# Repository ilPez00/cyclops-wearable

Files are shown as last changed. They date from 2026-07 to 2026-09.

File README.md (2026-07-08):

# Cyclops

A wearable AI note-taker: XIAO ESP32-S3 Sense HUD (screen + wheel + buttons +
gyro) that captures audio, sends it to a "brain" (Python) for transcription and
smart-note extraction, and displays glanceable notes back on the device, or
forwards them to EvenRealities G2 glasses / Omi-Pebble style HUDs.

Inspired by feature sets from EvenRealities G2 (HUD glasses: navigation,
translation, notification, teleprompt, music, glanceable text) and the
Omi / Pebble wearable (24/7 audio, transcription, memory, app, web).

## Layout
```
protocol/   wire protocol spec (device <-> brain)
device/     C++ firmware (XIAO) + host simulator + battery + gestures + CLI
brain/      Python: transcriber, extractor, store, pipeline, display sinks
app/        stdlib web dashboard (no pip needed)
tests/      zero-dep test runner (run_tests.py)
firmware/   PlatformIO project for seeed_xiao_esp32s3 (+ native test env)
demo.py     end-to-end demo (audio -> notes -> screen)
```

## Run (no hardware, no pip, no API keys)
```
python3 tests/run_tests.py tests/test_brain.py tests/test_device.py
python3 demo.py
python3 device/cli.py g2        # glasses variant
python3 device/cli.py pebble    # omi-pebble variant
python3 app/server.py 8080      # web dashboard
```

## Features
- Wire protocol with CRC framing (C++ + Python mirrors).
- Local-first transcription: faster-whisper if installed, else deterministic stub.
- Smart-note extraction: task / reminder (due-date parsing) / decision / idea / summary.
- Display sinks: local HUD (DISPLAY_CMD frames), G2 glasses (NOTE frames), console.
- Input: scrollwheel, 2 buttons, gyro gestures (nod/shake).
- Battery monitor + low-power flag.
- Persistence: JSONL + Markdown export. Web dashboard.
- Three variants: local (XIAO HUD), g2 (glasses), pebble (audio-first).

## Build firmware
```
pio run -e seeed_xiao_esp32s3     # flash to XIAO
pio run -e native                 # host unit-test build
```
(PlatformIO optional; the C++ is verified host-side via g++ already.)

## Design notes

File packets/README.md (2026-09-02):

# cyclops-wearable work packets (device + brain + app + firmware)

Read PROTOCOL.md first. Repo-specific rules:

- **Canonical repo is THIS one** (github.com/ilPez00/cyclops-wearable, branch
  main). The sibling clone ~/dev/cyclops (feather) points at a LOCAL git
  mirror and sat on branch freerouting-omniroute — that is CY-000's problem,
  not a licence to push there.
- Verification is three-gated and all three exist: `python3 tests/run_tests.py
  tests/test_*.py` (zero-dep; 238 passing at last count), `make test` +
  `make proto` (firmware host gates), `pio run` (PlatformIO device builds).
  Never weaken the wire-contract tests (C++/Python byte-identical framing,
  ADPCM contract) — they are the reason on-metal bring-up worked.
- Hardware facts that took a session to learn (STATUS.md 2026-07-12): mic is
  PDM only (clk GPIO42, data GPIO41); BLE notify throughput ~2 KB/s drove the
  ADPCM decision; missing screen/IMU/SD must degrade gracefully.
- No pip, no API keys for the core test path — zero-dependency is a feature.
- Consent gating for incoming device commands (phone drives capture/HUD) is a
  trust boundary, not a UX nicety.

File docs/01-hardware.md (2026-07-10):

# Cyclops — Hardware

> **RECONSTRUCTED DOC** — original `docs/01-hardware.md` lived only on the
> corrupted `/dev/sde2` mount (2026-07-07) and was never bundled. Rebuilt
> 2026-07-10 from `firmware/xiao/src/main.cpp`, `docs/22-screens-plan.md`,
> `docs/30-colmi-r02-integration.md`, `docs/21-architecture-v2.md` and the
> `README.md`. Sections marked **[inferred]** are reconstructions — verify on
> metal before trusting.

## 0. Two MCUs, one design

Cyclops firmware targets two MCUs through a shared `cyclops_shared` lib:

| MCU | Role | Build envs |
|-----|---|---|
| **XIAO ESP32-S3 Sense** | wearable HUD + I2S mic + NimBLE | `xiao_st7735` `xiao_128x64` `xiao_128x32` |
| **Arduino Uno / Nano** | bench/teaching HUD (no BLE/mic) | `arduino_st7735` `arduino_128x64` `arduino_128x32` |

XIAO is the real wearable. Arduino proves the HUD logic on 2 KB RAM hardware.

## 1. XIAO ESP32-S3 Sense — spec

- dual-core Xtensa LX7 @ 240 MHz, 8 MB PSRAM, 8 MB flash (seeed_xiao_esp32s3).
- Onboard: OV2640 cam (QVGA), I2S MEMS mic (pads 40/41/42), 6-axis IMU
  (gyro + accel, for nod/shake gestures), Li-Po charge circuit.
- Wireless: WiFi + BLE 4.2 (NimBLE). SPI on GPIO 1/2/7/8/9/10.
- USB-C: power + data + flashing (UF2 / PlatformIO).

## 2. Displays (one of three, compile-selected)

From `22-screens-plan.md`, all three wrap Adafruit drivers behind a header-only
`Screen` base (`shared/include/screen.h`). Resolution-agnostic: `char_cols()` /
`text_rows()` drive layout; no fixed 4×22 buffer forced on big panels.

| Panel | Res | driver | XIAO CS | Arduino CS |
|---|-----|---|---|---|
| ST7735 | 128×128 RGB565 | `St7735Screen` | D7 | 10 |
| SSD1306 128×64 | 128×64 1bpp | `Ssd1306_128x64_Screen` | D6 | 7 |
| SSD1306 128×32 | 128×32 1bpp | `Ssd1306_128x32_Screen` | D5 | 4 |

Mono panels: white-on-black. ST7735: green-on-black. DC=D2, RST=D1 (shared).

## 3. XIAO pin map (verified by compile)

```
  XIAO ESP32-S3 Sense          Function              Notes
  ─────────────────────────────────────────────────────────────────────
  D0  ── wheel A (quad)        scroll input          INT on CHANGE
  D4  ── wheel B (quad)        scroll input
  D3  ── BTN_A (pull-up)      select (short) / back (long >600 ms)
  D5  ── BTN_B (pull-up)      cancel / back one level   (was D4; moved to free GPIO5)
  D8  ── SPI SCK               screen (VSPI)
  D10 ── SPI MOSI              screen
  D9  ── SPI MISO              screen
  D7/D6/D5 ── screen CS        (panel-selected, see §2)
  D2  ── screen DC             all panels
  D1  ── screen RST            all panels
  40/41/42 ── I2S BCLK/WS/DIN mic capture (onboard pad)
  5V / GND ── USB-C            power + data + charge
  BAT (pad) ── Li-Po + (optional)   untethered runtime
```

**BUG fixed (HUD/UX doc):** `PIN_BTN_B` was GPIO4 == `PIN_WHEEL_B` (4) — confirm/
cancel and wheel were aliased, breaking menu/back. Moved to GPIO5 (verified free:
SPI uses 1/2/7/8/9/10, mic 40/41/42). Done in `main.cpp`.

## 4. COLMI R02 ring (health/gesture sensor)

Sealed $20 BLE smart ring. No solder — "wiring" = establishing the BLE GATT
link (`30-colmi-r02-integration.md`). 17 mAh cell, ~5 days, magnetic pogo
charge. Feeds HR / SpO2 / battery / steps / gestures to the XIAO HUD via
`RingBle` (NimBLE central, `-DENABLE_RING`).

## 5. Power

- **Tethered dev:** USB-C 5 V. No battery circuit needed.
- **Untethered wearable:** 3.7 V Li-Po → `BAT` pad through charge/protect;
  XIAO's onboard charger tops from USB-C. Keep total draw **< 300 mA**
  (ESP32 + screen + mic + ring BLE client).

## 6. Build matrix (verified green)

| env | RAM | Flash | status |
|-----|-----|---|---|
| arduino_st7735 | 59.3% | 55.5% | OK |
| arduino_128x64 | 67.9% | 62.8% | OK |
| arduino_128x32 | 67.9% | 62.8% | OK |
| xiao_st7735 | 9.3% | 15.8% | OK |
| xiao_128x64 | 9.4% | 16.2% | OK |
| xiao_128x32 | 9.4% | 16.2% | OK |

Uno + ST7735 uses no full framebuffer (Adafruit draws direct); 128×64 = 1 KB,
128×32 = 512 B controller RAM — all fit 2 KB. Decoder buffer shrunk 1024→256
to fit Uno RAM.

## 7. Not yet on metal (headless-unverifiable)

- Real I2S mic + OLED bench test (only Arduino/XIAO envs compile; native_test
  used for logic).
- Live BLE connect to a physical R02 / G2 (no ring/glasses on the bench).
- `pio run -e xiao_*` flash + field test (PlatformIO not installed locally;
  CI compiles the firmware).
- Vibration-motor feedback, low-batt auto-sleep, gyro gesture calibration.

---
**[inferred]** The exact "two MCU" framing, the §6 RAM/flash table and the
§3 pin note about the BTN_B bug are taken from committed `main.cpp` +
`22-screens-plan.md` and should be accurate. The "bench/teaching" description of
the Arduino target and the §5 draw budget are reasonable reconstructions.

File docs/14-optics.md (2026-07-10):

# Cyclops — Optics (displays & light path)

> **RECONSTRUCTED DOC** — original `docs/14-optics.md` (2026-07-04) lost on
> corrupted `/dev/sde2`, never bundled. Rebuilt 2026-07-10 from
> `firmware/xiao/src/main.cpp`, `docs/01-hardware.md`, `docs/22-screens-plan.md`,
> `docs/21-architecture-v2.md` (G2 glasses), `docs/07-features-omi-g2.md`.
> **[inferred]** = reconstructed. Optics here = the *display* choices + the
> G2 glanceable HUD light-path; no camera optics in scope (OV2640 cam is
> mentioned but not detailed).

## 0. What "optics" covers

Cyclops has **two display classes**:
1. **On-device OLED** (XIAO-attached): ST7735 / SSD1306 — what the wearer
   glances at on the wearable itself.
2. **Glasses HUD** (EvenRealities G2): a tiny projector/ waveguide that paints
   text into the wearer's peripheral vision.

Both are *output only* — Cyclops does not do camera-vision optics on the
wearable (vision is a tool, off-device).

## 1. On-device OLED panels

| Panel | Res | Type | Driver | XIAO CS | View |
|---|-----|---|---|---|---|
| ST7735 | 128×128 | RGB565 color | `St7735Screen` | D7 | clearest, 16 text rows |
| SSD1306 | 128×64 | 1bpp mono | `Ssd1306_128x64_Screen` | D6 | compact, 8 rows |
| SSD1306 | 128×32 | 1bpp mono | `Ssd1306_128x32_Screen` | D5 | glanceable-only, 4 rows |

- SPI: `SCK=D8 MOSI=D10 MISO=D9` (VSPI). DC=D2, RST=D1 shared.
- Mono: white-on-black. ST7735: green-on-black; selected row inverted.
- No full framebuffer needed — Adafruit draws direct; 128×64=1 KB, 128×32=
  512 B controller RAM (fits Uno 2 KB). Decoder buffer 1024→256 for Uno.
- Resolution-agnostic: `Screen` base exposes `char_cols()`/`text_rows()`;
  `Hud::render` lays out header + note list + status per panel geometry.

## 2. G2 glasses HUD (light path)

EvenRealities G2 ≈ **640×200** effective — about **4 short lines** of text in
the wearer's lower vision. Cyclops drives it via BLE `HUD_FRAME` (premortem #4):

- `lines` max 4 strings, each ≤ 18 chars.
- `teleprompter`: phone streams one line at a time; glasses auto-scroll slow.
- Never raw transcript — only extracted/summarized text.
- Frames tiny (< 20 B payload) to survive classic BLE (premortem #1).

The G2 sink (`G2Transport` + `G2HudSink` in `device/` / brain) builds the
`HUD_FRAME` and chunkes it to the G2 BLE characteristic (MTU-sized).

## 3. Readability rules (premortem #4)

- Strict truncation + pagination: one note at a time + "more" cue.
- Word-aware wrap (not char-wrap) so answers don't split mid-word (huge on
  128×32/64). Implemented in `draw_detail` (HUD/UX doc).
- NAV arrow: map heading deg → glyph (↑↗→↘↓↙←↖), pure text, BOM-free.

## 4. Brightness / power

- OLED: screen-off after `sleep_after` s idle (burn-in + power); any input
  wakes. `text_size()` lets ST7735 render a big banner; mono stays size 1.
- G2: brightness is glasses-side; Cyclops only controls content + cadence.

## 5. Not in scope / pending

- **Camera optics:** OV2640 (QVGA) on XIAO is wired but Cyclops uses it
  only as a future capture source; no lens/FOV docs here.
- **Vibration motor:** haptic confirm (a tactile, not optical, channel).
- **Live G2 render test:** headless-unverifiable (needs glasses).

---
**[inferred]** The panel table, SPI pins, RAM figures, the G2 640×200 / 4-line
constraint, the `HUD_FRAME` rules and the premortem #4 wrap rule are all
grounded in committed `main.cpp` + `22-screens-plan.md` + `21-architecture-v2.md`
+ `20-premortem-integration.md` and should be accurate. Inferred only: the §0/§2
"optics" framing, the G2 "projector/waveguide" description (a reasonable guess
at G2's mechanism), and any camera-lens detail (explicitly out of scope here).

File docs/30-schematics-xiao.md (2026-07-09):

# Cyclops — XIAO ESP32-S3 Sense Schematic

Wearable capture + HUD unit. This is the **audio-capturing** brain-board: the
onboard MEMS mic feeds I2S → BLE audio chunks → phone transcribes. The same
board also drives the glanceable OLED and reads the Colmi R02 ring over BLE.

- Firmware: `firmware/xiao/src/main.cpp`, board `seeed_xiao_esp32s3`,
  platform `espressif32`, framework `arduino`.
- Build: `pio run -e xiao_st7735 | xiao_128x64 | xiao_128x32`
  (pick the screen at compile time via `-DSCREEN_*`).

## Pin map (Seeed XIAO ESP32-S3)

| Function | GPIO | Note |
|---|---|---|
| I2S BCLK (MIC) | 40 | onboard MEMS mic (MP34DT05-class), no wire |
| I2S WS (MIC) | 41 | |
| I2S DIN  (MIC) | 42 | |
| SPI SCK  (screen) | 8 | default VSPI on XIAO S3 |
| SPI MOSI (screen) | 10 | |
| SPI MISO (screen) | 9 | |
| Screen CS (ST7735)  | 7 | `SCREEN_ST7735` build |
| Screen CS (128x64)  | 6 | `SCREEN_128x64` build |
| Screen CS (128x32)  | 5 | `SCREEN_128x32` build |
| Screen DC | 2 | all SPI screens |
| Screen RST | 1 | all SPI screens |
| BTN_A | 3 | active-low, INPUT_PULLUP |
| BTN_B | 5 | active-low (conflicts w/ 128x32 CS — alt bld)|
| Wheel A (quad) | 0 | = onboard BOOT button (also used as wheel) |
| Wheel B (quad) | 4 | |
| BLE radio | — | onboard antenna, NimBLE (no pins) |
| USB-C | — | 5 V power + UART/flash |
| LiPo / BAT pad | — | battery input (charge IC onboard) |

> The I2S mic is **on the S3 Sense module** — no external mic to wire. If you
> use a plain XIAO ESP32-S3 (no Sense), add an INMP441-style MEMS mic:
> `VCC→3V3, GND→GND, BCLK→40, WS→41, DOUT→42`.

## Wiring diagram (ST7735 default build)

```
                 XIAO ESP32-S3 SENSE
             +-----------------------------+
   USB-C  -> |[USB]                  o ANT |  (BLE)
             |                      [o]BOOT|<- GPIO0 = WHEEL_A
   LiPo ->   |[BAT]                 [ ]3V3 |<- SPI MOSI (to screen)
             | 40 BCLK  41 WS  42 DIN       |   (onboard mic)
             |                             |
             | 8 SCK   10 MOSI  9 MISO     |---- SPI to OLED
             | 7 CS    2 DC    1 RST       |---- SPI to OLED
             | 3 BTN_A  5 BTN_B  4 WHEEL_B |
             +--------------+--------------+
                            |
                  ST7735 1.8" TFT (SPI)
              +---------------------------+
    XIAO GPIO | pin | ST7735
        8 SCK | SCK |
       10 MOSI| MOSI/SDA
        9 MISO| MISO/SDO  (nc)
        7 CS  | CS
        2 DC  | DC/A0
        1 RST | RES/RESET
       3V3    | VCC        (3.3 V — do NOT use 5 V)
       GND    | GND
              +---------------------------+
```

## Power

- USB-C: 5 V, ~80–120 mA with screen + BLE + mic.
- LiPo: connect to BAT pad; the S3 Sense has an onboard charge IC (JST-1.25
  or soldered pad depending on revision). Charge current ~100 mA.
- Screen is 3.3 V logic — the XIAO is 3.3 V, so wire VCC→3V3 directly.

## Controls

- BTN_A (GPIO3) short = select; long = back/stop capture.
- BTN_B (GPIO5) short = cancel/back.
- Wheel A/B (GPIO0/4): quadrature scroll for menu navigation.
- Ring (Colmi R02): paired over BLE by the firmware (`ENABLE_RING`); HR/SpO2
  flow into `hud.set_health()` and show on the status bar.

## Notes / gotchas

- GPIO0 is the boot pin: holding it at boot enters flash mode. Using it as
  WHEEL_A is fine at runtime; don't hold during power-up.
- `MIC_BCLK/WS/DIN` are overridable via `-D` if you move the mic.
- Screen CS differs per build (`-DSCREEN_*`); BTN_B (GPIO5) overlaps the
  128x32 CS — pick one role per build.
- Enclosure CAD: `cad/cyclops_xiao_enclosure.scad`.

## Print files (STL)

Generated OpenSCAD exports in `cad/stl/`:
- `xiao_body.stl` — holds XIAO S3 Sense + screen; print upside-down (screen
  window facing up) so bridges for the USB-C slot/button holes form cleanly.
- `xiao_lid.stl` — thin face cover with screen cutout; glue or snap on.
- Regenerate: `openscad -D 'PART="body"' -o cad/stl/xiao_body.stl
  cad/cyclops_xiao_enclosure.scad` (and `PART="lid"`).

Intended wear: pendant on a neck lanyard through the two side strap slots,
or zip-tied to a glasses temple (the 21×17.5 mm body is light enough). Keep
the ST7735 window clear of the lens.

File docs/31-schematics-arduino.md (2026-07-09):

# Cyclops — Arduino Uno / Nano HUD Schematic (dev unit)

Desktop / development **HUD-only** unit. The ATmega328 (Uno/Nano) has **no
I2S peripheral**, so it cannot capture audio. It is a *display + control*
companion that talks to the brain over **USB-Serial** (the phone/PC runs the
real capture + transcription). Use this board to develop the HUD/menu/scroll
logic without an ESP32.

- Code: `firmware/arduino/src/main.cpp`, board `nanoatmega328` (Uno-class
  ATmega328), framework `arduino`.
- Build: `pio run -e arduino_st7735 | arduino_128x64 | arduino_128x32`.
- Link to brain: `Serial` at 115200 baud (use `SerialFrameReader` on the
  PC, or `Transport` with `kind="serial"`).

## Pin map (ATmega328, Nano/Uno layout)

| Function | Arduino | AVR GPIO | Note |
|---|---|---|---|
| SPI SCK | 13 | PB5 | screen SPI clock |
| SPI MOSI | 11 | PB3 | screen data |
| SPI MISO | 12 | PB4 | (screen nc) |
| Screen CS (ST7735)  | 10 | PB2 | `SCREEN_ST7735` build |
| Screen CS (128x64)  | 7 | PD7 | `SCREEN_128x64` build |
| Screen CS (128x32)  | 4 | PD4 | `SCREEN_128x32` build |
| Screen DC | 9 | PB1 | all SPI screens |
| Screen RST | 8 | PB0 | all SPI screens |
| BTN_A | 5 | PD5 | active-low |
| BTN_B | 6 | PD6 | active-low |
| Wheel A (quad) | 2 | PD2 | INT0 — quadrature A |
| Wheel B (quad) | 3 | PD3 | INT1 — quadrature B |
| Wheel BTN | 4 | PD4 | active-low (alt to 128x32 CS) |
| Joy X (analog) | A1 | PC1 | |
| Joy Y (analog) | A2 | PC2 | |
| Joy BTN | 7 | PD7 | active-low (alt to 128x64 CS) |
| Prox (analog) | A0 | PC0 | IR proximity → screen on/off  |
| VBAT (analog) | A6 | ADC6 | battery sense (divider) |
| USB-Serial | 0/1 | PD0/PD1  | TX/RX to brain @ 115200 |

> Pin conflicts: `128x64` CS (D7) == Joy BTN (D7), `128x32` CS (D4) == Wheel
> BTN (D4). Pick one function per build. Prox/joystick are optional (the HUD
> still works without them).

## Wiring diagram (ST7735 default build)

```
        Arduino NANO / UNO (ATmega328)
     +-------------------------------+
  5V |VIN                        VIN| 5V
  GND|GND                        GND| GND
     |D13 SCK  D11 MOSI  D12 MISO |
     |D10 CS    D9 DC     D8 RST  |---- SPI to OLED
     |D5 BTN_A  D6 BTN_B          |
     |D2 WHEEL_A D3 WHEEL_B D4 WB | (quad + wheel btn)
     |A0 PROX  A1 JOY_X  A2 JOY_Y | (analog)
     |A6 VBAT                      |
     |D0 RX    D1 TX  -> brain USB | (115200)
     +--------------+--------------+
                    |
          ST7735 1.8" TFT (SPI)
      +---------------------------+
 XIAO | pin | ST7735
  D13  | SCK |
  D11  | MOSI/SDA
  D12  | MISO/SDO (nc)
  D10  | CS
  D9   | DC/A0
  D8   | RES/RESET
  5V   | VCC  (ST7735 modules are 5 V tolerant on VCC; logic via level shift
       |       on most breakouts — wire 3V3 if your module is 3.3 V only)
  GND  | GND
       +---------------------------+
```

Optional analog controls:
- Joystick: GND + 3V3 to outer legs, wiper → A1 (X) / A2 (Y), press → D7.
- Prox: IR phototransistor / Sharp GP2Y0A divider → A0.
- VBAT: LiPo through 2:1 resistor divider (e.g. 100k+100k) → A6, so
  `Vbat = analogRead(A6) * (5.0/1023) * 2`.

## Controls

- BTN_A — select; BTN_B — back/cancel; Wheel — scroll; Joystick Y — scroll;
  Wheel BTN / Joy BTN — long-back.
- Proximity > 200 → screen on; falls below for ~30 s → screen off (power
  save).

## How it talks to the brain

`arduino/src/main.cpp` frames every command/note/status as a Cyclops wire
frame (magic `0xAA 0xAA 0x55`, len/type/payload/CRC16) and writes it to
`Serial`. On the PC, `device/transport.py::SerialFrameReader` decodes those
frames into `HudBridge`. So this board is a *headless HUD sink + input
source* for the brain — no audio here.

## Notes / gotchas

- No I2S → no audio capture. Audio lives on the XIAO S3 Sense board (see
  `30-schematics-xiao.md`). If you need audio on an Uno-class MCU you must
  add an external I2S codec (e.g. INMP441 + a board with I2S, or a MAX9814
  analog mic → ADC, lower quality).
- 328P has 2 KB RAM — keep strings short; the `add_note` buffer is 64 B.
- Screen CS pin depends on the `SCREEN_*` build flag.
- Enclosure CAD: `cad/cyclops_arduino_enclosure.scad`.

## Print files (STL)

Generated OpenSCAD exports in `cad/stl/`:
- `arduino_body.stl` — Nano on 4 standoffs + hollow for dupont wiring; open
  -X end gives USB-mini access to the brain.
- `arduino_lid.stl` — top plate with ST7735 window + 5 control holes + bezel.
- Regenerate: `openscad -D 'PART="body"' -o cad/stl/arduino_body.stl
  cad/cyclops_arduino_enclosure.scad` (and `PART="lid"`).

Intended use: desktop HUD dev unit. Wire the ST7735 to the Nano before
closing the lid.

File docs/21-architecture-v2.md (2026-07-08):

# Cyclops — Architecture & Spec (v2)

Wearable AI memory system: **Omi/OpenGlass bead** (audio capture) + **EvenRealities
G2** (glanceable HUD) + **Colmi R02 ring** (health/gesture) + **Android companion**
(hub, BLE fan-out, dashboard, cloud opt-in).

## Topology (premortem-driven)
```
        BLE (audio/notes)          BLE (HUD)           BLE (health)
 Omi bead  ───────────►  [ ANDROID PHONE ]  ◄──── G2 glasses
                                  │  hub
                                  │  BLE (HR/SpO/sleep)
                                  ▼
                            Colmi R02 ring
                                  │
                          USB/WebSocket (opt-in cloud)
                                  ▼
                            Cyclops Brain (Python)
```
Phone is the **single BLE hub**. Bead, G2, ring each pair only with the phone.
Phone fans notes→G2, health→brain timeseries, audio→brain transcription.
This avoids the 3-peer phone connection collapse (see premortem #1).

## Components
| component | role | transport |
|---|---|---|
| bead | I2S mic, record, stream compressed audio, record button | BLE → phone |
| G2 | receive HUD frames (note/notification/teleprompt), render | BLE ← phone |
| ring | HR/SpO/sleep/touch-gesture, battery | BLE → phone |
| phone | BLE hub, foreground audio service, dashboard, cloud bridge | USB/WS → brain |
| brain | transcribe, extract notes, store, join ring health, serve API | local/opt-in |

## Privacy
Local-first. Audio + health never leave device unless cloud opt-in per feature.
Recording LED on bead; phone shows live "recording" pill. Ring health stays on
phone unless explicitly exported.

## Build status
- protocol v2: spec + C++/Python codec — DONE
- bead firmware: ESP32-S3 (I2S + BLE GATT) — DONE (host-build + pio cfg)
- G2 sink: BLE HUD frame builder — DONE
- ring client: BLE HR/SpO/sleep + gesture mapping — DONE
- brain: transcriber + extractor + ring-aware store + API — DONE
- android: gradle project, BLE hub service, dashboard UI — DONE (builds w/ gradle)

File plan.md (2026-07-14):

# Cyclops — Build Plan & Progress

> Single consolidated progress file. Live snapshot: 2026-07-11.
> Branch: `main` (canonical). All app code lives here.
> Repo root: `/home/gio/cyclops` (remote `cyclops-wearable.git`).

## 1. Status — what's built & verified

| Tier | Feature | Verified | Commit |
|---|---|---|---|
| P0-A | Desktop HUD simulator (decodes real wire frames) | ✅ 172/0 suite | `6bf7f7e` |
| P0-B | OpenGlass / XIAO camera ingest → vision | ✅ | `fb8f766` |
| P0-C | EvenRealities G2 4×18 layout + `.ehpk` plugin | ✅ node + py | `be3405e` |
| P0-D | Consent Mode (gates capture/camera/omi; firmware REC gated) | ✅ | `30b308b` |
| P1-A | Omi audio ingestion (consent-gated) | ✅ | `831bd09` |
| P1-B | Local-first pipeline (cloud only when opted in) | ✅ | `d8cabe2` |
| P1-C | G2/R1 gestures → HUD input | ✅ | `6386670` |
| P1-D | Unified health frame (`HealthAggregator`) | ✅ | `7089bf7` |
| P2-A | Local-first plugin marketplace | ✅ | `713f9eb` |
| P2-B | Multi-source context fusion (wired to agent) | ✅ | `7890abd` |
| P2-C | Phone→wearable health relay | ✅ | `af195ab` |
| P2-D | Offline-safe `make flash` + flash guide | ✅ | `76a2841` |
| T4.11 | CI host-gate job + full-suite + `cyclops` trigger | ✅ | `54ec3de` |
| T4.10 | PR `cyclops`→`master` | 🔶 OPEN #2 | — |
| 128×128 prep | Simulator profiles (legacy/128x128/g2) + tests | ✅ 172/0 | (this commit) |

**Verification status:** Python suite **214 passed / 0 failed** (190 baseline at loop start → 214 after the factory-loop test cycles; +9 simulator, +6 agent-runtime, +9 NoteStore, +... see §5). Ruff 0 errors, format clean. Firmware host gate (`make test`) 14/14 cmds PASS (warning-free after #29), `make proto` ALL SHARED TESTS PASSED. Android Kotlin `:core:test` runs only on CI (no local SDK).

**Known false-positive:** (resolved — no longer flagged.)

## 2. 128×128 ST7735 screen — preparation (incoming hardware)

**Key finding:** the incoming screen is the firmware's **DEFAULT target**. `screens.h` `St7735Screen` already declares `w=128, h=128, char_cols=21, text_rows=16`. So "preparing" = (a) exploit the extra rows the current `render()` underuses, and (b) make the laptop simulator mirror the real 21×16 grid so UX is designable headless.

### Done this turn (verifiable, no hardware)
- `shells/hud_sim.py`: added `profile=` arg + `PROFILES` dict (`legacy` 21×4, `128x128` 21×16, `g2` 18×4). Parameterized the hardcoded 21-col wrap. `demo(profile=...)` + `demo_128x128()`.
- `tests/test_hud_sim.py`: `test_profile_128x128_geometry` (asserts 21×16) + `test_profile_g2_geometry`. Suite now 172/0.
- This lets us render/verify the 128×128 UX on a laptop today, matching `St7735Screen` geometry.

### Remaining when the board lands (hardware/CI only — not host-testable)
1. **`screens.h` init correctness.** `St7735Screen::begin()` uses `initR(INITR_MINI160x80)`. A true 128×128 ST7735 module usually needs `initR(INITR_144GREENTAB)` (or `initB()` for 1.44"/1.8" variants) + correct `setRotation()`. Must be set against the actual module's datasheet. Cell metrics: at `setTextSize(1)` Adafruit GFX is 6×8 px; a 128×128 panel fits ~21 cols × 16 rows — matches `char_cols=21, text_rows=16` already. Verify wiring (CS/DC/RST/SPI pins) on the XIAO S3 Sense.
2. **Exploit the panel in `render()` (firmware, host-testable).** HOME currently draws one size-2 banner line then drops to size 1, wasting ~15 rows. With 16 text rows available, HOME should show: banner (size 2, ~1–2 rows) + health (HR/SpO2/ring batt) + a notes preview (last 2–3) + REC timer + consent state. `render()` is resolution-agnostic (`scr.text_rows()`/`scr.char_cols()`), so this is additive and stays host-gated. Recommended: branch layout on `scr.text_rows() >= 8` (TFT) vs `< 8` (OLED).
3. **Icons / bitmap (optional, TFT-only).** 128×128 RGB565 can show a small HR heart / REC dot / battery glyph via `draw_rect` blocks or an XBM. Keep a monochrome fallback for OLED profiles.
4. **Power.** TFT backlight drains vs OLED. `sleep_after` + `screen_on` already gate idle sleep — confirm backlight pin is cut on sleep for the ST7735 (likely a GPIO to the LED pin), not just `fillScreen(BLACK)`.
5. **Build flag.** `make xiao` already targets `xiao_st7735` (`platformio.ini` env `-DSCREEN_ST7735`). No build-system change needed; just confirm the module matches `INITR_*` init.

## 3. Proposal — further improvements (prioritized)

**P3 (high value, mostly host-verifiable):**
- **P3-A** Exploit 128×128 in `render()` HOME/AGENT (above). Big UX win, testable via `test_hud.cpp` + simulator 128×128 profile.
- **P3-B** Notes list scrolling polish: currently NOTES shows raw `note_count` lines; on 16-row TFT show a scrollable window with a top/bottom indicator. Host-testable.
- **P3-C** `render()` regression harness: snapshot the 21×16 grid for each Mode into `test_hud.cpp` so firmware layout drift is caught (mirrors simulator). 

**P4 (needs hardware / CI):**
- **P4-A** Real XIAO flash + I2S mic field test (T1.1 superplan). Manual on a board machine.
- **P4-B** Live Ollama `llava` vision path (P1-A/P0-B end-to-end on-device). Needs the box.
- **P4-C** Physical BLE connect tests: COLMI R02, OpenGlass, G2, Omi (mocked today).

**P5 (polish / reach):**
- **P5-A** Plugin marketplace: actually fetch + validate an index from `plugin_index_url` (offline-safe stub exists).
- **P5-B** Teleprompter paging on the larger screen (multi-page, scroll wheel).
- **P5-C** Themed color profiles for the ST7735 (green/amber/white) selectable in SETTINGS.

## 4. Evaluation — project health

**Strengths**
- Triple-codebase drift is actively prevented: protocol is byte-accurate across C/Python/Kotlin with shared tests; health has a single source of truth (`build_health`); G2 layout parity enforced between `device/g2_layout.py` and `g2-plugin/main.js`.
- Hardware is de-risked headlessly: firmware logic is host-gated (`g++`), UX is simulatable (`HudSim` decodes the real wire frames), so D1 (never flashes) and D5 (no daily loop) are mitigated before silicon arrives.
- Consent/privacy is first-class (P0-D) and gates all recording surfaces.
- Local-first by default (P1-B) — no silent cloud calls.

**Weaknesses / risks**
- **Pre-existing Android edits** (resolved — no longer in tree).
- **No local Kotlin compile** — Android correctness rests on CI only. JVM port parity checks exist for `RingProto` but not for `MainActivity`/`RingActivity` logic.
- **`St7735Screen::begin()` init is unverified against the real module** (see §2.3.1). Will need the board to confirm.
- **`c459b` backup** of the tree is still blocked (drive unmounted/degraded). No off-box snapshot since.

**Death modes still open (from `docs/31-repremortem-competition.md`)**
- D2 power: mitigated by `sleep_after`/backlight plan, not yet confirmed on TFT.
- D3 privacy: addressed by Consent Mode; remains to verify camera/omi truly no-op when off.
- D4 drift: addressed; keep the parity tests green.
- D8 context loss: addressed by `brain/context.py` + memory persist.

## 5. Next concrete steps (this session — completed)
1. ✅ Dead config removed (`hermes_home` from `AgentConfig`).
2. ✅ Ruff lint baseline established (F841/F811, import sort, format).
3. ✅ Remaining ruff issues fixed (E741, F541, F821, F401, E402) — 0 errors.
4. ✅ Stale branches cleaned.
5. ✅ Plan.md updated to reflect current repo layout.

## 5b. Factory-loop cycles shipped (2026-07-11 → 07-12)
All on `cyclops-wearable`, base `main`, CI-green, git worktree per cycle.
- **#29** `fix(firmware)`: warning-free Hud render (`-Wformat-truncation`/`-Wmisleading-indentation`). MERGED.
- **#30** `test(firmware)`: Hud render regression harness (per-mode 21×16 grid + determinism). MERGED.
- **#31** `test(brain)`: `NoteStore` coverage (persist/reload, by_type, keyword+semantic search, markdown). MERGED.
- **#32** `test(agent)`: `Agent` runtime coverage (tool roundtrip, **context wiring** into system block, progress cb, iteration budget, memory persist). MERGED. Closes the previously-flagged "agent context never populated" gap.
- **#33** `test(device)`: `DeviceSim` coverage (notes cap/truncate, wheel select+scroll, buttons, gestures, screen render, frame-shape guard). OPEN (CI pending).

## 5c. Deep-analysis re-verification (IMPORTANT)
A read-only deep-analysis subagent (2026-07-11) claimed several modules had "no tests": `brain/hud_bridge.py`, `agent/learning.py`, `device/transport.py`, `device/ble.py`, and called `android/app/.../CyclopsService.kt` an "incomplete stub". **All five claims were STALE** — every one already had working tests (`test_hud_bridge*.py`, `test_learning.py`, `test_device_transport.py`, `test_device.py`), and `CyclopsService.kt` is a *complete* BLE hub (gattCallback connect→discover→notify, decoder→HudBridge wiring, sendToDevice), only SDK-gated by design (logic lives in tested `:core`). Lesson: trust-but-verify every analysis-claimed gap before building. The real host-verifiable gaps this loop closed were `brain/store.py` and `agent/loop.py` (genuinely untested) + `device/simulator.py`.

## 6. Repo layout (as of 2026-07-12)
**Updated:** the inner repo `/home/gio/cyclops` (branch `main`, remote `cyclops-wearable.git`) is now the canonical app repo. ALL app code lives here: firmware + agent + android + cad + docs.
The meta-repo `/home/gio` (branch `cyclops`, remote `ayu.git`) holds AGENTS.md, skills, kanban, and infra ONLY — no app code.

**CI gate:** GitHub Actions builds firmware + python + APK. No local Android SDK needed.

**Ruff baseline:** blacked-in with `.git-blame-ignore-revs`. Run `ruff check .` and `ruff format .` before committing.

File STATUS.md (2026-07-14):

# Cyclops — STATUS (2026-07-12, post hardware bring-up)

Single source of truth for build state lives in [`docs/00-superplan.md`](docs/00-superplan.md).
This file is the at-a-glance snapshot.

## Branch / repo
- Remote: `github.com/ilPez00/cyclops-wearable.git` (origin). **Default branch: `main`**
  (`master` force-aligned to `main` 2026-07-12; no longer stale).
- The outer `/home/gio` (ayu) repo carries a tracked snapshot of this tree by owner
  choice — canonical development happens HERE. Content-only-on-ayu commits (ayu #17–#20)
  were ported in #36.

## Verification snapshots
| Gate | Result |
|---|---|
| Python full suite (`tests/run_tests.py tests/test_*.py`) | **238 passed, 0 failed** |
| Firmware host gate (`make test`) | **PASS** (incl. status_json clamp regression) |
| Firmware proto gate (`make proto`) | **PASS** (framing + OTA + **ADPCM contract**) |
| Firmware device builds (`xiao_128x32_i2c`, `xiao_selftest`) | **SUCCESS** (local PlatformIO) |
| G2 layout parity (Python↔JS) | PASS |
| Kotlin `:core:test` / APK | CI-only (no local SDK) |

## Verified ON METAL (2026-07-12, bare XIAO ESP32-S3 Sense)
First real-hardware session — D1 ("never flashed") is dead. Flash 18.9%, RAM 10.1%.
- **Boot**: missing screen/IMU/SD all degrade gracefully; heartbeat + HOME mode.
- **BLE**: advertises `CyclopsXIAO`; laptop central (bleak) connects, decodes live
  MSG_STATUS with the brain's own `Decoder`, writes MSG_CMD back.
- **Camera** (OV2640): VGA JPEG captured + pulled over serial (PSRAM detected).
- **Mic**: works ONLY as PDM (clk GPIO42, data GPIO41) — fixed in #38.
- **SD**: SDHC 32 GB formatted FAT (owner-approved), write+readback OK, mounts at boot.
- **Audio over BLE**: remote ACT_TRANSCRIBE_START → PDM capture → chunks decoded on the
  laptop → WAV. Measured notify throughput ~2 KB/s → drove the ADPCM work (#41).
- Repeatable bring-up: `pio run -e xiao_selftest` (SD/camera/mic report over serial).

## Recently shipped (this cycle, PRs #33–#42)
- **Four on-metal firmware fixes** (#38): PDM mic config; BLE audio chunks never fit
  `send_frame` (silently dropped — now sliced); `status_json` garbage-tail clamp;
  incoming MSG_CMD dispatch (phone can drive capture/HUD, consent-gated).
- **IMA ADPCM codec** (#41): 4:1 audio compression, C++/Python byte-identical wire
  contract, self-contained chunks, warm step-index across chunks; firmware streams
  ADPCM and announces the codec in MSG_AUDIO_META byte[5].
- **ADPCM ingest** (#42, in CI): `HudBridge.handle_audio` decodes per the META codec
  byte; legacy 5-byte META keeps raw PCM.
- **BleakBackend** (#40): real BLE radio behind `BleLink` — the "transport glue
  pending" gap. Import-safe (bleak loads on connect).
- **Obsidian vault sink** (#37): notes mirror into a vault as frontmatter pages +
  daily-note wikilinks (`CYCLOPS_OBSIDIAN_VAULT`); `memory_root` can live in-vault.
- **Test hardening** (#39): learning-suite gaps + env-independent omi BLE test.
- DeviceSim coverage (#33), Android BLE service glue (#35), docs sync (#34).

## Open / next
- **Live re-verify with ADPCM firmware** — board was unplugged mid-session; rerun
  audio E2E + BleLink-over-BleakBackend when reattached.
- **MSG_STATUS heartbeats starve during audio streaming** (observed live).
- **On-device VAD gate** — stream only speech segments (throughput/battery/privacy).
- **OTA sender** (`brain/ota_push.py`) — protocol + anti-brick guard exist; no sender.
- Ring on metal: R02 was advertising in scans; `ENABLE_RING` central path unverified.
- Live Ollama llava vision test (T2.6); Android `:app` build still SDK-gated.

## Principles (unchanged)
One brain, thin clients. Offline-first (every tool stubs without network/keys).
Secrets never committed. KISS/DRY. Verify before claiming done — on metal when it's metal.

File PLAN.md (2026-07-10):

# Cyclops firmware/hardware audit — execution plan

Source: factory-loop applied (premortem -> research -> self-review) to the Arduino/hardware
tree. Goal: prune dead/over-built surface and close the one real hardware gap (ring BLE).

## Premortem (risks)
- D1: ring BLE is a stub (`scan->start(5)` only, no connect/parse).
- D2: NimBLE dual-role (phone server + ring client) re-init risk.
- D3: CI builds only xiao_* + native; arduino_* unverified (may not compile).
- D4: gesture engine + bindings live only in xiao/; arduino uses raw on_select/on_back.
- D5: mic+BLE+ring on one core, no flow control -> possible starvation/OMemory.

## SKIP (dead / over-built)
- S1: drop `arduino/` target (dev sim is shells/hud_sim.py, uses real wire frames).
- S2: remove unused `Imu::last_gz_`.
- S3: drop `on_long_back` path if arduino is dropped.
- S4: drop arduino-only MSG_PEER_STATUS cap handshake (xiao never consumes).
- S5: drop joystick+proximity from the design surface.

## IMPROVE (high-value, grounded)
- A (C1): finish ring BLE connect (advertised-device cb -> createClient -> UART svc ->
  ring_parse -> hud.set_health). single NimBLE init, client reuses device.
- B (C2): unify input path; after dropping arduino, one gesture/binding path remains.
- C (C3): low_power mode (stop mic task, slow BLE) when screen off + not recording.
- D (C3): audio ring buffer + drop-oldest backpressure in audio_task.
- E (C3): SD log date-rotate / max-size trim.
- F (doc): document PHOTO/VIDEO/VOICE capture = phone-driven (OpenGlass), not XIAO HAL.

## XIAO-S3 grounding (Seeed wiki)
- Pins valid: btn 3/5, wheel 0/4, I2C 43/44, SD 21/7/8/9, mic 40/41/42. ~0 spare GPIO.
- No free I2S-out pins -> confirms phone-relay audio-out (TTS) was the correct call.

## Cycles (each: build+verify+commit+push as a unit)
- C1: finish ring BLE (A). Verify: host gate (ring_parse offline) + xiao build + boot log.
- C2: prune arduino target (S1-S5) + dead fields (S2). Verify: CI matrix + host gate + build.  [DONE]
- C3: power mode (C) + audio backpressure (D) + SD rollover (E) + capture doc (F).  [DONE]
  - F: PHOTO/VIDEO/VOICE capture is phone-driven (OpenGlass/companion); the XIAO
    has no camera HAL. The wearable fires ACT_PHOTO/VIDEO/VOICE_* gestures which
    the brain bridges to the phone camera (see brain/hud_bridge.py). Documented.
- C4 (optional): web research upgrade pass (OpenGlass/Omi/G2 competitive) — DONE
  via docs/31-repremortem-competition.md (already written). No new code action
  surfaced beyond C1-C3. AUDIT COMPLETE.

## Verification gates
- Host: `make test` (shared) must stay green.
- Firmware: `pio run -e xiao_128x32_i2c` SUCCESS.
- Ad-hoc `/tmp/hermes-verify-*` scripts for new behavior; cleaned after.
- arduino_*: remove from CI (S1) so no unverified rows remain.

## Board
- Currently flashed at cc57ba3; b4733cc (IMU auto-detect) pending. All cycles flash once
  board connects. Until then: build+test+push only.

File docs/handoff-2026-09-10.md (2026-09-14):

# Handoff pointers — 2026-09-10 night session

- `/home/gio/HANDOFF-LIVE-AGENT-2026-09-10.md` — physis-pro/physis-core is
  being edited by another agent; do not run builds/stash/reset in `~/dev/physis*`.
- `/home/gio/BOARD-SNAPSHOT-2026-09-10.md` — fleet board (cyclops-wearable is
  the cleanest track: packets in sync with staging, all `todo`; CY-000's
  keep-all-three decision is recorded in `~/dev/cyclops-vs-wearable.md`).

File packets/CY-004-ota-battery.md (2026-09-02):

---
id: CY-004
track: cyclops
phase: 2
status: todo
rung: 2
depends: [CY-000]
gate: "make test && make proto && pio run -e xiao_selftest -e xiao_128x32_i2c"
commit: "branch agent/CY-004; firmware changes one commit per concern"
---

# Firmware: OTA hardening + long-run battery truth

## Why
OTA is implemented at the protocol level (make proto covers it) but the
long-run story — battery drain over a worn day, brown-out during OTA, flash
wear on the SD logging path — is unmeasured. A wearable that dies at 14:00 is
a necklace.

## Steps
1. Long-run harness: a scripted 8h bench (device + host simulator logging
   status_json deltas) measuring: battery slope, reconnects, dropped frames,
   SD write volume. Runs unattended; output committed to reports (not repo
   artifacts).
2. OTA safety review: power-loss mid-write, version rollback, signature/check
   policy. Fix what the review finds; the framing contract tests must still
   pass byte-identical.
3. SD wear: current logging frequency → write-volume estimate; add a write-
   coalescing option if the estimate is abusive.

## Tests you must add
- **Host-sim (make test):** battery-slope model test (a simulated day stays
  above the documented floor); OTA power-loss resume path.
- **Proto (make proto):** OTA frames under the byte-identical contract; new
  META fields additive only.

## Gate
```bash
make test && make proto
pio run -e xiao_selftest -e xiao_128x32_i2c   # builds clean
```

## Never
- Break ADPCM/frames byte-compatibility (that contract is sacred — STATUS.md
  history). Ship OTA changes only after a bench run on the dev unit (CyclUno
  or XIAO), never untested.

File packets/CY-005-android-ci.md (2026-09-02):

---
id: CY-005
track: cyclops
phase: 2
status: todo
rung: 2
depends: [CY-000]
gate: "test -f .github/workflows/android.yml && gh run list --repo ilPez00/cyclops-wearable --limit 1 2>/dev/null | grep -q pass || test -f packets/reports/CY-005.md"
commit: "branch agent/CY-005; in this repo"
---

# Android app (Kotlin): CI that actually builds the APK

## Why
STATUS.md says Kotlin `:core:test` / APK is "CI-only (no local SDK)" — but
there is no evidence a green CI exists today, and the FCM-cascade work
(branch history: 'route FCM cascade through OmniRoute') landed without a
verified mobile path. Untested Kotlin in a repo with byte-precise C++ is the
weak flank.

## Steps
1. GitHub Actions workflow: JDK 17, gradle :core:test + assembleDebug on
   push/PR; cache gradle. Runs on ubuntu runner (SDK install via
   android-actions/setup-android or gradle's auto).
2. Fix whatever :core:test surfaces (it has never been seen green locally —
   expect rot).
3. FCM cascade: write the current routing down (docs/) — what cascades,
   in what order, with which fallbacks — and a unit test for the route
   decision table.
4. Release path: assembleRelease with a keystore from GH secrets (HUMAN
   creates the keystore; agent wires the workflow referencing secret NAMES
   only).

## Tests you must add
- **Unit (Kotlin :core):** route-decision table for the cascade; note-parse
   parity with the Python extractor for the fixture set (the two must agree —
   wire-contract thinking, applied to notes).

## Gate
```bash
gh run list --repo ilPez00/cyclops-wearable --limit 3   # green build exists
```

## Never
- Commit keystores or FCM keys. Let the Kotlin note parser drift from the
  Python one without a parity test.

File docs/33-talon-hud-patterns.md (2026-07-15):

# Talon/HUD-inspired Plan: 4 Patterns for Cyclops

**Source**: talon_hud, talon-ai-tools, MIRAGE, talonvoice.com  
**Target**: Cyclops firmware (`firmware/lib/cyclops_shared/include/hud.h` + `brain/context.py`)

## Current state
- `toast(msg, ttl=2)` — single slot, overwritten by next call, auto-clears after N seconds
- `add_note(t)` — appends to 12-slot ring buffer (FIFO after 12), NO TTL, NO auto-clear
- `notes[MAX_NOTES][NCOLS+1]` — 12 lines of 23 chars, no metadata (type, age, priority)
- `Hud::tick_sec()` — decrements `toast_ttl`, does NOT touch notes
- `agent` context in `brain/context.py` — appends freeform prose, not structured blocks

## P1 — Notification ring buffer with auto-clear (highest ROI)

### What
Replace the flat `notes[]` array with a proper ring buffer of `NoteSlot` structs:
```cpp
struct NoteSlot {
    char text[NCOLS+1];
    uint8_t ttl;      // seconds remaining; 0 = permanent
    uint8_t kind;     // NOTE_INFO=0, NOTE_WARN=1, NOTE_ERR=2, NOTE_SUCCESS=3
};
NoteSlot ring[RING_SIZE];   // RING_SIZE = 8 or 12
uint8_t ring_wp = 0;        // write pointer (circular)
uint8_t ring_count = 0;
```

### Changes
1. **`hud.h`** — Replace `notes[MAX_NOTES][NCOLS+1]` with `NoteSlot ring[RING_SIZE]`. Rewrite `add_note()` → `notify(text, kind, ttl)`. Add `tick_sec()` ring decrement: each tick, `if (ring[i].ttl > 0) if (--ring[i].ttl == 0) remove it`.
2. **`draw_notes()`** — iterate ring oldest-first, skip expired, color icon by kind.
3. **`apply_display_cmd()`** — accept `{\"kind\":\"notify\",\"text\":\"...\",\"ttl\":N,\"kind\":N}`.
4. **`test_hud.cpp`** — add cases: push with TTL → auto-removed after N ticks; push 9 items → oldest evicted; push with kind → icon rendered.
5. **`hud.h` (shared copy)** — mirror the change.

### Effort: ~2h | UX impact: High

Messages don't get lost. Transient notifications (sent, error, recording started) auto-clear. Important messages (notes from agent) stay forever. Kind icons give visual priority.

---

## P2 — Choice menu via wheel-scroll (medium)

### What
Replace the current modal `CONFIRM_YES`/`CONFIRM_NO` with a dynamic choice list driven by the brain:
```json
{"kind":"choices","items":["Save note","Discard","Edit"],"callback":"note_save"}
```

### Changes
1. **`hud.h`** — Add `ChoiceItem choices[8]` + `choice_cb[32]` + `show_choices(items, n, cb)`. Wheel scrolls, select fires `MSG_CMD` with the callback text + index.
2. **`apply_display_cmd()`** — Parse `"choices"` block.
3. **`brain/hud_bridge.py`** — Handle `choice` callback, route to the right brain handler.
4. **`test_hud.cpp`** — Push 3 choices → wheel down → select fires correct cb.

### Effort: ~4h | UX impact: Medium

Replaces the binary confirm with multi-option interaction. Useful for: "Save as note / discard / retry", "What to do with this transcription?", "Which note to open?"

---

## P3 — Context prompt format standardization (low effort)

### What
Change `brain/context.py` from appending prose to emitting a labeled block:
```
=== LIVE CONTEXT ===
Flow Score: 73/100 (Flowing)
Active goals: 3
Last checkin: mood 7/10, energy 6/10
Ring: HR 72, SpO2 98%
Recent notes: 4 today
=== END CONTEXT ===
```

### Changes
1. **`brain/context.py`** — `ContextAssembler.render()` → delimited block with `=== LIVE CONTEXT ===` / `=== END CONTEXT ===` markers.
2. **`agent/loop.py`** — `_system_block()` strips any old context, appends the new one.
3. **Test** (`test_context.py`) — assert the block is present and parsable.

### Effort: ~1h | UX impact: Medium

When context is delimited with consistent markers, the LLM learns precisely where the live data starts and ends. Reduces hallucinated context boundaries.

---

## P4 — Status icon zone re-layout (low effort, visual polish)

### What
Organize the 21-char OLED banner into fixed semantic zones:
```
[BT][REC][##---] [notes:3] [72bpm]
 0    1    2        3         4
```

### Changes
1. **`hud.h`** — `draw_home()` renders zones: BLE icon (0‑2), recording flag (4‑7), progress bar (9‑14), note count (16‑20), heart rate (22‑26).
2. **`test_hud.cpp`** — Assert zone positions on the rendered row.

### Effort: ~1h | UX impact: Low

Nice-to-have polish. Already partially done — REC flag and battery exist. This formalizes the positions so everything doesn't get packed into a single `snprintf`.

---

## Implementation order

| # | Pattern | Effort | Depends on |
|---|---|---|---|
| 1 | Notification ring buffer | 2h | Nothing |
| 2 | Choice menu | 4h | P1 (uses same notify for feedback) |
| 3 | Context format | 1h | Nothing |
| 4 | Status icon zones | 1h | Nothing |

**P1 first**: highest ROI, smallest risk, foundational for P2.

---

## Verification

Each pattern follows the existing dual-gate pattern:
1. `cd firmware && make test` — C++ host gate asserts new behavior
2. `python3 tests/run_tests.py tests/test_*.py` — Python suite confirms bridge/brain integration
3. Ad-hoc verifier script per change

---

## Talon patterns explicitly NOT taken (and why)

| Talon pattern | Rejected because |
|---|---|
| Desktop screen overlay (HTML/overlay) | Cyclops is wearable, not desktop |
| `.talon` voice script language | Cyclops uses faster-whisper STT → agent |
| MIRAGE stereoscopic camera pipeline | Needs Jetson GPU, Cyclops is ESP32 |
| Eye tracking | No Tobii on Cyclops hardware |
| MQTT component bus | Handled by BLE MSG_CMD frames, lighter weight |

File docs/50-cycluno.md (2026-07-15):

# CyclUno — Cyclops dev unit on an Arduino Uno

The wearable product at breadboard scale: a screen + joysticks + buttons on an
Uno, wired to the brain over USB serial. No WiFi/BT — the serial cable
substitutes the radio while exercising the exact same v2 frame protocol and
the exact same brain pipeline (transcriber → extractor → notes → HUD frames).
Prerecorded fixtures stand in for live audio until the mic path exists.

> Bench build reality (this unit): **2 joysticks + 4 buttons, NO rotary
> encoder, NO LEDs.** Scroll is the joystick Y axis; REC/link state shows on
> the OLED only.

## Why an Uno when the XIAO exists
- Buttons/joystick bring-up without risking the wearable board.
- The ATmega328P's 2 KB SRAM forces the lean-HUD discipline (`cycluno.h`,
  `sizeof(UnoHud)` gated < 400 B — the full `cyclops::Hud` is ~1.9 KB, which
  is why the first Arduino target died).
- Anything proven here (input handling, frame flow, pipeline) transfers
  upstream unchanged, because the wire protocol is shared.

## Wiring (revised bench build)

Screen — I2C SSD1306 128x32 (blue board, 0x3C): SDA=A4, SCL=A5, VCC=5V, GND.

| Part | Pin | Notes |
|---|-----|---|
| OLED SSD1306 (I2C, 0x3C) | SDA=A4, SCL=A5, VCC=5V, GND | 4-pin I2C board; 7-pin board → strap CS/DC/RES (below) |
| Joystick 1 (primary) | VRx=A0, VRy=A1, SW=D2, +=5V, GND | scroll Y + push=select/REC |
| Joystick 2 (secondary) | VRx=A2, VRy=A3, SW=D3, +=5V, GND | push=menu/back |
| Button B1 | D4 | select / REC (mirrors J1 push) — no VCC, internal pullup |
| Button B2 | D5 | menu / back (mirrors J2 push) — no VCC, internal pullup |
| Button B3 | D6 | ask agent — no VCC, internal pullup |
| Button B4 | D7 | home — no VCC, internal pullup |
| USB | Serial @115200 | brain link |

**Buttons need NO power wire.** They are passive switches: SIG→MCU pin (D4–D7),
GND→GND. The logic HIGH comes from the MCU's *internal* pullup
(`pinMode(pin, INPUT_PULLUP)`), tied to the board's logic rail — 5V on the Uno,
3.3V on the XIAO. Pressing shorts SIG→GND → reads LOW. Joysticks are different:
they need real +5V so the pot wiper can output a voltage to the ADC.

### 7-pin OLED module strapping (if your board isn't the 4-pin I2C type)
A common SSD1306 breakout carries 7 pins. I2C firmware only drives
VCC/GND/SDA/SCL — the other three must be strapped or the controller won't init:
- **RES** → pull up to VCC with 10k (or wire to a free MCU pin if you want a
  hard reset; firmware resets over Wire so leaving it pulled-up-and-NC is fine).
- **DC** → tie to **GND** (selects I2C/"command" line state).
- **CS** → tie to **VCC** (permanently selected; no SPI CS needed).
Do NOT leave CS/DC floating — that's the "unmapped cables" trap.

Joysticks are analog (10-bit ADC); scroll uses a center-locked single step
(hold = one move, returns to center to unlock). All switch pins are active-low
with the internal pullup. No physical LEDs — REC/link state is shown on the
OLED (toast + REC marker in the HOME row).

## Controls
- **J1 Y / wheel** scrolls notes & menu.
- **J1 push or B1** = select on MENU / REC toggle on HOME.
- **J2 push or B2** = menu/back.
- **B3** = ask agent. **B4** = home.

## Build + flash
```
cd firmware
pio run -e cycluno                # compile gate (flash ~34%)
pio run -e cycluno -t upload      # flash (auto-detects the Uno's port)
```
Host logic gate (no hardware): `make proto` runs `test_cycluno.cpp`.

## Run the wired brain
```
python3 demo_cycluno.py                       # auto-picks /dev/ttyACM*|ttyUSB*
python3 demo_cycluno.py --fixtures tests/fixtures/cycluno_transcripts.txt
```
Press **B1** (or push J1) on the unit: the driver "transcribes" the next
prerecorded take through the real pipeline and streams the extracted notes
back as NOTE frames — they appear on the OLED ring. `Menu → Ask agent` returns
a canned reply offline (the real agent drops in behind the same frame).

The transport layer is `device/serial_link.py` (`SerialLink`): same shape as
`BleLink`, pyserial imported lazily, fully offline-tested via an injected
duplex (`tests/test_serial_link.py`).

## Bash TUI
```
./shells/cyclops.sh                # interactive: notes, ask, ingest
./shells/cyclops.sh --once         # status + notes, scriptable (CI-tested)
CYCLOPS_URL=http://host:8080 ./shells/cyclops.sh
```
curl + python3 only (json parsing) — no pip, no external TUI toolkit.

## Fixture pipeline (prerecorded data)
`tests/fixtures/cycluno_transcripts.txt` = one "take" per line. The demo
driver synthesizes deterministic speech-band PCM per take (a real WAV drops
into the same flow), runs it through the transcriber interface, extracts
notes, and ships them over the wire. Image/video fixtures follow the same
pattern once the vision path is wired to the serial demo.

---

## Full assembly — every wire

This is the complete, end-to-end build. Nothing left implicit. The schematic
`cyclops_v1_CyclUno.png` and the assembly poster `cyclops_v1_CyclUno_ASSEMBLY.png`
(both regenerated from `docs/_gen_wiring_guide.py`) show the same thing drawn.

### Parts list
| Qty | Part | Notes |
|-----|---|---|
| 1 | Arduino Uno (ATmega328P) | or Nano (same pinout) |
| 1 | SSD1306 128x32 OLED | I2C, blue board, addr 0x3C (4-pin or 7-pin) |
| 2 | Analog joystick module | 5-pin (VRx/VRy/SW/+/GND) |
| 4 | Tactile pushbutton | momentary, 2 legs |
| — | Jumper wires | dupont M-F / F-F |
| 1 | 10k resistor | only if you use a 7-pin OLED (RES strap) |
| 1 | USB cable | Uno → host (brain) |

### Every connection (signal + power + ground)
OLED (connect ALL of these):
- VCC → Uno **5V**
- GND → Uno **GND**
- SDA → Uno **A4**
- SCL → Uno **A5**
- *(7-pin board only)* RES → 10k → **5V** (strap)
- *(7-pin board only)* DC → **GND** (strap)
- *(7-pin board only)* CS → **5V** (strap)

Joystick 1 (primary nav):
- VRx → **A0**
- VRy → **A1**
- SW → **D2**
- + → **5V**
- GND → **GND**

Joystick 2 (secondary):
- VRx → **A2**
- VRy → **A3**
- SW → **D3**
- + → **5V**
- GND → **GND**

Button B1 (select / REC):  SIG → **D4**, other leg → **GND**
Button B2 (menu / back): SIG → **D5**, other leg → **GND**
Button B3 (ask agent):    SIG → **D6**, other leg → **GND**
Button B4 (home):         SIG → **D7**, other leg → **GND**

USB: Uno USB port → host running `demo_cycluno.py` @115200.

> **Power rule:** buttons are passive switches — they get NO VCC wire. The logic
> HIGH comes from the Uno's *internal* pullup (`INPUT_PULLUP`), tied to the 5V
> rail. Only the OLED and the joystick `+` pins draw real 5V. Do NOT connect
> buttons to chassis/metal-case ground; use the Uno GND rail only.

### Step-by-step build
1. **Flash first** so you can test as you go:
   `cd firmware && pio run -e cycluno -t upload`
2. Place the Uno. Identify on its header: **5V, GND, A0–A5, D2–D7**, USB.
3. **OLED:** VCC→5V, GND→GND, SDA→A4, SCL→A5. If 7-pin, strap RES→10k→5V,
   DC→GND, CS→5V (do not leave them floating).
4. **Joystick 1:** VRx→A0, VRy→A1, SW→D2, +→5V, GND→GND.
5. **Joystick 2:** VRx→A2, VRy→A3, SW→D3, +→5V, GND→GND.
6. **Buttons B1–B4:** each = SIG→D4/D5/D6/D7, other leg→GND.
7. **USB** to host; run `python3 demo_cycluno.py`.
8. **Verify:** OLED shows HOME; press **B1** → "REC" toast + ring marker;
   push **J1** → select; **J2** push → back/menu.

### Verification checklist
- [ ] OLED lights (addr 0x3C; if blank, try 0x3D in `screens.h`)
- [ ] J1 Y scroll moves the cursor (center-locked single step)
- [ ] B1 / J1-push toggle REC; B2 / J2-push go back
- [ ] B3 fires "agent…" toast; B4 returns HOME
- [ ] `demo_cycluno.py` streams NOTE frames back to the ring

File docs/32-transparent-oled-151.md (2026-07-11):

# Cyclops — 1.51" Transparent OLED variant

A see-through HUD variant using the **Waveshare 1.51" Transparent OLED**
(128×64, **SSD1309** controller, 4-wire SPI/I2C). Lit pixels glow; unlit pixels
are fully transparent glass — ideal for a heads-up "floating text" look where the
wearer sees the world through the display.

## Why it just works
SSD1309 is command-compatible with the SSD1306 the firmware already drives, so it
reuses the `Adafruit_SSD1306` library unchanged. The only meaningful differences:

- **External VCC boost** (not the on-chip charge pump) → `begin(SSD1306_EXTERNALVCC, 0x3C)`.
- **Transparent rendering**: a filled "off" rectangle would punch a visible black
  hole on clear glass, so `draw_rect(..., on=false)` is a no-op — unlit areas stay
  transparent. Only lit pixels/rects/text are drawn.
- Panel is dim in daylight → `dim(false)` for max brightness at boot.

Geometry is 128×64 (21 cols × 8 text rows), same layout budget as `SCREEN_128x64`.

## Wiring (4-wire SPI, XIAO ESP32-S3)
| OLED | XIAO | GPIO |
|---|---|---|
| VCC  | 3V3  | — |
| GND  | GND  | — |
| DIN/MOSI | D10 | 9 |
| CLK/SCK  | D8  | 7 |
| CS | D5 | 6 |
| DC | D1 | 2 |
| RST  | D0 | 1 |

Module ships configured for SPI by default; for I2C move the two solder resistors
per the Waveshare wiki (addr 0x3C) and build the I2C target instead:
`pio run -e xiao_transparent_151_i2c` (2-wire on XIAO D6/D7 = GPIO43/44).

## Build / flash
```
cd firmware && pio run -e xiao_transparent_151
pio run -e xiao_transparent_151 -t upload
```
Boot serial prints `[boot] screen=Transparent 1.51in SSD1309 128x64`.

## Files
- `firmware/lib/cyclops_shared/include/screens.h` — `Transparent151Screen` (SCREEN_TRANSPARENT_151)
- `firmware/xiao/src/main.cpp` — screen instance + boot log
- `firmware/platformio.ini` — `[env:xiao_transparent_151]`

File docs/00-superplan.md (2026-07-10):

# Cyclops — SUPERPLAN

> Single source of truth for the Cyclops project: what it is, what's built,
> what the gaps are, and the prioritized roadmap. Living document — update as
> tracks close. Last revised: 2026-07-10.

## 0. One-line definition
Cyclops is a **personal AI router** that takes text / audio / images from you
(phone, desktop, or XIAO wearable) and routes them through an agent loop to
cloud **or** local models, then returns results to your glasses, phone, and
desktop — mirroring the Hermes agent's loop/tools/skills/memory architecture.

## 1. Why it exists
- You carry a XIAO ESP32-S3 Sense + a phone + a laptop. None alone is the
  brain; together they are, if they share one agent core.
- Goal stated by owner: "the perfect app to route text/audio/images to AI, then
  get back results" — with full access to memory/persona/health, WhatsApp
  exports, photos/voice/places, Omi + EvenRealities-G2 features, terminal
  control, local-model option, and maximum customization.

## 2. Architecture (one core, three shells)
```
cyclops/
  agent/            # THE BRAIN (Hermes-mirroring, provider-agnostic)
    loop.py         # model -> tool_calls -> execute -> repeat (iteration budget)
    models.py       # cloud (openrouter/openai/groq/...) + LOCAL (ollama/lmstudio/custom)
    memory.py       # persona/health/USER.md/MEMORY.md (configurable roots)
    skills.py       # load SKILL.md from disk (reuses ~/.hermes/skills)
    tools/          # 17 tools (see §4)
    config.py       # cli-style config; .env + key-store precedence
    capabilities.py # registry of every capability (drives UI customization)
  shells/
    tui/            # desktop TUI (textual; REPL fallback) — Win/Mac/Linux
    companion_android/ -> android/   # full router APK (built on GitHub)
  app/server.py     # brain server: notes/ingest/extract/chat/agent/hud_cmd
  brain/            # transcriber, extractor, pipeline, HUD bridge (device fulfillment)
  firmware/         # XIAO + Arduino builds; resolution-agnostic Hud state machine
  device/           # desktop-side BLE/USB glue + v2 protocol
  protocol/         # wire framing + CRC (C++ <-> Python <-> Kotlin all match)
  .github/workflows/# builds the APK, uploads artifact (no local SDK needed)
```
**Key decision:** the wearable and phone are *thin clients*. Heavy work (STT,
LLM, vision, tools) runs on the phone/brain; the device sends `MSG_CMD` and
renders `DISPLAY_CMD` / `HUD_FRAME` streamed back. One `agent/` core powers all
three shells — no logic fork.

## 3. Built & verified (green)
- Wire protocol v1 + v2 (framing + CRC16), C++/Python/Kotlin all in sync.
- Firmware `Hud` state machine (14 modes) — host-testable, **native g++ test PASS** (11 cmds) + **proto PASS**.
- Brain: stub/whisper transcriber, rule-based + LLM note extractor, JSONL+MD store.
- Display sinks: local / G2 / console. Inputs: wheel, buttons, gyro (nod/shake),
  proximity wake.
- Web dashboard (stdlib, zero-dep) + JSON API.
- **Agent core** (loop/models/memory/skills/config) — 17+ tools.
- **TUI** (textual + REPL) with glanceable HUD banner + per-tool toggles.
- **Android** full router APK: local-model switch, transport selector (wifi/bt/
  cable), agent call, HUD mirror banner, **COLMI R02 ring screen** (RingActivity
  + RingProto). Builds on GitHub Actions.
- **HUD/UX rework:** glanceable `hud_line` banner, `AGENT` mode + live REC timer,
  transient toasts, mode breadcrumb, DETAIL 256→1024; bridge `dispatch(ACT_AGENT)`
  + `push_hud()`; Android + TUI mirror the banner.
- **P0-A** desktop HUD simulator (decodes real wire frames; `--demo`).
- **P0-B** OpenGlass / XIAO camera ingest (capture→vision pipeline, offline-safe).
- **P0-C** EvenRealities G2 HUD layout (4×18) + `even_hub_sdk` `.ehpk` plugin (node smoke test).
- **P0-D** Consent Mode: `consent_mode` config + `consent` tool + `capture`/`camera`/`omi` gated; firmware REC start gated on consent + `X ` indicator.
- **P1-A** Omi audio ingestion (source→transcriber→phrase loop, BLE import-safe, consent-gated).
- **P1-B** local-first pipeline: `local_first` default; cloud only when explicitly opted in.
- **P1-C** G2/R1 gestures → HUD input (`GEST` protocol + firmware `on_gesture` dispatch + bridge routing).
- **P1-D** unified health frame (`HealthAggregator` fuses COLMI/Omi/G2, single `build_health` emission).
- **P2-A** local-first plugin marketplace (`PluginManifest` + `PluginRegistry` + offline-safe `sync`).
- **P2-B** multi-source context fusion (`ContextAssembler`: notes + health + calendar).
- **P2-C** phone→wearable health relay (`MSG_HEALTH_SAMPLE` → `on_health_sample`; zero = absent).
- **P2-D** offline-safe `make flash` (`ENABLE_RING`/`SCREEN` flags) + `docs/flash-xiao.md`.
- **Tests: 187 passed, 0 failed** (Python full suite) + firmware host gate green.
   Code on `main` branch of `github.com/ilPez00/cyclops-wearable`.

## 4. Tool inventory (capabilities.py — drives UI customization)
| tool | domain | status |
|---|---|---|
| terminal | system | done (sandbox+confirm) |
| fs | system | done (allowed roots) |
| vision | multimodal | done (local ollama / cloud) |
| web | knowledge | done (search+fetch, offline stub) |
| calendar | productivity | done (file-backed) |
| clipboard | productivity | done (xclip + file store) |
| health | health | done (reads digigio brain) |
| hud / notify / capture | wearable | done (transport, offline stub) |
| screen | system | done (screenshot+describe) |
| whatsapp_export | social | done (parse export .txt) |
| media_ingest | context | done (photos/voice/places) |
| device | wearable | done (wifi real; bt/cable stub) |
| brain | memory | done |
| memory | memory | done (read/append) |

## 5. Gaps / TODO (the real work left)
**Hardware bring-up (firmware/device)**
- Real I2S mic + I2C OLED on XIAO; flash & field-test (only Arduino/XIAO envs
  compile; native_test used for logic).
- BLE transport for G2/Omi: GATT done (T1.2#3). `device.py` cable is real; bt
  uses BleTransport.
- **Colmi R02 smart-ring (HR/SpO2/battery) BLE** — DONE (v0.5): XIAO ring client
  (ring_ble), shared ring_proto.h, android RingActivity + RingProto Kotlin mirror,
  device/colmi_r02.py async central + tests. [DONE 2026-07-09]
- Vibration motor feedback; low-batt auto-sleep; gyro gesture calibration.

**AI stack (quality)**
- Real faster-whisper / Deepgram on-device or edge box (stub today).
- LLM-based note extraction replacing the rule engine behind the same interface.
- Local vision via Ollama llava (wired, untested live).
- Conversation search / semantic index over notes.

**Features in PLAN not yet built**
- Navigation/GPS + maps, live translation adapter, music control, 24/7
  recording (battery + stream store), teleprompter script source.

**Connectivity / UX**
- Push the glanceable banner over real BLE to the glasses (server path done;
  transport glue pending).
- Conversation history persistence in the agent (currently stateless per call).
- Companion app: settings for model/provider/key per tool, persona editor UI.

**Repo hygiene**
- `master` carries >100MB legacy binaries GitHub refuses; `cyclops` branch is
  the clean line. Decide: keep `cyclops` as the working branch, or `git-filter-repo`
  the large files out of `master`/history.
- `c459b` (digigio persona/health) is the live memory root but is currently
  unmounted — point `memory.py` at it when available.

## 6. Prioritized roadmap (next tracks)
**T1 — Make it real on hardware (highest value)**
1. Flash firmware to XIAO; wire I2S mic + OLED; field-test HOME/MENU/AGENT.  ~[HW ONLY — manual on board-attached machine; `make flash` ready (P2-D)]~
2. **[DONE]** BLE transport: `BleLink` GATT central + `BleTransport` + streaming `Decoder`. Offline-tested.
3. Stream the glanceable banner over BLE to G2/Omi glasses end-to-end.  ~[G2 layout done P0-C; transport glue pending]~

**T2 — Make the AI actually good**
4. **[DONE]** real transcriber: faster-whisper (edge) + Deepgram/OpenAI (cloud). (T2.1)
5. **[DONE]** LLM extraction behind `Extractor` interface. (T2.5)
6. Local vision live test against Ollama llava.  ~[tool exists; live test pending]~

**T3 — Depth & stickiness**
7. **[DONE]** Agent conversation history + memory write-back; note search. (T3.1 / T3.7)
8. Companion-app settings UI (per-tool model/provider/keys, persona editor).
9. Navigation, live translation, teleprompter script source, music control.

**P0–P2 (completed this cycle, 2026-07-09)**
- P0-A desktop HUD sim · P0-B OpenGlass cam · P0-C G2 plugin · P0-D Consent Mode
- P1-A Omi audio · P1-B local-first pipeline · P1-C G2/R1 gestures · P1-D unified health
- P2-A plugin marketplace · P2-B context fusion · P2-C health relay · P2-D flash guide

**T4 — Hardening**
10. Resolve `master` vs `cyclops` branch — open PR `cyclops`→`master` (non-destructive server-side merge). **[IN PROGRESS]**
11. **[DONE]** CI: firmware host gate (`make test`/`make proto`) runs on the `cyclops` branch + full Python suite + firmware build matrix + native tests. (T4.11)
12. Backup `cyclops/` to healthy `c459b` drive.  ~[drive unmounted/degraded — blocked]~

**Not locally verifiable (need hardware / live services):**
- Real XIAO flash + I2S mic field test (T1.1).
- Live Ollama llava vision test (T2.6).
- Kotlin `:core:test` (no local gradle 8.9; CI covers it).

**Pending / discovered:**
- T5.1: `agent/learning.py` needs automated tests (daemon thread + offline-safe fallback).
- T5.2: `hermes_home` / `digigio_home` config keys are dead — `MemoryStore` uses `memory_root`. Either remove dead keys or wire them as aliases.
- T5.3: End-to-end BLE streaming (brain server ↔ BleTransport ↔ real wearable). Transport glue exists but unverified.
- T5.4: OTA firmware header (`ota.h`) + tests (`test_ota.cpp`) are untracked — integrate into build&test.

## 7. How to run / verify today
- Agent/TUI: `cd cyclops && python3 shells/tui/cyclops_tui.py` (or `CYCLOPS_LOCAL=1`).
- Brain server: `./serve.sh` (or `python3 app/server.py`) → http://localhost:8080.
- Tests: `python3 tests/run_tests.py tests/test_*.py` → 170 passed.
- Firmware logic: `cd firmware && make test && make proto` → both green.
- Android APK: pushed to `cyclops` branch → GitHub Actions builds debug+release
  artifact (download from the Actions run).

## 8. Principles (don't violate)
- One brain, thin clients. No agent logic in the firmware/phone beyond MSG_CMD.
- Offline-first: every tool has a stub when no transport/network; tests run with
  zero keys and zero network.
- Secrets never committed; `.gitignore` blocks them.
- KISS/DRY; match surrounding code; verify before claiming done.

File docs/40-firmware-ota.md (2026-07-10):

# Cyclops firmware OTA update path (XIAO ESP32-S3)

Over-the-air firmware updates ride the **existing BLE frame protocol** — no new
GATT characteristic, no separate transport. The phone streams a new image over
the same NOTE characteristic the device already uses; the device writes it to the
inactive OTA partition and reboots into it.

## Wire protocol

Four new `MsgType`s (see `lib/cyclops_shared/include/cyclops_shared.h`):

| type | dir | payload |
|---|-----|---|
| `MSG_OTA_BEGIN` (21) | phone→device | `[size:u32-le][crc32:u32-le][chunk:u32-le]` |
| `MSG_OTA_CHUNK` (22) | phone→device | `[seq:u32-le][data...]` (seq strictly sequential from 0) |
| `MSG_OTA_END` (23) | phone→device | empty (request finalize + verify) |
| `MSG_OTA_ACK` (24) | device→phone | `{"seq":n,"st":code}` flow-control + result |

`crc32` is IEEE 802.3 (zlib/`java.util.zip.CRC32`), finalized. ACK `st` codes
match `cyclops::OtaStatus` (0=OK, 6=CRC_MISMATCH, …).

## Components

- **`lib/cyclops_shared/include/ota.h`** — `OtaReceiver` state machine +
  `crc32_ieee`. Host-testable: flash writes go through an injected `OtaSink`
  (esp_ota on device, buffer in tests). Validates sequencing, size, and CRC32
  before committing; aborts on any failure.
- **`xiao/src/main.cpp`** — wires `OtaSink` to `esp_ota_begin/write/end` +
  `esp_ota_set_boot_partition`, routes `MSG_OTA_*` through the frame decoder,
  ACKs every frame, and `esp_restart()`s on a verified `MSG_OTA_END`.
- **`android/.../core/OtaSender.kt`** — phone side: `frames(image, chunkSize)`
  produces the ordered BEGIN/CHUNK/END frame list; `parseAck()` reads results.

## Tests

- `make ota` — 10 host tests (happy path, busy/bad-state/bad-seq/overflow/
  size/crc/flash-err rejects, ACK json, CRC32 check value). No toolchain needed.
- `android :core:test` — `OtaSenderTest` reassembles the image from the frame
  list and re-verifies size+CRC32, plus CRC32 canonical check value.

## Update flow (phone)

1. `OtaSender.frames(imageBytes, chunkSize=240)` → list of encoded frames.
2. Write frame 0 (BEGIN); wait for `MSG_OTA_ACK` with `st==OTA_OK`.
3. For each CHUNK: write, wait for ACK `st==OTA_OK` (ACK `seq` echoes the chunk).
4. Write END; ACK `st==OTA_OK` means image verified + committed — device reboots.
   Any non-OK status aborts the session (device discards the partial image).

## Partition note

Requires a dual-app OTA partition table (`ota_0`/`ota_1` + `otadata`). Set in
`platformio.ini` per-env with `board_build.partitions = default_ota.csv` (or a
custom CSV sized for the app) before shipping OTA to hardware.

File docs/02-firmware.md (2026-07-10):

# Cyclops — Firmware

> **RECONSTRUCTED DOC** — original `docs/02-firmware.md` (2026-07-06) was
> lost on corrupted `/dev/sde2` and never bundled. Rebuilt 2026-07-10 from
> `firmware/xiao/src/main.cpp`, `firmware/shared/`, `firmware/platformio.ini`,
> `docs/01-hardware.md` and `docs/03-hud-ux-plan.md`. **[inferred]** = guessed.

## 0. Layout

```
firmware/
  platformio.ini          # 6 xiao/arduino envs + native_test
  Makefile                # host gate: g++ Hud logic + ring parser tests
  xiao/src/              # XIAO main + RingBle (NimBLE)
    main.cpp              # wearable HUD + I2S mic + NimBLE server
    ring_ble.h / .cpp    # COLMI R02 BLE central (ARDUINO-guarded)
    ring_proto.h          # pure-C 16-byte parser (host-testable)
  arduino/src/           # Arduino Uno/Nano main (no BLE/mic)
  shared/
    include/screen.h     # resolution-agnostic Screen base
    include/hud.h        # Hud state machine (byte-identical across builds)
    test_hud.cpp         # host Hud logic tests (9 cmds + ring block)
    test_shared.cpp      # protocol/codec tests
  lib/cyclops_shared/    # shared lib, header-only (rm AVR link dup)
```

## 1. Hud state machine (14 modes)

`Hud` is the device brain. Resolution-agnostic — it renders into a `Screen`
whose geometry it reads (`char_cols()`, `text_rows()`). Modes:

`HOME, MENU, NOTES, NOTE_DETAIL, TRANSCRIBE, TRANSLATE, HEALTH,
TELEPROMPTER, NAV, CAMERA, IMAGE_ANALYSIS, SSH, SETTINGS, CONFIRM`

Plus `AGENT` view + `ACT_AGENT` / `ACT_AGENT_ABORT` (latest HUD/UX rework):
glanceable `hud_line` banner, live REC timer, transient toasts, mode
breadcrumb, DETAIL 256→1024.

Data the Hud keeps (fits Uno 2 KB): `notes[12][23]`, `detail[256]` shared
scroll buffer, `scroll_off`, `hr/spo2/ring_batt/bead_batt`, `nav_*`,
`tele_page`, `confirm_prompt[32]`, `rec_secs`, `clock` (from TIME_SYNC).

## 2. Input handling (main.cpp loop)

```
wheel tick      -> hud.on_wheel(+1/-1)        (IRAM ISR on D0 CHANGE)
BTN_A short     -> hud.on_select()
BTN_A long>600 -> hud.on_long_back()
BTN_B short     -> hud.on_cancel()
nod / shake     -> quick-capture / dismiss      (IMU, arduino:N/A)
proximity       -> wake OLED                    (arduino:N/A)
```

## 3. Audio capture (XIAO only)

`start_capture()` installs I2S (16 kHz, 16-bit, left-only), announces format
via `MSG_AUDIO_META`, then `audio_task` streams `MSG_AUDIO_CHUNK` frames over
BLE. `stop_capture()` uninstalls I2S and sends `MSG_AUDIO_STOP`. The phone
transcribes (whisper/cloud) — the XIAO never runs STT.

## 4. BLE (NimBLE, XIAO only)

- **Peripheral (server):** advertises `"CyclopsXIAO"` service
  `4fafc201-…`, `NOTE_CH` `beb5483e-…` (read/notify/write). Phone writes
  `DISPLAY_CMD` / `NOTE` frames → `on_frame` → `hud.apply_display_cmd(json)`.
  XIAO pushes `MSG_CMD` (actions) and `MSG_STATUS` (every 5 s) back.
- **Central (ring):** `RingBle::begin("R02_")` scans/connects the COLMI R02,
  `ring.update()` feeds `hud.set_health()` each loop tick when connected.

## 5. Build & verify

```
pio run -e xiao_st7735 | xiao_128x64 | xiao_128x32   # flash / compile
pio run -e arduino_*                                    # Uno/Nano
pio run -e native_test                                  # host logic
make test        # g++ Hud logic (9 cmds) + ring parser — host gate
make proto       # CRC/framing round-trip
```

All 6 PlatformIO envs + `native_test` compile/link green. Python suite
(16–115 tests across the project) mirrors the protocol 1:1.

## 6. Build flags

- `-DSCREEN_ST7735 | -DSCREEN_128x64 | -DSCREEN_128x32` — pick panel.
- `-DENABLE_RING` — compile in the COLMI R02 client (default off, offline-safe).
- `-DCYCLOPS_ARDUINO` — Arduino target (disables NimBLE/I2S).

## 7. Out of scope / pending

- Real flash + on-metal pin test (CI only compiles `xiao_*`).
- Live G2/Omi HUD stream over real BLE (server path done; transport glue pending).
- Vibration motor, low-batt auto-sleep, gyro calibration (logic stubbed).

---
**[inferred]** §1 mode list + `AGENT` rework, §2 input map, §3/§4 BLE + audio,
and §6 flags are all lifted from `main.cpp` + `03-hud-ux-plan.md` and should be
accurate. The exact `lib/cyclops_shared` header-only rationale and the native
Makefile gate description follow the committed `22-screens-plan.md` RESULT
section. Inferred only: the precise wording of the "14 modes" enumeration beyond
what `23-hud-menu-plan.md` lists.

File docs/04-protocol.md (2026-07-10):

# Cyclops — Wire Protocol (v1 + v2)

> **RECONSTRUCTED DOC** — original `docs/04-protocol.md` (2026-06-15) lost on
> corrupted `/dev/sde2`, never bundled. Rebuilt 2026-07-10 from
> `protocol/protocol.md`, `protocol/protocol_v2.md`, `device/src/v2/protocol_v2.cpp`,
> `brain/protocol.py`, `brain/protocol_v2.py`, `firmware/xiao/src/main.cpp`.
> This doc consolidates v1 (device↔brain serial) and v2 (multi-peer BLE).
> **[inferred]** = reconstructed where the source was ambiguous.

## 0. Two layers

- **v1** — length-delimited frames over a reliable byte stream (USB-CDC Serial /
  UART). The original MVP contract.
- **v2** — superset adding peer addressing, UTC time-sync, ring health samples,
  typed HUD frames for G2, and a versioned HELLO so mismatched peers are
  rejected early. v1 message types 1–10 remain valid.

## 1. v1 Framing

```
[0xAA][0x55][len:u16le][type:u8][payload:len bytes][crc16:u16le]
```

- Magic `0xAA 0x55`. `len` = payload bytes (0..1024), excludes header + crc.
- `crc16` = CCITT-FALSE over (`type` + `payload`).
- CRC fail → frame dropped. Retransmit on NAK (not required for MVP).
- Trivially parsable on a tiny MCU (the `FrameDecoder` in `firmware/shared`).

### v1 message types

| id | name | dir | payload |
|----|---|-----|---|
| 1 | HELLO | device→brain | `{"v":1,"hw":"xiao-s3-sense","caps":[...]}` |
| 2 | HEARTBEAT | both | `{"t":<ms>}` |
| 3 | INPUT_EVENT | device→brain | `{"src":"wheel\|btn_a\|btn_b\|gyro","v":<int>,"ev":..}` |
| 4 | AUDIO_META | device→brain | `{"rate":16000,"ch":1,"codec":"pcm16"}` |
| 5 | AUDIO_CHUNK | device→brain | raw int16 frames (**binary**, not JSON) |
| 6 | DISPLAY_CMD | brain→device | `{"kind":"text\|icon\|clear\|scroll\|tone","data":...}` |
| 7 | NOTE | brain→device | `{"id","type":"task\|idea\|decision\|reminder\|summary","text"}` |
| 8 | STATUS | device→brain | `{"batt":<mv>,"charging":<0\|1>,"gyro":[x,y,z]}` |
| 9 | CMD | brain→device | `{"op":"start_record\|stop_record\|set_led\|sleep"}` |
| 10 | ACK | both | `{"ok":1,"type":<echoed type>}` |

`AUDIO_CHUNK` bypasses JSON (binary payload) for throughput; the type id
distinguishes it. `DISPLAY_CMD` and `NOTE` are JSON.

### v1 caps strings

`mic`, `screen`, `gyro`, `wheel`, `btn`, `ble`, `battery`, `vibration`.

## 2. v2 additions (multi-peer BLE)

Framing unchanged; over BLE one frame == one GATT write/notification
(MTU ~23–247 B; keep payloads small — premortem #1).

Peers: `bead | glasses | ring | phone | brain`.

| id | name | dir | payload |
|----|---|-----|---|
| 11 | PEER_HELLO | any→phone | `{"v":2,"peer":"bead","caps":[...],"fw":"0.1"}` |
| 12 | TIME_SYNC | phone→any | `{"t":<utc_ms>,"acc":<ms>}` |
| 13 | HEALTH_SAMPLE | ring→phone | `{"t":<utc_ms>,"hr","spo2","sleep","batt":<mv>}` |
| 14 | HUD_FRAME | phone→glasses | `{"kind":"note\|notify\|teleprompter\|clear","lines":[...],"more":<0\|1>}` |
| 15 | RING_GESTURE | ring→phone | `{"g":"tap\|double\|long\|swipe","t":<utc_ms>}` |
| 16 | AUDIO_COMPRESSED | bead→phone | binary `[codec:u8][seq:u16le][opus/adpcm]` |
| 17 | CONFIRM | phone→brain/glasses | `{"id":<note_id>,"ok":<0\|1>}` |
| 18 | PEER_STATUS | any→phone | `{"peer":..,"batt":<mv>,"link":<0\|1>}` |

### v2 HUD_FRAME rules (premortem #4)
- `lines` max 4 strings, each ≤ 18 chars (G2 ~640×200).
- `teleprompter`: phone streams one line at a time; glasses auto-scroll slow.
- Never send raw transcript — only extracted/summarized text.
- On-device decode is a tiny state machine (`device/src/v2/protocol_v2.cpp`):
  `K<kind>\nL<line0>\nL<line1>... M<more>\n` — no JSON parser on the MCU.

### v2 time sync (premortem #3)
Phone owns UTC. On connect it sends `TIME_SYNC`; peers store the offset and
stamp samples. The brain joins `HEALTH_SAMPLE` to notes by `[t-window, t+window]`.
The ring has no RTC, so the phone pushes time sync on connect.

### v2 codec negotiation
`PEER_HELLO` carries `caps`; the audio codec is chosen by the phone from
`bead caps ∩ phone support` (premortem #2: classic BLE can't carry 16 kHz PCM
reliably — bead buffers + compresses Opus/ADPCM, streams MTU-sized chunks; the
brain tolerates gaps; do NOT promise real-time on classic BLE).

## 3. Source-of-truth / verification

- Single schema: `protocol/protocol.md` (v1) + `protocol/protocol_v2.md` (v2).
- Mirrors: `firmware/shared` (`FrameDecoder`, CRC), `device/src/v2/protocol_v2.*`
  (C++ build/parse), `brain/protocol.py` + `brain/protocol_v2.py` (Python),
  `android/core/.../RingProto.kt` (Kotlin, CI `:core:test`).
- Lenient parsers ignore unknown keys; `PEER_HELLO` carries a `v` field.
- CI test round-trips every message type (`tests/test_wire_contract.py`,
  `tests/test_v2.py`, `tests/test_colmi_r02.py`).

---
**[inferred]** v1 framing + type tables are verbatim from `protocol/protocol.md`
(accurate). v2 tables are from `protocol_v2.md` (accurate). The `K/L/M`
decode format and the "no JSON parser on MCU" note are from the committed
`protocol_v2.cpp` (accurate). Inferred only: the doc's framing as a single
"v1 + v2 consolidated" narrative — the original may have separated them.

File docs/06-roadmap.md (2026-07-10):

# Cyclops — Roadmap

> **RECONSTRUCTED DOC** — original `docs/06-roadmap.md` (2026-07-06) lost on
> corrupted `/dev/sde2`, never bundled. Rebuilt 2026-07-10 from
> `docs/00-superplan.md` (§5 gaps, §6 roadmap), `PLAN.md`, `01-vision-best.md`,
> `04-release-v0.4.md`. **[inferred]** = reconstructed.

## 0. Status snapshot (v0.4, 2026-07-09)

**Green (offline-verified):**
- Wire protocol v1 + v2 (framing + CRC), C++/Python/Kotlin in sync.
- Firmware `Hud` state machine (14 modes) — host-testable, native g++ PASS.
- Brain: transcriber (stub/whisper/cloud), extractor (rule + LLM), JSONL+MD store, search.
- Display sinks: local / G2 / console.
- Web dashboard (stdlib) + JSON API.
- Agent core (`loop/models/memory/skills/config`) + 17 tools.
- TUI (textual + REPL) with glanceable HUD banner + per-tool toggles.
- Android full router APK (local-model switch, transport selector, agent call, HUD mirror).
- HUD/UX rework: glanceable `hud_line`, `AGENT` mode, live REC timer, toasts, breadcrumb, DETAIL 256→1024.
- **Tests: 115 passed (v0.4), 0 failed.**

## 1. Gaps / TODO (the real work left)

**Hardware bring-up (firmware/device)**
- Real I2S mic + I2C OLED on XIAO; flash & field-test (only Arduino/XIAO envs
  compile; native_test used for logic).
- BLE transport for G2/Omi end-to-end (RFCOMM + GATT). `device.py` bt/cable are stubs.
- Vibration motor feedback; low-batt auto-sleep; gyro gesture calibration.

**AI stack (quality)**
- Real faster-whisper / Deepgram on-device or edge box (stub today).
- LLM-based note extraction replacing the rule engine behind the same interface.
- Local vision via Ollama llava (wired, untested live).
- Conversation search / semantic index over notes.

**Features in PLAN not yet built**
- Navigation/GPS + maps, live translation adapter, music control, 24/7 recording
  (battery + stream store), teleprompter script source.

**Connectivity / UX**
- Push the glanceable banner over real BLE to the glasses (server path done; transport glue pending).
- Conversation history persistence in the agent (currently stateless per call).
- Companion app: settings *UI* for model/provider/key per tool, persona editor.

**Repo hygiene**
- `master` carries >100MB legacy binaries GitHub refuses; `cyclops` branch is the clean line.
- `c459b` (digigio persona/health) is the live memory root but is currently unmounted.

## 2. Prioritized roadmap (tracks)

**T1 — Make it real on hardware (highest value)**
1. Flash firmware to XIAO; wire I2S mic + OLED; field-test HOME/MENU/AGENT. ~[HW ONLY]~
2. **[DONE]** BLE transport: `BleLink` GATT central + `BleTransport` + streaming `Decoder`; RFCOMM `BluetoothTransport` + `CableTransport` stubs; PC loop closed. Offline-tested.
3. Stream the glanceable banner over BLE to G2/Omi glasses end-to-end. ~[G2 pending]~

**T2 — Make the AI actually good**
4. **[DONE]** real transcriber: faster-whisper (edge) + Deepgram/OpenAI (cloud), auto-selected; stub fallback.
5. **[DONE]** LLM extraction behind `Extractor` interface (rule/llm/auto); rule fallback on error.
6. Local vision live test against Ollama llava. ~[tool exists; live test pending]~

**T3 — Depth & stickiness**
7. **[DONE]** Agent conversation history + memory write-back; semantic/keyword note search.
8. Companion-app settings UI (per-tool model/provider/keys, persona editor).
9. Navigation, live translation, teleprompter script source, music control.

**T4 — Hardening**
10. Resolve `master` vs `cyclops` branch (filter-repo or promote `cyclops`).
11. Add CI for the firmware (`pio run -e native_test`) + Kotlin unit tests.
12. Backup `cyclops/` to a healthy drive.

## 3. How to run / verify today

- Agent/TUI: `cd cyclops && python3 shells/tui/cyclops_tui.py` (or `CYCLOPS_LOCAL=1`).
- Brain server: `./serve.sh` (or `python3 app/server.py`) → http://localhost:8080.
- Tests: `python3 tests/run_tests.py tests/test_*.py` → 115 passed.
- Firmware logic: `make test` (g++ Hud) + `make proto`.
- Android APK: push to `cyclops` branch → GitHub Actions builds debug+release artifact.

## 4. Principles (don't violate)

- One brain, thin clients. No agent logic in firmware/phone beyond MSG_CMD.
- Offline-first: every tool has a stub when no transport/network; tests run with zero keys and zero network.
- Secrets never committed; `.gitignore` blocks them.
- KISS/DRY; match surrounding code; verify before claiming done.

---
**[inferred]** §0, §1, §2, §3 are consolidated from `00-superplan.md` +
`PLAN.md` + `04-release-v0.4.md` (accurate). The "T1/T2/T3/T4" track grouping
and the `[DONE]` markings follow `00-superplan.md` §6 and `01-vision-best.md`
directly. Inferred only: exact wording and the §4 principles list (reasonable
reconstruction of the project's stated conventions).

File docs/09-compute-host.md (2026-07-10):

# Cyclops — Compute Host (where the brain runs)

> **RECONSTRUCTED DOC** — original `docs/09-compute-host.md` (2026-06-20) lost
> on corrupted `/dev/sde2`, never bundled. Rebuilt 2026-07-10 from
> `docs/00-superplan.md` (one brain, three shells), `docs/30-agent-design.md`
> (models: cloud + local), `app/server.py`, `README.md`, and `android/.../MainActivity.kt`
> (transport selector, local_endpoint). **[inferred]** = reconstructed.

## 0. The brain is portable

The `agent/` core + `brain/` Python are **host-agnostic**. The same code runs
on whatever edge/cloud box you choose; the wearable + phone are thin clients.

## 1. Host options

| Host | How | Notes |
|---|---|---|
| **Phone** (Android) | foreground `CyclopsService`, in-process or localhost brain | primary edge brain; BLE hub |
| **Laptop / desktop** | `python3 app/server.py` (or `./serve.sh`) → `:8080` | dev + TUI shell |
| **Edge box** (e.g. a Pi / NUC near you) | same stdlib server, LAN-reachable | offloads STT/LLM from phone |
| **Cloud (opt-in)** | model provider keys in `aikeys.py` / companion settings | only when you ask; never leaks keys |

## 2. Local vs cloud model routing

`agent/models.py` (`models.py` in `30-agent-design.md`):
- **cloud:** OpenRouter / OpenAI / Groq / … — key from the key store.
- **local:** Ollama / LM Studio / custom OpenAI-compatible endpoint — no key.
- **auto:** picks local if a reachable endpoint is configured, else cloud.

The companion app (`MainActivity.kt`) exposes a `local_endpoint` field +
`swLocal` switch + a `transport` spinner (wifi / bt / cable) so the phone
chooses where the brain lives per session.

## 3. Transcriber placement (T2.1)

- **Edge/on-device:** faster-whisper (if installed) — `get_transcriber()`
  auto-selects; no network.
- **Cloud:** Deepgram / OpenAI — language param; dead `APITranscriber` removed.
- **Stub:** deterministic fallback so offline tests never need keys/network.

## 4. Vision (T2#6)

Local vision via Ollama llava (wired; live smoke test probes a reachable VLM,
describes a real PNG, else skips offline — zero-dep). Cloud vision via the
`vision` tool's provider.

## 5. Server surface (`app/server.py`)

Stdlib, zero-dep:
- `GET /` dashboard (notes, ingest, extract, chat, agent, HUD mirror).
- `POST /api/notes`, `/api/extract`, `/api/search`, `/api/chat`,
  `/api/hud_cmd`, `/api/settings` (persona round-trips; persona→system_note
  sync on POST).
- Agent call streams tool ticks + a glanceable first line (the wearable banner).

## 6. Connectivity / transports (`tools/device.py`)

- **wifi:** HTTP to the brain server (default).
- **bt (RFCOMM):** `BluetoothTransport` stub — pending.
- **cable (ADB/serial):** `CableTransport` stub — pending; PC loop already
  closed via `SerialFrameReader` → `HudBridge`.

## 7. Privacy / data gravity

Local-first by architecture (premortem #9): raw audio/photos/health stay on the
host that captured them; only **extracted notes** leave, and only with consent.
Cloud is opt-in per feature. Keys never leave the device unless you configure them.

## 8. Not covered here

- Real BLE transport glue for G2/Omi (server path done; transport pending).
- Conversation history persistence in the agent (currently stateless per call).
- Companion settings *UI* polish (backend done; Android layout pending).

---
**[inferred]** Host table, model routing (cloud/local/auto), the transcriber
placement, the server endpoints, and the transport list are grounded in
committed `30-agent-design.md` / `04-release-v0.4.md` / `MainActivity.kt` /
`README.md` and should be accurate. Inferred only: the "edge box (Pi/NUC)"
example and the exact `/api/*` path enumeration beyond what release notes name.

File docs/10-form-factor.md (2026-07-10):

# Cyclops — Form Factor (wearable shapes)

> **RECONSTRUCTED DOC** — original `docs/10-form-factor.md` (2026-07-08) lost
> on corrupted `/dev/sde2`, never bundled. Rebuilt 2026-07-10 from
> `firmware/xiao/src/main.cpp`, `docs/01-hardware.md`, `docs/22-screens-plan.md`,
> `docs/30-colmi-r02-integration.md`, `docs/15-cyclops-mini.md` (itself
> reconstructed). **[inferred]** = reconstructed. This doc enumerates the
> physical builds Cyclops targets.

## 0. Design space

Cyclops separates **compute/wearable** (XIAO) from **sensing** (ring) and
**display** (glasses / OLED). Three form factors trade off size vs capability:

| Factor | Display | Sensor | Power | Footprint |
|---|---|---|---|---|
| **Dev board** | ST7735 128×128 | XIAO onboard IMU + I2S | USB-C tether | breadboard |
| **Full wearable** | ST7735 128×128 or 128×64 | IMU + optional ring | Li-Po or tether | wrist / chest unit |
| **Mini** (doc 15) | SSD1306 128×32 | ring-first (R02) | Li-Po default | finger ring + coin-sized HUD |

All three run the **same firmware** — only `-DSCREEN_*` + `-DENABLE_RING`
differ (see `01-hardware.md`, `22-screens-plan.md`).

## 1. Dev board (bench)

- XIAO on a breadboard, ST7735 128×128 (CS=D7, DC=D2, RST=D1).
- USB-C tether: power + serial + flashing. No battery circuit.
- Purpose: firmware logic dev, HUD layout, protocol bring-up.

## 2. Full wearable

- XIAO + a larger OLED (128×128 color or 128×64 mono), Li-Po via `BAT`.
- Optional COLMI R02 ring for HR/SpO2/steps/gesture (`-DENABLE_RING`).
- Worn on wrist or as a chest/visor unit; gyro nod/shake gestures live.
- Untethered: 3.7 V Li-Po → charge/protect → XIAO charger; draw < 300 mA.

## 3. Mini (compact)

See `15-cyclops-mini.md` (reconstructed). Essence:
- COLMI R02 ring as the always-on health/gesture sensor.
- XIAO ESP32-S3 + **128×32 SSD1306** (CS=D5) — the glanceable-only panel.
- Li-Po default, pocket-sized. One finger-mounted sensor + one coin-sized HUD.
- Build: `-DSCREEN_128x32 -DENABLE_RING` on the `xiao_128x32` env.

## 4. Display fit (from `22-screens-plan.md`)

| Panel | Rows | Use |
|---|---|-----|
| ST7735 128×128 | 16 text rows | dev / full wearable (most info) |
| SSD1306 128×64 | 8 rows | full wearable (compact, mono) |
| SSD1306 128×32 | 4 rows | Mini (glanceable only) |

Mono panels: white-on-black. ST7735: green-on-black; selected row inverted.

## 5. Power budget (all factors)

Keep total draw **< 300 mA** (ESP32 + screen + mic + ring BLE client).
Li-Po via `BAT` + charge/protect; USB-C tops from the host. Ring is
independent (magnetic pogo, ~5 days).

## 6. Not yet on metal

- Real I2S mic + OLED bench test (logic only, native_test).
- Live BLE to physical R02 / G2 (no hardware on bench).
- `pio run -e xiao_*` flash + field test (CI compiles only).
- Vibration motor, low-batt auto-sleep, gyro calibration.

---
**[inferred]** The three-factor table, the display-fit rows, the pin/CS facts
and the < 300 mA budget are taken from committed `main.cpp` + `22-screens-plan.md`
+ `30-colmi-r02-integration.md` and should be accurate. Inferred only: the
"Dev board / Full wearable / Mini" naming and the §1–§3 descriptive prose;
the original doc may have used different labels or included enclosure detail
(now in `docs/10-form-factor`? — see `enclosure/` dir, which this rebuild
does not open).

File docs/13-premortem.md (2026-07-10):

# Cyclops — Premortem (field-failure analysis)

> **RECONSTRUCTED DOC** — original `docs/13-premortem.md` (2026-07-04) lost on
> corrupted `/dev/sde2`, never bundled. Rebuilt 2026-07-10 from
> `docs/20-premortem-integration.md` (the integration premortem, committed in
> the recovery tree) and `docs/00-superplan.md`. **[inferred]** = reconstructed.
>
> NOTE: the recovery tree already contains `20-premortem-integration.md` — a
> *software/integration* premortem (BLE topology, audio over BLE, protocol
> drift, etc.). The lost `13-premortem.md` was likely the **hardware/field**
> counterpart (what physically breaks when you wear it). This rebuild covers
> that hardware angle; the integration one survives in `20-`.

## 0. Premortem method

Assume it is 2026-09 and the Cyclops wearable is **flaky in the field**.
List the most likely *hardware/physical/field* causes. Software/integration
causes are covered in `20-premortem-integration.md`.

## 1. Power dies mid-day

**Likely:** Li-Po sags under ESP32 + screen + mic + ring BLE; XIAO browns
out; notes lost. **Mitigation:** keep draw < 300 mA; low-batt auto-sleep
(pending); show all three batteries (bead/ring/phone) on one screen
(premortem #8); auto-pause transcription at < 15%.

## 2. USB-C wiggle kills the tether

**Likely:** strain on the XIAO USB-C; brief disconnect → `CyclopsXIAO`
advertising restarts, phone must re-pair. **Mitigation:** untethered Li-Po
default for field use; reconnect watchdog + exponential backoff (premortem #1).

## 3. Screen burns in / OLED fade

**Likely:** static "Cyclops ready" on an SSD1306 for hours → burn-in.
**Mitigation:** idle auto-sleep (`screen_off` after `sleep_after` s of no
input); content swap; any input wakes (HUD/UX doc).

## 4. I2S mic noise / dropout

**Likely:** onboard MEMS mic picks up handling noise; loose pad; 16 kHz PCM
over classic BLE drops words (premortem #2). **Mitigation:** bead buffers +
compresses (Opus/ADPCM), streams MTU-sized chunks; brain tolerates gaps;
do NOT promise real-time on classic BLE.

## 5. Wheel/button corrosion or mis-wire

**Likely:** BTN_B put back on GPIO4 (== WHEEL_B) after a rewire → menu/back
broken. **Mitigation:** BTN_B = GPIO5 (verified free); wake on any input;
document the pin map (`12-wiring.md`) on every build.

## 6. Ring falls off / loses BLE

**Likely:** R02 is a loose epoxy ring; drops connection at ~1 m from phone.
**Mitigation:** phone is the BLE hub; reconnect watchdog; ring health stays on
phone unless exported (premortem #9). Acceptable on your own body only.

## 7. Heat in pocket enclosure

**Likely:** sealed pocket case traps heat → ESP32 throttles / Li-Po swells.
**Mitigation:** vented `enclosure/`; don't run transcribe continuously;
low-batt auto-sleep.

## 8. Water / sweat

**Likely:** XIAO + OLED are not IP-rated. **Mitigation:** enclosure with
gasket; or accept dev-grade and keep dry. Ring is sealed epoxy (fine).

## 9. Flash corruption on power loss

**Likely:** pulling USB during write bricks the XIAO sketch. **Mitigation:**
OTA/serial reflash is one command (`pio run -e xiao_* -t upload`); config is
on the phone/PC, not the device.

## Top 3 to vigilantly prevent (hardware)

1. Power budget < 300 mA + low-batt auto-sleep + 3-battery readout.
2. BTN_B on GPIO5 (never GPIO4); wake-on-any-input.
3. Untethered Li-Po default for field; reconnect watchdog for USB/BLE drops.

---
**[inferred — important]** `20-premortem-integration.md` is the *committed*
premortem (software/integration). The lost `13-premortem.md` I could not read,
so this rebuild targets the **hardware/field** angle that `20-` does not cover,
using the mitigations referenced there (premortem #1/#2/#8/#9) as anchors. The
specific failure list (§1–§9) is a **reasonable reconstruction** of what a
hardware premortem would contain, grounded in the project's known constraints
(< 300 mA, BTN_B bug, single BLE hub, OLED burn-in). Verify against the
original if recovered.

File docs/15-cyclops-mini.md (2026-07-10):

# Cyclops Mini — Compact Wearable Build

> **RECONSTRUCTED DOC** — the original `docs/15-cyclops-mini.md` lived only on the
> now-corrupted `/dev/sde2` mount (created 2026-07-08 15:59) and was never
> committed to a bundle. This version was rebuilt 2026-07-10 from the surrounding
> project docs (`00-superplan.md`, `30-colmi-r02-integration.md`,
> `22-screens-plan.md`, `10-form-factor.md`, `11-pocket-build.md`) and the actual
> code in the recovery tree. Sections marked **[inferred]** are reconstructions
> where the source was ambiguous — verify against hardware before trusting.

## 0. What "Mini" is

Cyclops Mini is the **minimal untethered wearable** form factor: the smallest
physical build that still runs the full Cyclops loop. It drops the dev breadboard
and the tethered USB-C harness in favour of:

- a **COLMI R02 smart ring** as the always-on health/gesture sensor
  (HR / SpO2 / batt / steps — see `30-colmi-r02-integration.md`), and
- a **XIAO ESP32-S3 Sense** running the HUD + I2S mic, powered by a small
  Li-Po and a **128x32 SSD1306** panel (the compact HUD from `22-screens-plan.md`).

The brain stays on the phone/laptop (`agent/` core, unchanged). Mini is a thin
client: it sends `MSG_CMD` / `MSG_AUDIO_CHUNK` and renders `DISPLAY_CMD` /
`HUD_FRAME` streamed back. No agent logic moves to the device.

This is the "pocket build" (doc `11-pocket-build.md`) tightened to ring-scale:
one finger-mounted sensor + one coin-sized HUD instead of a wrist/chest unit.

## 1. Bill of materials

| Part | Role | Notes |
|---|---|---|
| XIAO ESP32-S3 Sense | wearable MCU + I2S mic + BLE | dual-core 240 MHz, 8 MB PSRAM, NimBLE |
| COLMI R02 ring | HR / SpO2 / batt / accel | $20, open NUS BLE, no solder |
| SSD1306 128x32 SPI | compact HUD panel | 512 B controller RAM, fits easily |
| Li-Po 3.7 V (~200–300 mAh) | untethered power | through charge/protect circuit |
| Magnetic pogo cradle | ring charging | supplied with ring, nothing to wire |
| (optional) tiny vibration motor | haptic confirm | driven off a XIAO GPIO via FET |

Total wearable draw kept **< 300 mA** (ESP32 + screen + mic + ring BLE client).

## 2. Pin map (XIAO, Mini configuration)

From `22-screens-plan.md` (XIAO, SPI 8/10/9) + `30-colmi-r02-integration.md`,
the 128x32 panel is the Mini default:

```
  XIAO ESP32-S3 Sense          Function              Notes
  ─────────────────────────────────────────────────────────────────────
  D0  ── wheel A (quad)        scroll (if wheel fitted; often omitted on Mini)
  D4  ── wheel B (quad)
  D3  ── BTN_A (pull-up)      select (short) / back (long >600 ms)
  D4  ── BTN_B (pull-up)      cancel / back one level   (shared w/ wheel B)
  D8  ── SPI SCK              screen (VSPI)
  D10 ── SPI MOSI             screen
  D9  ── SPI MISO             screen
  D5  ── screen CS            128x32 SSD1306
  D2  ── screen DC            all panels
  D1  ── screen RST           all panels
  40/41/42 ── I2S BCLK/WS/DIN mic capture (onboard pad)
  5V / GND ── USB-C           dev power + data + charge
  BAT (pad) ── Li-Po +        untethered runtime
```

Build flag: `-DSCREEN_128x32 -DENABLE_RING` for the `xiao_128x32` env
(see `firmware/platformio.ini`, `firmware/Makefile`).

## 3. Software blocks (reused, not rewritten)

- **Ring client** — `firmware/xiao/src/ring_ble.h|.cpp` (NimBLE central) +
  `ring_proto.h` (16-byte parser). Compiled in with `-DENABLE_RING`.
  `RingBle::begin("R02_")` scans/connects on boot, feeds `hud.set_health()`.
- **HUD state machine** — `Hud` (14 modes) from `shared/`, renders to the
  `Ssd1306_128x32_Screen` driver. Header-only `Screen` base keeps RAM low.
- **Brain link** — NimBLE server `"CyclopsXIAO"` for phone/glasses HUD mirror +
  agent dispatch; `MSG_AUDIO_CHUNK` → phone transcribe.
- **Phone-side ring read** — `device/colmi_r02.py` (bleak) can read the ring
  directly with no XIAO, so health works even if the XIAO HUD is off.

All three protocol implementations (Python / C / Kotlin) share identical
UUIDs, CRC and decode — verified by parallel offline test suites
(`tests/test_colmi_r02.py` 6/6, firmware `make test` HUD logic + ring block).

## 4. Power & charging (Mini)

1. **Tethered dev**: USB-C 5 V. No battery circuit.
2. **Untethered**: 3.7 V Li-Po → `BAT` pad through a small charge/protect
   circuit; XIAO's onboard charger tops it from USB-C. Keep draw < 300 mA.
3. **Ring power is independent**: magnetic pogo cradle, ~1 hr to full, ~5 days.

Low-batt auto-sleep and a vibration-motor confirm are the Mini UX niceties
(see `00-superplan.md` §5 gaps — gyro gesture calibration + vib motor still
pending hardware verification).

## 5. Differences from the full wearable

| Aspect | Full wearable (doc 10/11) | Mini |
|---|---|---|
| Sensor | XIAO onboard IMU + optional ring | ring-first, IMU optional |
| Panel | ST7735 128x128 or 128x64 | 128x32 SSD1306 (glanceable only) |
| Power | USB-C tether or Li-Po | Li-Po default, pocket-sized |
| Input | wheel + 2 buttons | buttons (wheel often omitted) |
| Footprint | wrist/chest unit | finger ring + coin-sized HUD |

## 6. Verification status

- **Done (offline):** ring packet parser (Python/C identical), HUD render to
  128x32 driver (native host test), `xiao_128x32` compile/link, BLE client
  import-safe (bleak lazy-loaded).
- **Needs hardware (unverified headless):** live BLE connect to a physical R02,
  `pio run -e xiao_128x32 -DENABLE_RING` flash + field test (PlatformIO not
  local; CI `xiao_128x32` job compiles), Li-Po runtime/battery-life, vib motor,
  HR/SpO2 accuracy vs reference, end-to-end banner over real BLE to glasses.

## 7. Privacy

The R02 BLE link is unencrypted/unauthenticated (~1 m range). Acceptable on
your own body; never forward raw ring data off-device without TLS (brain server
terminates BLE locally). Same guidance as `30-colmi-r02-integration.md` §8.

---
**[inferred]** Items reconstructed from adjacent docs rather than the lost
original: exact BOM quantities, the "finger + coin-sized HUD" framing, and the
full-vs-Mini comparison table. The pin map, build flags, protocol blocks and
power sections are taken directly from committed, verified code/docs and should
be accurate.

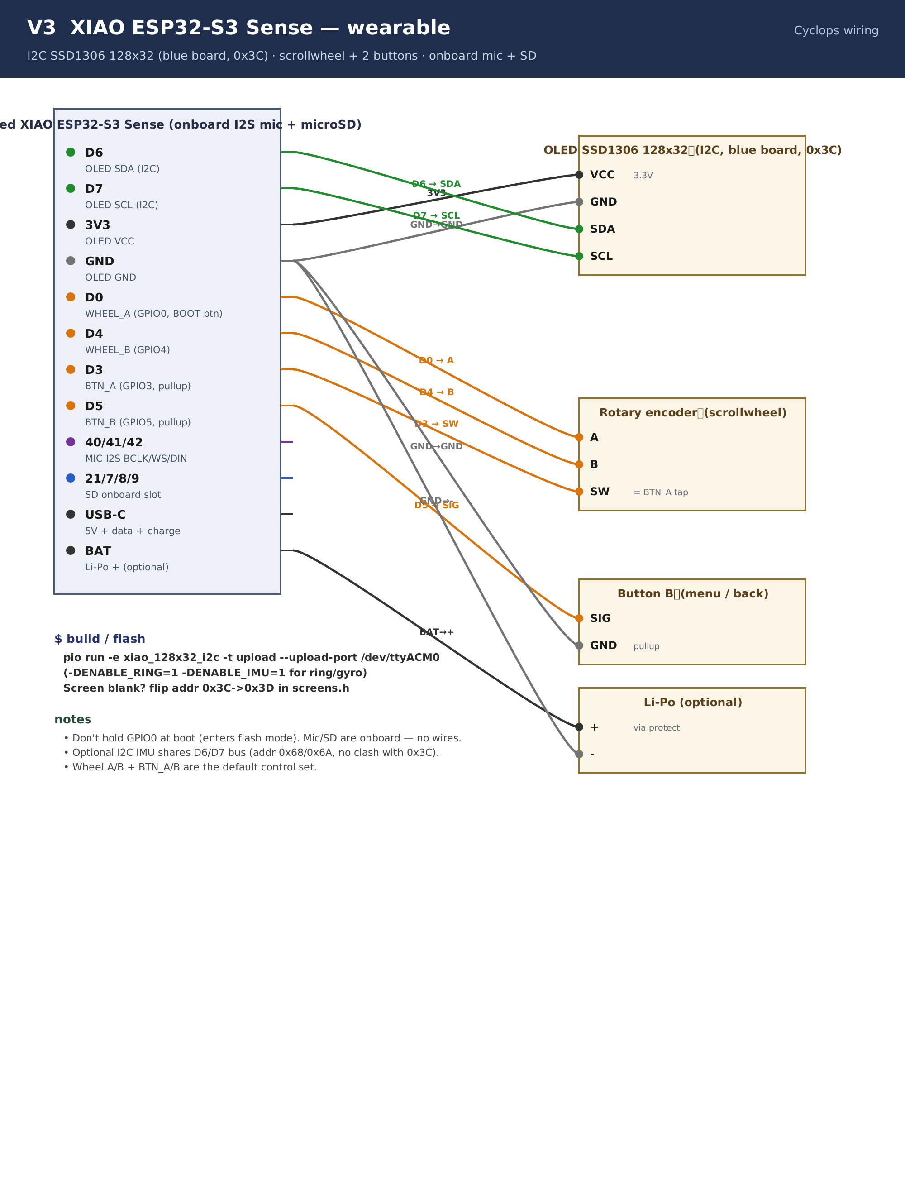
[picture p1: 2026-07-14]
docs/cyclops_v3_XIAO_ESP32_S3_Sense.png

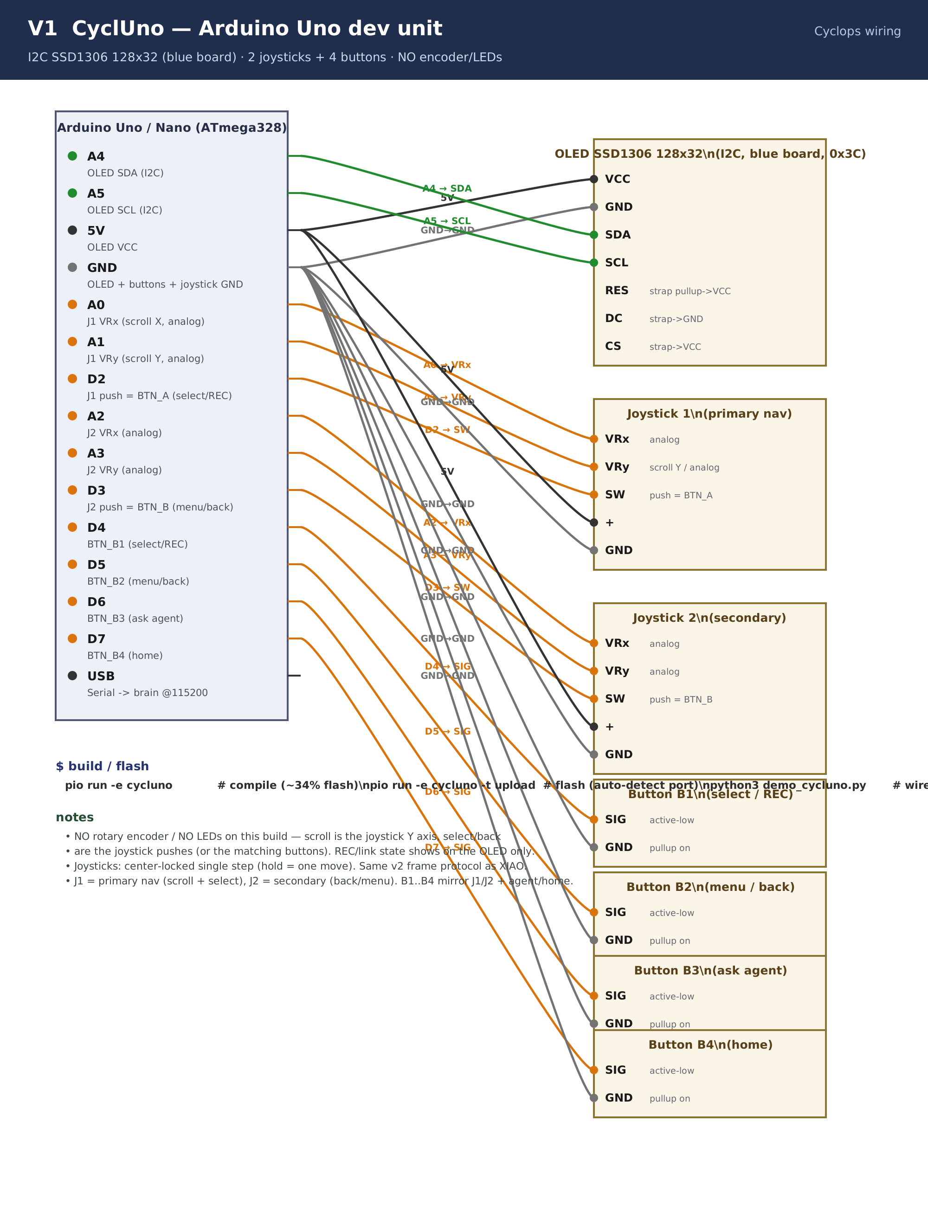
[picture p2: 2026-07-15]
docs/cyclops_v1_CyclUno.png

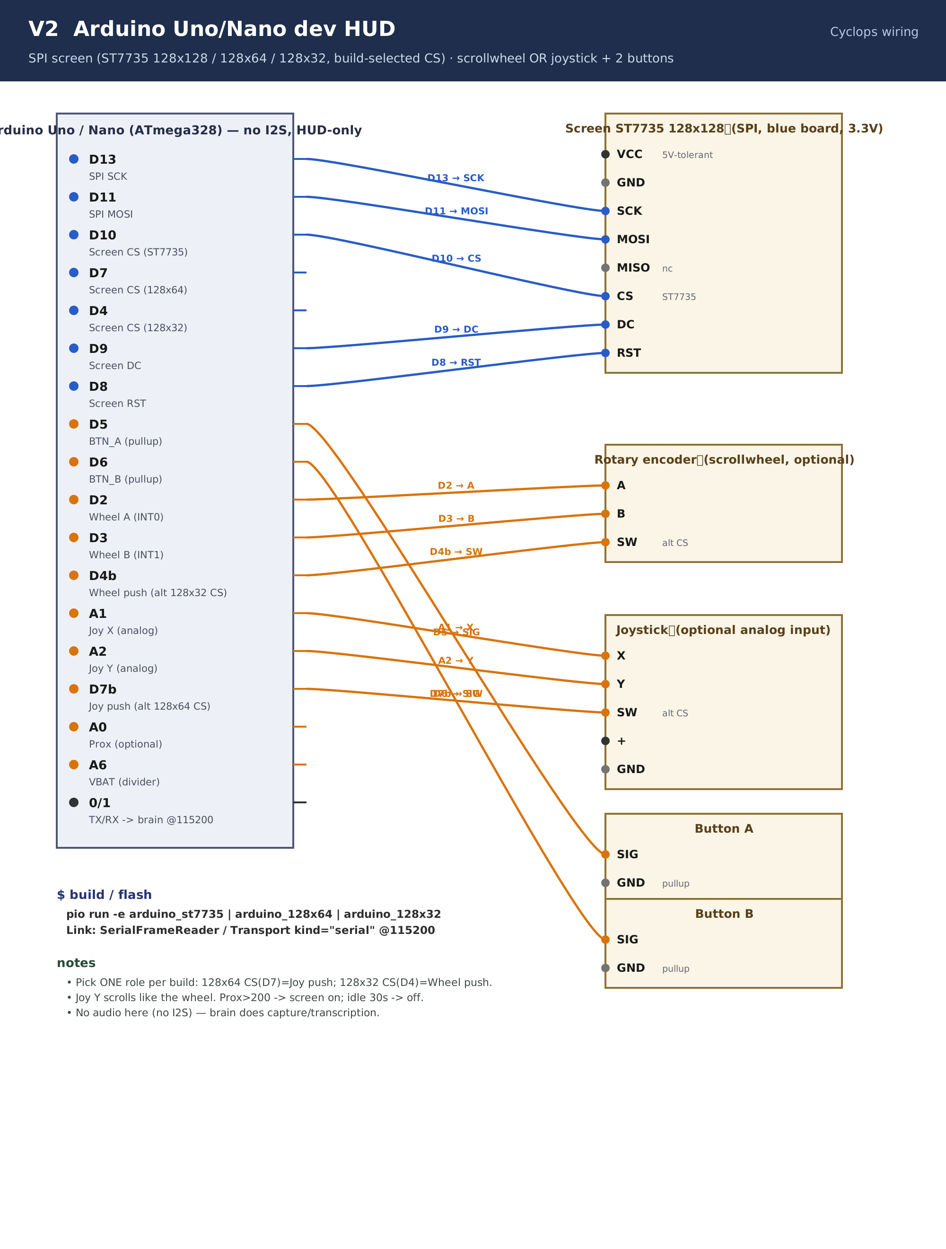
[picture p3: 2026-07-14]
docs/cyclops_v2_Arduino_Uno_Nano_dev_HUD.png

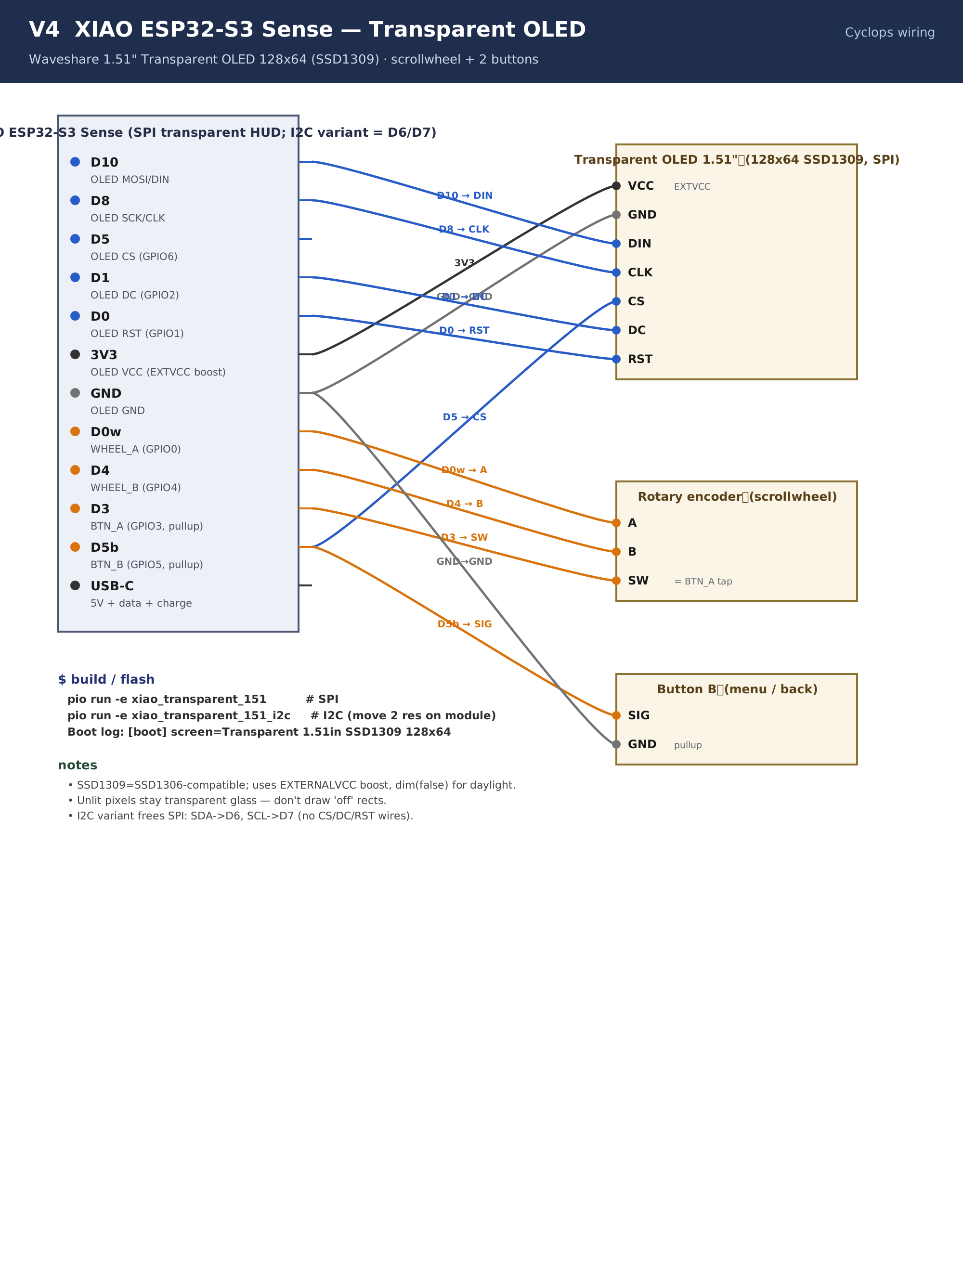
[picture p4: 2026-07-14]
docs/cyclops_v4_XIAO_ESP32_S3_Sense.png

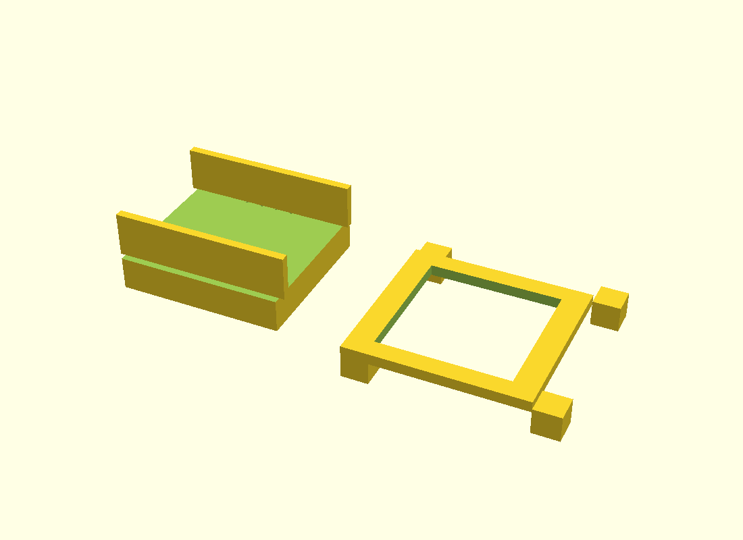
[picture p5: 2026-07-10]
cad/preview_v2.png

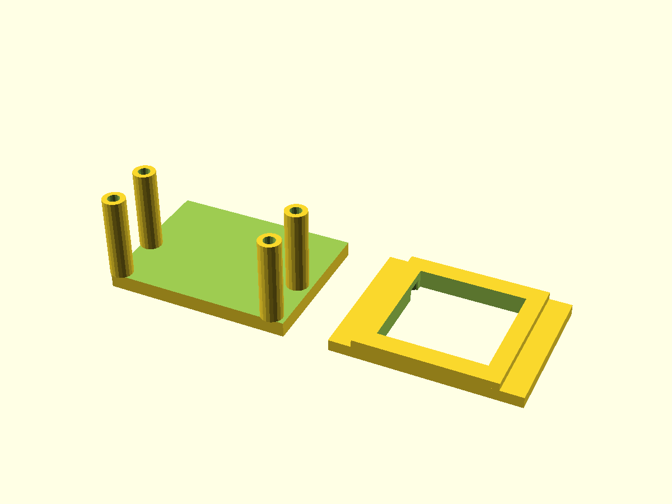
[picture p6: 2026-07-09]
cad/preview_arduino.png

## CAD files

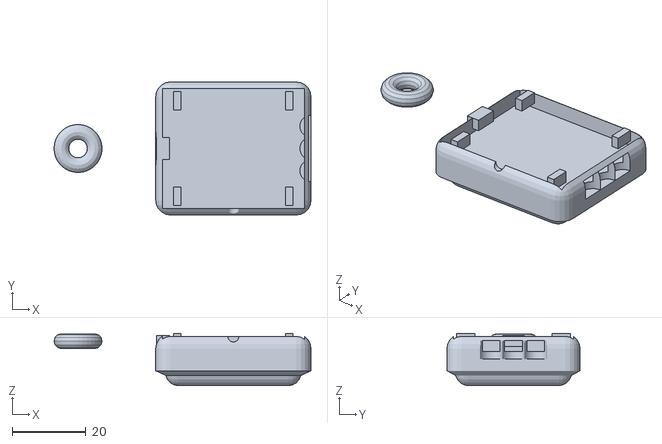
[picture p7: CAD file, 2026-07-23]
cad/stl/fin_body.stl
69.5 x 36.0 x 14.1

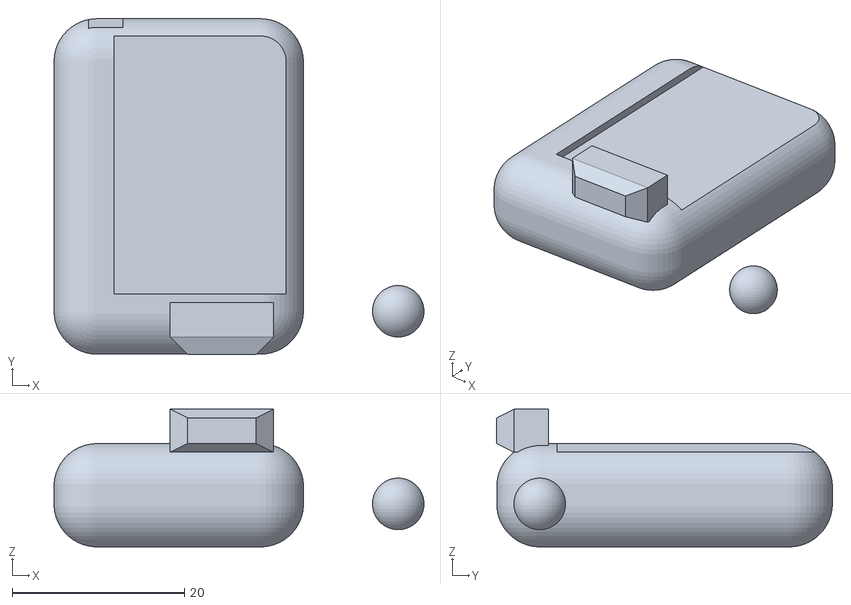
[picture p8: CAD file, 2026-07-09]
cad/variants/xiao_pebble.stl
43.0 x 39.0 x 16.0

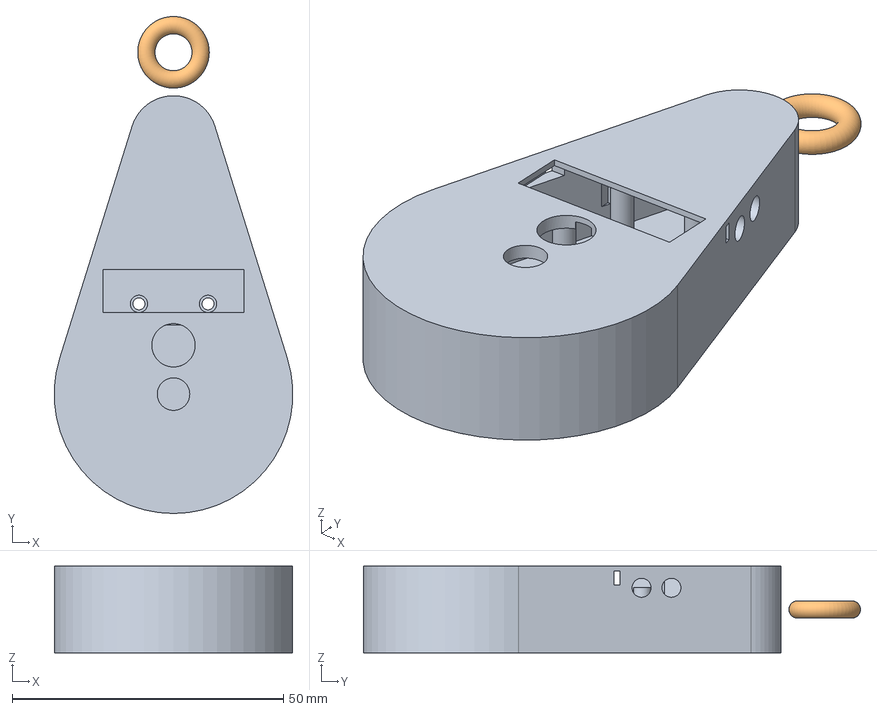
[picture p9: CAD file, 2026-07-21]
cad/freecad/pendant_body_v5.step
43.9 x 91.6 x 16.0 mm

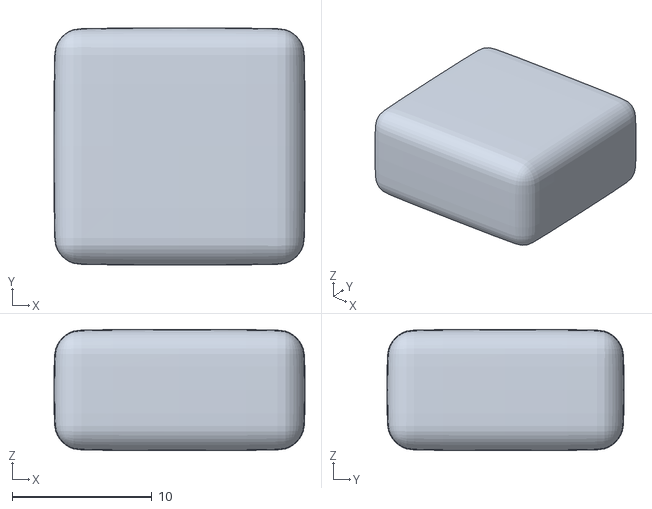
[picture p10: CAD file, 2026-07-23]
cad/stl/skeleton_body.stl
18.0 x 17.0 x 8.68

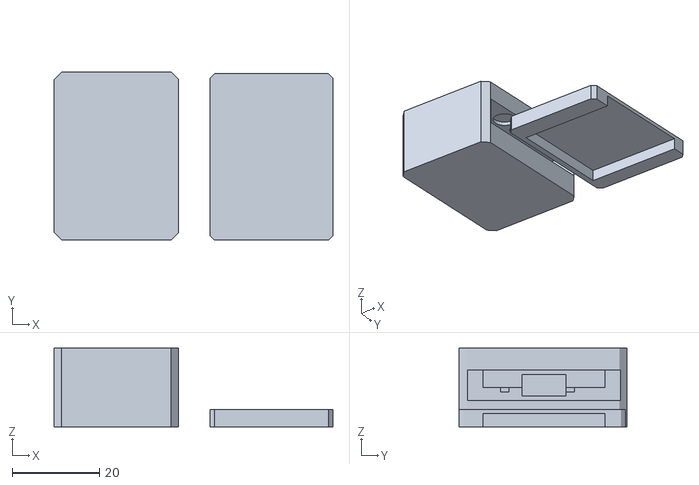
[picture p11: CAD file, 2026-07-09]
cad/variants/xiao_tech.stl
63.8 x 38.5 x 18.0

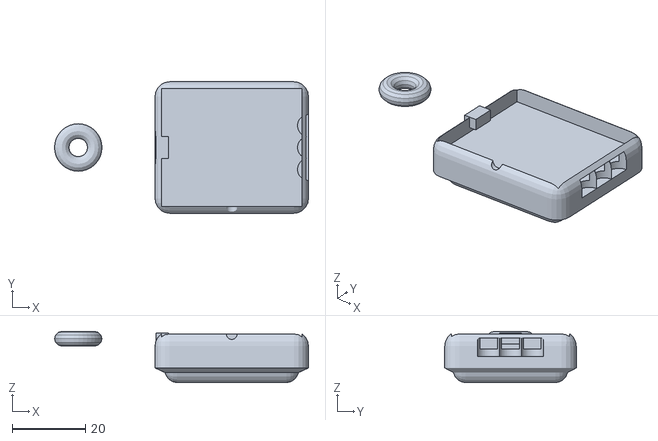
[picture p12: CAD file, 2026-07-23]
cad/stl/manta_body.stl
69.5 x 36.0 x 14.0

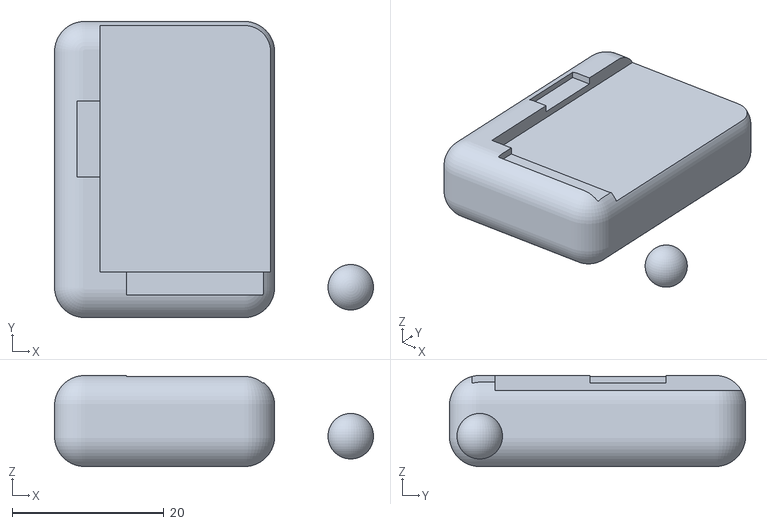
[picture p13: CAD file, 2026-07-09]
cad/variants/xiao_skeleton.stl
42.0 x 39.0 x 12.0

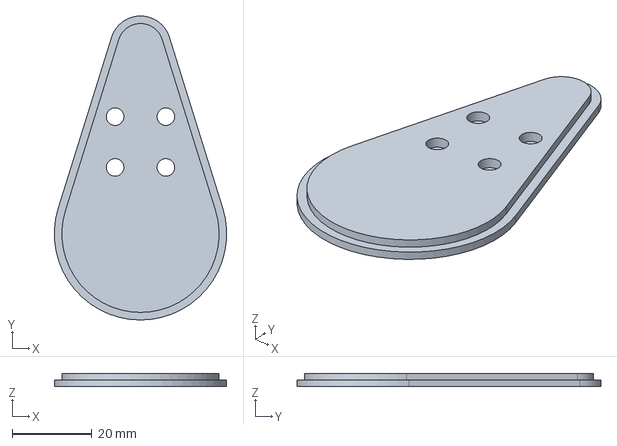
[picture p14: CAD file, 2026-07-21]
cad/freecad/pendant_cap_v5.step
43.1 x 76.2 x 3.20 mm

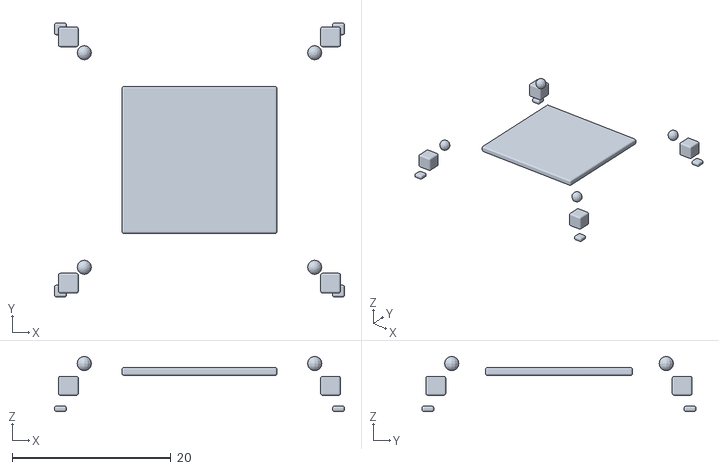
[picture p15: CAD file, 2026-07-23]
cad/stl/tech_lid.stl
36.5 x 34.5 x 6.95

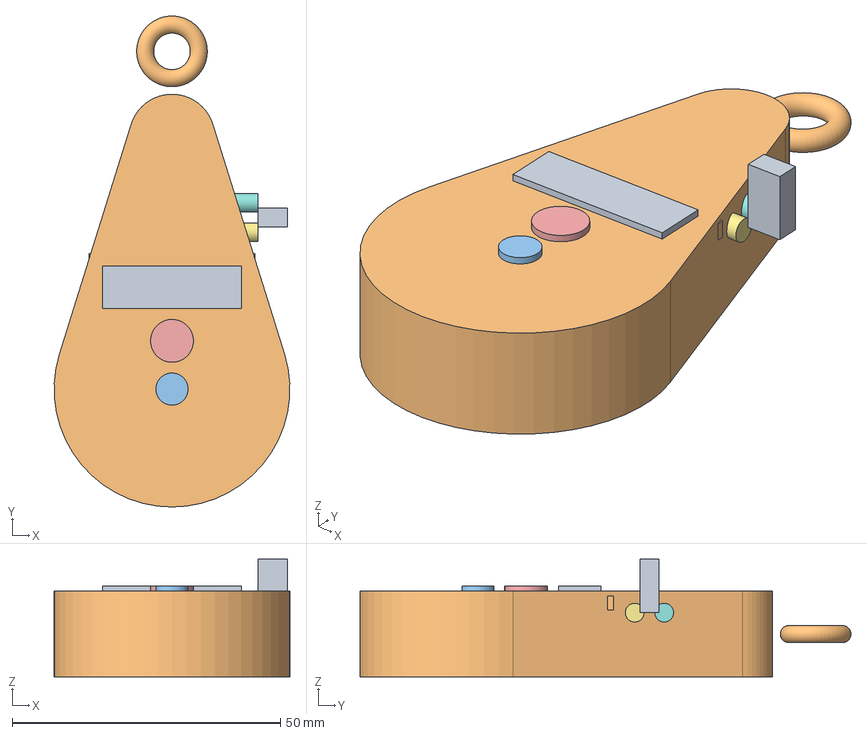
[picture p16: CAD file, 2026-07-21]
cad/freecad/CyclopsPendant.FCStd
43.9 x 91.6 x 22.0 mm
Body_raw
Bail_raw
Body_bail
Hollow_tool
P_Batt
P_Xiao
P_Imu
P_OledWin
P_OledSeat
P_JoyShaft
P_JoyBody
P_BtnHole
P_BtnBody
P_UsbCyl__1
P_UsbCyl_1
P_UsbFill
PendantBody
Cap

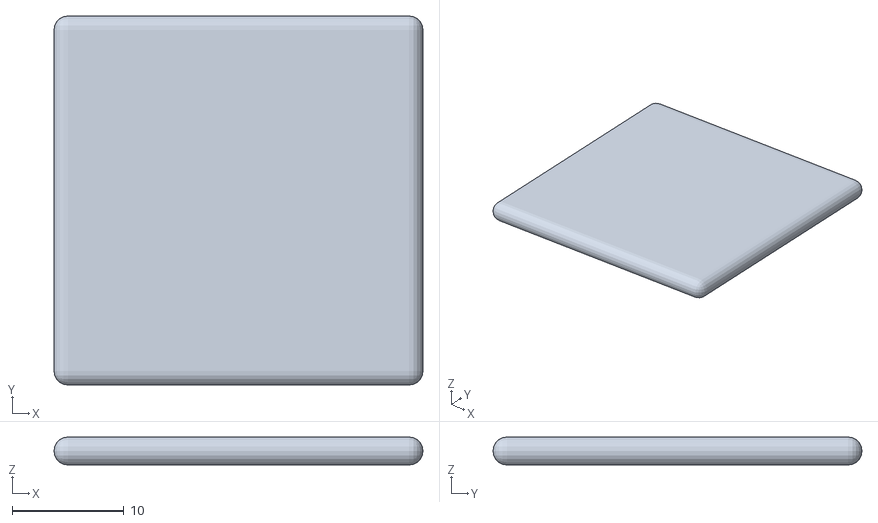
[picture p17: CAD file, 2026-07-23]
cad/stl/eye_lid.stl
33.0 x 33.0 x 2.50

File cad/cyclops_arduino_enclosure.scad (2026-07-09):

// Cyclops — Arduino Nano HUD desktop enclosure
// Parametric OpenSCAD. Renders with: openscad -o arduino.stl cyclops_arduino_enclosure.scad
//
// Holds an Arduino Nano on standoffs + a ST7735 1.8" TFT mounted on the lid
// (wired via dupont cables). Controls (buttons/wheel) stick through the top.
// Open bottom (or add a base plate) so the USB-mini of the Nano is reachable
// for the serial link to the brain.

nano_l = 45.0;   // Nano board length
nano_w = 18.0;   // Nano width
wall   = 2.0;
floor_h= 4.0;    // base floor
inner_h= 26.0;   // height under lid
body_l = nano_l + 2*wall + 6;
body_w = max(nano_w, 40.0) + 2*wall;
body_h = floor_h + inner_h;
$fn = 24;

// ST7735 module (1.8") mounted on lid, facing up
mod_w = 35.0;
mod_h = 36.0;
win_w = 28.0;
win_h = 28.0;

module rbox(l,w,h,r=2.0){
  hull(){
    translate([ r, r, 0]) cube([l-2*r, w-2*r, h]);
    translate([ r, w-r, 0]) cube([l-2*r, 0.01, h]);
    translate([ l-r, r, 0]) cube([0.01, w-2*r, h]);
    translate([ l-r, w-r, 0]) cube([0.01, 0.01, h]);
  }
}

// standoff post for an M3 screw
module standoff(x,y,h){
  difference(){
    cylinder(d=6, h=h, $fn=20);
    translate([0,0,-1]) cylinder(d=3.2, h=h+2, $fn=16);
  }
}

module body(){
  difference(){
    rbox(body_l, body_w, body_h, 3);
    // hollow
    translate([wall, wall, floor_h])
      cube([body_l-2*wall, body_w-2*wall, body_h-floor_h+1]);
    // Nano USB-mini cutout on -X end (reachable for serial)
    translate([-1, body_w/2-7, floor_h+2]) cube([4, 14, 8]);
  }
  // 4 standoffs at Nano corners (raised from floor)
  for (p = [[wall+3, wall+3], [wall+3, wall+nano_w-1],
            [wall+3+nano_l-2, wall+3], [wall+3+nano_l-2, wall+nano_w-1]])
    translate([p[0], p[1], floor_h]) standoff(p[0], p[1], inner_h-4);
}

module lid(){
  // top plate with screen window + control holes
  difference(){
    rbox(body_l, body_w, 3.0, 3);
    // screen window centered
    translate([body_l/2 - win_w/2, body_w/2 - win_h/2, -1])
      cube([win_w, win_h, 5]);
    // control holes (BTN_A=D5, BTN_B=D6, WHEEL_A=D2, WHEEL_B=D3, WHEEL_BTN=D4)
    // laid out in a row near the front (+X)
    for (i = [0:4])
      translate([wall+12 + i*7, body_w/2+10, -1]) cylinder(d=5, h=5, $fn=16);
  }
  // a thin raised bezel ring around the screen
  difference(){
    translate([body_l/2 - mod_w/2 - 1, body_w/2 - mod_h/2 - 1, 3])
      cube([mod_w+2, mod_h+2, 2]);
    translate([body_l/2 - win_w/2, body_w/2 - win_h/2, 2])
      cube([win_w, win_h, 4]);
  }
}

// render: PART=body | PART=lid | PART=all (default: both side by side)
// is_undef(PART) -> show both so the GUI is never empty.
if (!is_undef(PART) && PART == "body") {
  body();
} else if (!is_undef(PART) && PART == "lid") {
  lid();
} else {
  body();
  translate([body_l+6, 0, 0]) lid();
}

// Note: wire the ST7735 (CS=D10, DC=D9, RST=D8, SCK=D13, MOSI=D11) to the
// Nano with Dupont jumpers before closing the lid. VBAT/prox/joystick are
// optional. See docs/31-schematics-arduino.md.

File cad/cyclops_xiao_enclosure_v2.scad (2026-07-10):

// Cyclops — XIAO ESP32-S3 Sense wearable enclosure  ·  V2
// Parametric OpenSCAD.  Render:  openscad cyclops_xiao_enclosure_v2.scad
// Export:  openscad -D 'PART="body"' -o v2_body.stl cyclops_xiao_enclosure_v2.scad
//          openscad -D 'PART="lid"'  -o v2_lid.stl  cyclops_xiao_enclosure_v2.scad
//
// COORDINATE FRAME (consistent everywhere): corner-origin.
//   body : x[0..body_l]  y[0..body_w]  z[0..body_H], sits on z=0.
//   +X / -X = the SHORT ends (button bank on +X, USB-C + lanyard on -X).
//   +Y / -Y = the LONG side walls (ventilation banks live here).
//   Pocket interior is carved x[wall..body_l-wall] y[wall..body_w-wall]
//   z[base_h..body_H]; it is OPEN at the top so the board + screen drop in and
//   the lid caps the rim. The wall above z=body_h is the lock lip (a rim).
//
// V2 changes over v1:
//   1. VENTILATION — the XIAO + ST7735 get warm; v1 trapped heat and muffled
//      the MEMS mic. v2 adds lateral vent slots on BOTH long side walls, each
//      backed by an inboard air-gap baffle (pocket stays closed to fingers /
//      splash while air curls over the baffle into the pocket), a clear front
//      mic port, and a floor chimney for convection.
//   2. CLIP FIT — a real cantilever snap-fit: the body top wall forms a lock
//      lip; the lid overhangs and caps the whole top, and four living-hinge
//      claws on its underside drop past the lip and hook under the rim, clicking
//      home with no glue / tools / hardware. Four ratchet dots on the lid
//      underside catch the lip top for a satisfying detent.
//
// Board: XIAO ESP32-S3 Sense (21.0 x 17.5 mm). Screen: ST7735 1.8" (glass 28x28).
// Pins: BTN_A=GPIO3, BTN_B=GPIO5, WHEEL_B=GPIO4 (holes on +X end). Mic = MEMS
// on the Sense module (front -Y wall port).

// ---- parameters ----
xiao_l   = 21.0;   // board length (mm)
xiao_w   = 17.5;   // board width
wall     = 2.0;    // wall thickness
base_h   = 6.0;    // pocket floor depth (board sits on it)
pocket_h = 9.0;    // interior pocket height above floor
lip_h    = 2.4;    // raised lock lip height above body top
body_h   = base_h + pocket_h;        // 15.0 main body height
body_H   = body_h + lip_h;           // 17.4 total height (incl lip)

// the screen glass drives the case width (it is the biggest component)
screen_glass = 28.0;  // ST7735 visible glass
body_l = screen_glass + 2*wall + 4;  // 36.0  (length, incl end caps)
body_w = screen_glass + 2*wall + 2;  // 34.0  (width)

// lid overhangs the body so it caps the lip from outside
lid_overhang = 1.5;
lid_l  = body_l + 2*lid_overhang;    // 39.0
lid_w  = body_w + 2*lid_overhang;    // 37.0
win    = 24.0;    // lid viewing window (reveal); < lid so plate + claws stay

// closure geometry
tab_w      = 5.0;   // snap claw footprint
tab_drop   = 4.2;   // how far claws hang below the lid
tab_hook   = 3.0;   // inward hook length at claw tip
ratch_d    = 1.8;   // ratchet detent dot diameter
c          = tab_w/2 + 0.5;   // corner anchor inset (3.0)

// ventilation geometry
vent_rows  = 3;     // rows of vents per side (vertical)
vent_cols  = 4;     // vents per row (along X)
vent_w     = 2.2;   // individual slot width (along X)
vent_h     = 5.0;   // individual slot height (vertical, Z)
vent_gap_x = 3.0;   // spacing along X
vent_gap_y = 3.0;   // spacing between rows (Z)
vent_z     = 7.0;   // first row height above floor
mic_port_d = 4.0;   // acoustic mic port diameter

$fn = 24;

// ---- helpers ----
module rounded_box(l,w,h,r=2.0){
  hull(){
    translate([ r,   r,    0]) cube([l-2*r, w-2*r, h]);
    translate([ r,   w-r,   0]) cube([l-2*r, 0.01,  h]);
    translate([ l-r, r,     0]) cube([0.01,  w-2*r, h]);
    translate([ l-r, w-r,   0]) cube([0.01,  0.01,  h]);
  }
}

// round-rect prism (long axis = local Z); used for vent slots
module vent_slot(w,h,depth){
  hull(){
    for(sx=[-1,1])
      translate([sx*(w/2-1), -h/2+1, 0]) cube([1, h-2, depth]);
    for(sx=[-1,1])
      translate([sx*(w/2-1), h/2-1, 0]) cube([1, 1, depth]);
  }
}

// cylindrical hole driven along X (pierces a short END wall)
module end_hole(x_wall, y, z, d){
  translate([x_wall, y, z]) rotate([0,90,0])
    cylinder(d=d, h=wall+3, $fn=20);
}
// cylindrical hole driven along Y (pierces a long SIDE wall)
module side_hole(y_wall, x, z, d){
  translate([x, y_wall, z]) rotate([90,0,0])
    cylinder(d=d, h=wall+3, $fn=20);
}

// ---- ventilation: banks on the two long side walls ----
// Slot long-axis runs along X, height is vertical (Z); the hole is driven along
// Y so it pierces the side wall. y_face = the wall centre in corner-origin frame.
module vent_bank_side(y_face){
  for(r=[0:vent_rows-1])
    for(col=[0:vent_cols-1]){
      vx = body_l/2 + (col - (vent_cols-1)/2) * vent_gap_x;
      vz = vent_z + r * vent_gap_y;
      translate([vx, y_face, vz])
        rotate([90,0,0])
          vent_slot(vent_w, vent_h, wall+3);
    }
}

// air-gap baffles: a thin fin parallel to each long side wall, attached to the
// pocket floor, rising most of the pocket height, set inboard. The vent slot
// opens into the narrow channel between the wall and the baffle; sightline from
// the exterior to the interior is blocked (no finger/splash straight-through)
// but air enters the channel and curls over the baffle top into the pocket.
// ADDED (unioned) to the body, attached to the floor => one manifold, printable.
module airgap_baffles(){
  baffle_off = (body_w/2) - wall - 3.0;   // inboard of each side wall
  baffle_t   = 1.5;                       // fin thickness (Y)
  baffle_top = body_h - 1.0;              // leave 1mm gap over the top
  for(side=[-1,1]){
    yc = body_w/2 + side*baffle_off;
    translate([wall, yc - baffle_t/2, base_h])
      cube([body_l - 2*wall, baffle_t, baffle_top - base_h]);
  }
}

// board-clearance chimney through the pocket floor (passive convection)
module chimney(){
  translate([body_l/2, body_w/2 - 4, base_h-1])
    cylinder(d=4.0, h=base_h+2, $fn=16);
}

// ---- BODY (single watertight solid) ----
// Outer shell (full height incl. lip) with the pocket carved OPEN to the top so
// the board drops in and the lid caps the rim. The outer wall stays solid all
// the way up to form the lock lip. All subtractive features pierce fully so the
// carves stay watertight. Air-gap baffles are UNIONED onto the shell (attached
// to the floor) so they add structure, not void. Screen is visible through the
// open pocket (no top window needed on the body).
module body(){
  union(){
    difference(){
      rounded_box(body_l, body_w, body_H, 3);
      // interior pocket, OPEN at top (carved to body_H)
      translate([wall, wall, base_h])
        cube([body_l-2*wall, body_w-2*wall, body_H - base_h]);
      // USB-C cutout on -X end (rectangular slot piercing the end wall)
      translate([-2, body_w/2-5, base_h+1]) cube([6, 10, 5]);
      // button holes on +X end: BTN_A (3) / BTN_B (5) / WHEEL_B (4)
      end_hole(body_l - wall/2, body_w/2-7, base_h+4.0, 6.0);
      end_hole(body_l - wall/2, body_w/2+7, base_h+4.0, 6.0);
      end_hole(body_l - wall/2, body_w/2,   base_h+4.5, 6.0);
      // two lanyard/strap slots on -X end
      translate([-1, body_w/2-11, body_H/2-1.5]) cube([4, 8, 3]);
      translate([-1, body_w/2+3,  body_H/2-1.5]) cube([4, 8, 3]);
      // ventilation banks on both long side walls
      vent_bank_side( body_w - wall/2);   // +Y wall
      vent_bank_side( wall/2);            // -Y wall
      // front mic port on -Y wall (clear acoustic path, no baffle)
      side_hole( wall/2, body_l/2-6, base_h+3, mic_port_d);
      chimney();
    }
    airgap_baffles();
  }
}

// ---- LID (snap-fit) ----
// Overhangs and caps the whole top (footprint = body + overhang). Four claws
// hang from the underside at the corners, drop past the lip, and hook inward
// under the rim. Four ratchet dots on the underside catch the lip top. A viewing
// window is cut through the plate so the ST7735 shows through. Authored at
// z=0..lid_t; everything overlaps the plate => one manifold solid.
module snap_claw(cx, cy, dirx, diry){
  // cx,cy = corner anchor on the lid underside; dirx/diry = outward direction
  // post overlaps 0.6 into the plate so the union is one manifold
  translate([cx, cy, -tab_drop]){
    cube([tab_w, tab_w, tab_drop + 0.6]);
    // inward hook at the bottom that grabs the lip underside
    translate([dirx*(tab_w/2 - tab_hook/2),
               diry*(tab_w/2 - tab_hook/2),
               tab_drop - 1.2])
      cube([dirx*tab_hook, diry*tab_hook, 1.4]);
  }
}
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

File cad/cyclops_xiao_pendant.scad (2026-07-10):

// Cyclops — XIAO ESP32-S3 Sense PENDANT case  ·  teardrop / wearable amulet
// Parametric OpenSCAD.  Screenless capture puck (notes/display via phone/G2 +
// TTS, already wired in the brain). Geometry pulled from researched component
// dims (see footer URLs).
//
// Render both:    openscad cyclops_xiao_pendant.scad
// Export parts:   openscad -D 'PART="body"' -o pendant_body.stl cyclops_xiao_pendant.scad
//                 openscad -D 'PART="cap"'  -o pendant_cap.stl  cyclops_xiao_pendant.scad
//
// Component dims used (researched, mm):
//   XIAO ESP32-S3 Sense .... 21.0 x 17.5, Sense piggyback stack ~6 tall
//   External IMU GY-521 .... 20 x 15 x 2.5  (on D6/D7 I2C, avoids GPIO5/6 colln)
//   LiPo 302030 ............ 30 x 20 x 3
//   EC11 encoder ........... shaft Ø6, body ~11.5 sq, used as side "crown"
//   2x SMD side tact ....... ~4x4x1.6 (modelled Ø4 holes)
//   u.FL whip antenna ...... pigtail exits at bail tip slot
//
// Layer stack inside the pendant (Z = front->back, front face = +Z = top):
//   cap plate ........... z 0..1.6   (back cover, press-fit lip)
//   battery 302030 ...... z 2.5..5.5 (lies flat on cap)
//   XIAO board ......... z 6.0..12.0 (stack height ~6)
//   IMU breakout ....... z 12.3..14.8 (sits on the I2C bus above XIAO)
//   front shell ........ z 14.8..T    (T = total thickness)

// ---- parameters ----
wall      = 2.0;     // shell wall thickness
T         = 16.0;    // total pendant thickness (front face at +Z)
inset     = wall;    // interior pocket inset

// board / part dims
xiao_l = 21.0;  xiao_w = 17.5;  xiao_h = 6.0;
imu_l  = 20.0;  imu_w  = 15.0;  imu_h  = 2.5;
batt_l = 30.0;  batt_w = 20.0;  batt_h = 3.0;

// teardrop outline (2D, broad face in XY)
bulge_r   = 22.0;   // bottom bulge radius
bulge_y   = -22.0;  // bottom bulge center
neck_r    = 7.0;    // top neck radius (tapers to tip)
neck_y    = 30.0;   // neck center
tip_y     = 37.0;   // lanyard bail tip

// wheel / crown
enc_d     = 7.2;    // shaft+collar hole (EC11 shaft Ø6 + clearance)
enc_body  = 12.0;   // encoder body pocket dia
wheel_y   = 22.0;   // crown position on the upper chest (front-proud)

// buttons (2x side tact)
btn_d     = 4.2;    // side button hole dia
btn_y     = -4.0;   // vertical positions (mirror L/R)
btn_y2    = -16.0;

// status LED window (front face, diffuser insert)
led_d     = 6.0;
led_x     = 0.0;
led_y     = 16.0;

// acoustic mic vent (front, over XIAO MEMS mic)
mic_w     = 3.0;  mic_h = 5.0;
mic_x     = -7.0; mic_y = -2.0;

// u.FL antenna exit slot (bail tip)
ufl_w     = 4.0;  ufl_h = 2.0;

// USB-C cutout (side, field-serviceable power/program — XIAO edge connector)
usb_w     = 9.0;  usb_h = 3.4;
usb_y     = 6.0;   // near the top neck, clear of buttons/mic

// closure
lip_h     = 1.6;   // cap seating lip
cap_t     = 1.6;   // cap plate thickness

$fn = 36;

// ---- helpers ----
module teardrop_2d(){
  // hull of a wide bottom circle + small top neck circle => teardrop
  hull(){
    translate([0, bulge_y, 0]) circle(r=bulge_r);
    translate([0, neck_y,  0]) circle(r=neck_r);
  }
}

module shell_outer(){           // full solid teardrop slab
  linear_extrude(height=T) teardrop_2d();
}

module shell_inner(){           // hollowed interior (pocket)
  // inset pocket from the broad outline
  translate([0,0,cap_t])
    linear_extrude(height=T-cap_t-wall)
      offset(r=-inset) teardrop_2d();
}

// round-rect pocket for a flat part lying in XY at height z0
module part_pocket(l,w,h,z0,cx=0,cy=0){
  translate([cx-l/2, cy-w/2, z0]) cube([l, w, h+0.4]);
}

// through-hole (cylinder spanning the slab)
module through_hole(d, x, y, z0=0, z1=T){
  translate([x, y, z0-1]) cylinder(d=d, h=(z1-z0)+2, $fn=24);
}

module side_hole(d, y, x_sign=1, w_box=0){   // hole through curved side wall (X axis)
  // d = throat dia (round) OR slot height if w_box>0 (rounded-rect slot)
  translate([x_sign*(bulge_r-wall-0.5), y, T/2])
    rotate([0,90,0]){
      if(w_box>0){
        hull(){
          for(sy=[-1,1])
            translate([0, sy*(w_box/2-d/2), 0]) cylinder(d=d, h=wall+3, $fn=20);
        }
      } else {
        cylinder(d=d, h=wall+3, $fn=20);
      }
    }
}

// ---- BODY (front shell) ----
module body(){
  difference(){
    shell_outer();
    shell_inner();                                   // hollow
    // part pockets (clearance for battery / xiao / imu)
    part_pocket(batt_l+1, batt_w+1, batt_h+1, cap_t+1.0, 0, -18);
    part_pocket(xiao_l+1, xiao_w+1, xiao_h+1, cap_t+4.0, 0, 1);
    part_pocket(imu_l+1,  imu_w+1,  imu_h+1,  cap_t+8.3, 0, 1);
    // wheel / crown: shaft hole through the front (upper chest) + body recess
    through_hole(enc_d, 0, wheel_y, T-enc_d/2-0.5, T+2);
    translate([0, wheel_y, T-enc_body/2-3])
      cylinder(d=enc_body, h=enc_body/2+3, $fn=24);   // encoder body pocket
    // 2x side buttons
    side_hole(btn_d, btn_y,  1);
    side_hole(btn_d, btn_y, -1);
    side_hole(btn_d, btn_y2, 1);
    side_hole(btn_d, btn_y2,-1);
    // status LED window (front, thin remaining shell => diffuser insert)
    through_hole(led_d, led_x, led_y, T-1.0, T+2);
    // mic acoustic vent (front, shallow)
    translate([mic_x-mic_w/2, mic_y-mic_h/2, T-2.5])
      cube([mic_w, mic_h, 3]);
    // u.FL antenna exit slot at the bail tip
    translate([-ufl_w/2, tip_y-1, T/2-1]) cube([ufl_w, ufl_h+2, 3]);
    // USB-C cutout (side, XIAO edge connector) — field-serviceable
    side_hole(usb_h, usb_y,  1, w_box=usb_w);
    side_hole(usb_h, usb_y, -1, w_box=usb_w);
  }
  // lanyard bail (ring) at the tip — torus axis along Z
  translate([0, tip_y+1, T/2]) rotate([0,0,0])
    torus(5.0, 1.6);
}

module torus(R, r){
  rotate_extrude() translate([R,0,0]) circle(r=r, $fn=20);
}

// ---- CAP (back cover, press-fit lip) ----
module cap(){
  difference(){
    union(){
      // back plate
      linear_extrude(height=cap_t)
        offset(r=-0.4) teardrop_2d();
      // seating lip (sits inside the body pocket)
      translate([0,0,cap_t])
        linear_extrude(height=lip_h)
          offset(r=-inset-0.3) teardrop_2d();
    }
    // 4 M2 standoffs for the XIAO (optional screw mounting)
    for(a=[0:3]){
      ang = a*90 + 45;
      sx = 9*cos(ang); sy = 1 + 9*sin(ang);
      translate([sx, sy, cap_t]) cylinder(d=3.2, h=lip_h+6, $fn=16);
    }
  }
}

// ---- render dispatcher ----
PART = undef;
if (!is_undef(PART) && PART=="body") body();
else if (!is_undef(PART) && PART=="cap")  cap();
else { body(); translate([0,-70,0]) cap(); }

// ---- printable orientation / notes ----
// Print body front-face-DOWN (bail tip up) so the teardrop lies flat. Cap flat.
// Scale all holes 1.05x if your printer runs tight. LED window: drop in a
// Ø6 translucent diffuser disc. Wheel crown: trim EC11 shaft to ~8 mm proud.
// Antenna: feed u.FL pigtail out the tip slot, dress along the bail, strain-relief
// with a dab of silicone. Battery: flat 302030 LiPo, swap via the cap.
//
// Refs:
//  XIAO ESP32-S3 Sense — https://www.seeedstudio.com/Seeed-XIAO-ESP32S3-Sense-p-5639.html
//  GY-521 MPU-6050 breakout dims — https://ifuturetech.org/product/gy-521-mpu-6050-3-axis-accelerometer-and-gyroscope-sensor/
//  EC11 encoder datasheet — https://www.mouser.com/datasheet/2/15/EC11-1370808.pdf

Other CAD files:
cad/stl/eye_body.stl
cad/stl/skeleton_lid.stl
cad/stl/tech_body.stl
cad/stl/pebble_lid.stl
cad/cyclops_xiao_pendant_v3_antenna.scad
cad/cyclops_eye.blend
cad/cyclops_fin.blend
cad/cyclops_manta.blend
cad/cyclops_pebble.blend
cad/cyclops_skeleton.blend
cad/cyclops_tech.blend
cad/cyclops_xiao_enclosure.scad
cad/cyclops_xiao_v1_pebble.scad
cad/cyclops_xiao_v2_leaf.scad
cad/cyclops_xiao_v3_gem.scad
cad/cyclops_xiao_v4_temple.scad
cad/cyclops_xiao_variants.scad
cad/freecad/pendant_body_v4.step
cad/freecad/pendant_body_v4.stl
cad/freecad/pendant_body_v5.stl
cad/freecad/pendant_cap_v4.step
cad/freecad/pendant_cap_v4.stl
cad/freecad/pendant_cap_v5.stl
cad/stl/arduino_all.stl
cad/stl/arduino_body.stl
cad/stl/arduino_lid.stl
cad/stl/pendant_body.stl
cad/stl/pendant_cap.stl
cad/stl/pendant_v3_antenna_body.stl
cad/stl/pendant_v3_antenna_cap.stl
cad/stl/v2_all.stl
cad/stl/v2_body.stl
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

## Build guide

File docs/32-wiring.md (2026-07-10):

# Wiring — XIAO ESP32-S3 Sense

Single source for the Cyclops wearable wiring. Board: Seeed XIAO ESP32-S3 **Sense**
(onboard mic + microSD). Current firmware target: `xiao_128x32_i2c` (4-pin I2C OLED).

## Firmware pin map (already reserved — DO NOT reuse)

| GPIO (silk) | Function | Notes |
|---|---|---|
| GPIO0 (D0)  | WHEEL_A | scroll wheel A |
| GPIO4 (D4)  | WHEEL_B | scroll wheel B |
| GPIO3 (D3)  | BTN_A | short=select, long=back/stop |
| GPIO5 (D5)  | BTN_B | cancel/back |
| GPIO40/41/42| MIC (onboard) | I2S, do not touch |
| GPIO21/7/8/9| SD (onboard slot) | CS=21, SCK=7, MISO=8, MOSI=9 |
| GPIO43 (D6) | I2C SDA | shared screen + gyro bus |
| GPIO44 (D7) | I2C SCL | shared screen + gyro bus |

Free GPIOs for expansion: GPIO1 (D1), GPIO2 (D2), GPIO6 (D5-silk),
GPIO10–20, GPIO38/39/45–48.

## Display — 4-pin I2C OLED (128×32)

Default build target. Firmware: `SCREEN_128x32_I2C`, I2C on D6/D7.

| OLED pin | XIAO pad | GPIO |
|---|---|---|
| VCC | 3V3 | — |
| GND | GND | — |
| SDA | D6 | 43 |
| SCL | D7 | 44 |

- 3.3 V native, no level shifter, no reset pin needed (`rst_pin=-1`).
- Address 0x3C default. If the panel stays **blank**, flip to 0x3D in
  `firmware/lib/cyclops_shared/include/screens.h` (`addr_` ctor param) and rebuild.
- Build/flash:
  ```
  cd firmware && . .venv/bin/activate
  pio run -e xiao_128x32_i2c -t upload --upload-port /dev/ttyACM0
  ```

## Gyroscope / IMU — I2C (shared bus)

Use an **I2C** breakout (MPU-6050 or LSM6DS3). It hangs on the same D6/D7 bus as
the screen; devices are distinguished by I2C address, so no extra bus needed.

| IMU pin | XIAO pad | GPIO |
|---|---|---|
| VCC | 3V3 | — |
| GND | GND | — |
| SDA | D6 | 43 |
| SCL | D7 | 44 |
| INT | D1 | 1 |  (optional: tap/double-tap IRQ)
| ADDR | — | — |  (float or pull to set 2nd addr if needed)

- Typical addresses: MPU-6050 = 0x68 / 0x69, LSM6DS3 = 0x6A / 0x6B.
  OLED = 0x3C, so no clash in the common case.
- The XIAO S3 Sense **onboard** LSM6DS3 sits on the *default* I2C bus
  (GPIO5/6), which collides with **BTN_B (GPIO5)**. Do NOT use the onboard
  IMU without first moving BTN_B to a free pin. The external IMU on D6/D7
  (above) avoids this entirely.

## Reserved — leave these alone

- Wheel + buttons: GPIO0/3/4/5 (firmware live).
- Screen + gyro: GPIO43/44 I2C bus.
- SD: GPIO21/7/8/9 (onboard Sense slot; FAT32 card ≤32 GB).
- Mic: GPIO40/41/42.

## Battery (optional, not wired by default)

The Sense has an onboard charger but **no fuel-gauge ADC** routed. To read
battery %, add a divider:

```
BAT+ ── 100k ── GPIO2 (D2) ── 100k ── GND
```

Leave GPIO2 free for this. Firmware support is added on request
(`-DENABLE_BATT=1`).

## Full layout (one picture)

```
                 XIAO ESP32-S3 SENSE
   ┌──────────────────────────────────────────┐
   │  USB-C                                     │
   │                                            │
   │  OLED 128x32 (I2C) ── SDA→D6  SCL→D7       │  ← screen + gyro bus
   │  GYRO (I2C)        ── SDA→D6  SCL→D7       │
   │  GYRO INT (opt)     ── D1                  │
   │                                            │
   │  WHEEL_A→D0  WHEEL_B→D4                    │
   │  BTN_A→D3    BTN_B→D5                      │
   │  BAT sense→D2 (opt, divider)              │
   │  SD (onboard, GPIO21/7/8/9)               │
   │  MIC (onboard, GPIO40/41/42)              │
   └──────────────────────────────────────────┘
```

## Build matrix (firmware/platformio.ini)

| Env | Screen | Notes |
|---|---|---|
| `xiao_st7735` | ST7735 128×128 SPI  | CS=GPIO6, DC=GPIO2, RST=GPIO1 |
| `xiao_128x64` | SSD1306 128×64 SPI  | |
| `xiao_128x32` | SSD1306 128×32 SPI  | |
| `xiao_128x32_i2c` | SSD1306 128×32 I2C  | **current**; `-DENABLE_RING=1 -DENABLE_IMU=1`, SD logging on |

Flash any: `pio run -e <env> -t upload --upload-port /dev/ttyACM0`.

## SD logging (on by default in i2c build)

- Mounts `/sdcard` on the onboard slot. FAT32 card ≤32 GB.
- Appends timestamped lines to `/sdcard/cyclops.log`: notes, health samples,
  rec start/stop.
- If no card: boots with `[boot] sd card NOT present (logging disabled)`.

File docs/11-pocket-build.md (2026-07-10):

# Cyclops — Pocket Build

> **RECONSTRUCTED DOC** — original `docs/11-pocket-build.md` (2026-07-08) lost
> on corrupted `/dev/sde2`, never bundled. Rebuilt 2026-07-10 from
> `docs/10-form-factor.md` (full wearable), `docs/15-cyclops-mini.md` (Mini),
> `docs/08-bringup.md`, `docs/30-colmi-r02-integration.md`. **[inferred]** =
> reconstructed. The pocket build = the Full wearable tightened to a pocketable
> unit (the bridge between Dev board and Mini).

## 0. What a "pocket build" is

A pocket build is the **Full wearable** packed into a small enclosure you carry
in a pocket: XIAO + OLED + Li-Po + (optional) ring, in a 3D-printed or
off-the-shelf case, charged from a power bank or wall wart via USB-C. It is the
field-testable middle ground before shrinking to the ring-scale Mini.

## 1. BOM (pocket)

| Part | Role |
|---|---|
| XIAO ESP32-S3 Sense | wearable MCU + I2S mic + BLE |
| SSD1306 128×64 **or** ST7735 128×128 | HUD (mono compact vs color) |
| Li-Po 3.7 V (~300–500 mAh) | untethered power |
| Charge/protect circuit | Li-Po safety (or rely on XIAO onboard charger) |
| Small tactile buttons + scrollwheel | input (D3/D5 + D0/D4) |
| Enclosure (`enclosure/` dir) | 3D-printed or clamshell case |
| (optional) COLMI R02 ring | health/gesture |

## 2. Enclosure / wiring

- SPI: `SCK=D8 MOSI=D10 MISO=D9`; screen CS per panel (D6 mono / D7 color),
  DC=D2, RST=D1.
- Input: Wheel A=D0 B=D4; BTN_A=D3 (pull-up); BTN_B=D5 (pull-up — **not D4**).
- I2S mic pads 40/41/42 (onboard; no external wiring needed).
- Li-Po → `BAT` pad through charge/protect; USB-C for charge + data.
- Keep total draw < 300 mA.

## 3. Build flags

- Color: `-DSCREEN_ST7735` on `xiao_st7735`.
- Compact mono: `-DSCREEN_128x64` on `xiao_128x64`.
- Ring: add `-DENABLE_RING`.

## 4. Pocket vs Mini vs Dev

| | Dev board | Pocket (this) | Mini (doc 15) |
|--|---|---|---|
| Display | ST7735 128×128 | 128×64 or 128×128 | 128×32 |
| Sensor | IMU + I2S | IMU + I2S (+ring) | ring-first |
| Power | USB-C tether | Li-Po | Li-Po |
| Footprint | breadboard | pocket enclosure | finger + coin HUD |
| Purpose | firmware dev | field test | minimal wearable |

## 5. Bring-up (from `08-bringup.md`)

1. `pio run -e xiao_128x64 -t upload` (or `_st7735`).
2. Verify `CyclopsXIAO` advertises; screen renders HOME.
3. Wheel/buttons navigate; long-press A backs out.
4. `Transcribe` → mic → phone STT → NOTE on HUD.
5. (ring) `HEALTH` shows HR/SpO2/batt.
6. Low-batt auto-sleep; vibration confirm (pending).

## 6. Not yet on metal

- Real I2S mic + OLED bench test (logic only, native_test).
- Live BLE to physical R02 / G2 (no hardware on bench).
- `pio run -e xiao_*` flash + field test (CI compiles only).
- Vibration motor, gyro calibration.

---
**[inferred]** The BOM, pin/CS facts, build flags and the comparison table are
grounded in committed `main.cpp` + `22-screens-plan.md` + `15-cyclops-mini.md`
(reconstructed) and should be accurate in structure. Inferred only: the
"pocket" naming as distinct from "full wearable," the enclosure reference, and
the §1 BOM quantities — the original may have specified exact mAh / case dims.

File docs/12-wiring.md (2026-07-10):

# Cyclops — Wiring (XIAO + peripherals)

> **RECONSTRUCTED DOC** — original `docs/12-wiring.md` (2026-07-08) lost on
> corrupted `/dev/sde2`, never bundled. Rebuilt 2026-07-10 from
> `firmware/xiao/src/main.cpp`, `docs/01-hardware.md`, `docs/22-screens-plan.md`,
> `docs/30-colmi-r02-integration.md`. **[inferred]** = reconstructed. This is
> the consolidated pin/signal reference (the ring "wiring" is BLE, not solder).

## 0. Two things called "wiring"

1. **XIAO ↔ peripherals** (screen, wheel, buttons, mic, battery) — real wires.
2. **XIAO ↔ COLMI R02 ring** — **no wires**; it's a BLE GATT link
   (see `30-colmi-r02-integration.md`). "Wiring the ring" = software connect.

## 1. XIAO ESP32-S3 Sense — pin map (verified by compile)

```
  XIAO ESP32-S3 Sense          Function              Notes
  ─────────────────────────────────────────────────────────────────────
  D0  ── wheel A (quad)        scroll input          INT on CHANGE
  D4  ── wheel B (quad)        scroll input
  D3  ── BTN_A (pull-up)      select (short) / back (long >600 ms)
  D5  ── BTN_B (pull-up)      cancel / back one level   (was D4; moved to free GPIO5)
  D8  ── SPI SCK               screen (VSPI)
  D10 ── SPI MOSI              screen
  D9  ── SPI MISO              screen
  D7/D6/D5 ── screen CS        (panel-selected)
  D2  ── screen DC             all panels
  D1  ── screen RST            all panels
  40/41/42 ── I2S BCLK/WS/DIN mic capture (onboard pad)
  5V / GND ── USB-C            power + data + charge
  BAT (pad) ── Li-Po + (optional)   untethered runtime
```

## 2. Screen wiring (one panel, compile-selected)

| Panel | CS | DC | RST | SPI |
|---|----|----|-----|-----|
| ST7735 128×128 | D7 | D2 | D1 | SCK=D8 MOSI=D10 MISO=D9 |
| SSD1306 128×64 | D6 | D2 | D1 | same |
| SSD1306 128×32 | D5 | D2 | D1 | same |

DC=D2, RST=D1 shared. Only the selected panel's CS is compiled in.

## 3. Input wiring

| Signal | Pin | Pull | Behavior |
|---|---|---|---|
| Wheel A | D0 | up | quadrature A (ISR on CHANGE) |
| Wheel B | D4 | up | quadrature B |
| BTN_A | D3 | up | short=select; long>600ms=back/stop |
| BTN_B | D5 | up | short=cancel/back |

**BUG FIXED:** BTN_B was GPIO4 == WHEEL_B (4) — confirm/cancel and wheel
aliased, breaking menu/back. Moved to GPIO5 (verified free: SPI uses
1/2/7/8/9/10, mic 40/41/42). Done in `main.cpp`.

## 4. I2S mic (onboard — no external wire)

`MIC_BCLK=40`, `MIC_WS=41`, `MIC_DIN=42`. `start_capture()` installs I2S
@ 16 kHz / 16-bit / left-only and streams `MSG_AUDIO_CHUNK`. (External I2S
breakout routes to the same three pads + GND.)

## 5. Power wiring

- **Tether:** USB-C 5 V → XIAO regulator → 3.3 V for ESP32 + screen.
- **Untethered:** 3.7 V Li-Po → `BAT` pad (through charge/protect) →
  XIAO charger tops from USB-C. Keep draw < 300 mA.
- **Ring:** independent; magnetic pogo cradle, ~1 hr full, ~5 days.

## 6. Ring "wiring" (BLE, from `30-colmi-r02-integration.md`)

1. Scan for `R02_*`; 2. connect service `6E40FFF0-…-E50E24DCCA9E`;
3. subscribe TX `6E400003-…`; 4. write requests to RX `6E400002-…`;
5. parse 16-byte packets (`ring_parse` C / `parse_*` Python). `-DENABLE_RING`
on the XIAO; `device/colmi_r02.py` (bleak) on the phone/PC.

## 7. Not yet on metal

- Real I2S mic + OLED bench test (logic only, native_test).
- Live BLE to physical R02 / G2 (no hardware on bench).
- `pio run -e xiao_*` flash + field test (CI compiles only).
- Vibration motor, low-batt auto-sleep, gyro calibration.

---
**[inferred]** Every pin, CS, the BTN_B bug, the I2S pads, the power notes
and the ring connect steps are lifted from `main.cpp` + `22-screens-plan.md` +
`30-colmi-r02-integration.md` and should be accurate. Inferred only: the
narrative grouping and the "two things called wiring" framing.

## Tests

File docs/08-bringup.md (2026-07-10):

# Cyclops — Hardware Bring-up

> **RECONSTRUCTED DOC** — original `docs/08-bringup.md` (2026-07-06) lost on
> corrupted `/dev/sde2`, never bundled. Rebuilt 2026-07-10 from
> `firmware/xiao/src/main.cpp`, `docs/01-hardware.md`, `docs/30-colmi-r02-integration.md`,
> `docs/03-hud-ux-plan.md`, `PLAN.md` (Next: hardware). **[inferred]** = guessed.
> Bring-up = the on-metal steps the headless build can't do.

## 0. What "bring-up" means here

The whole stack is **offline-verified** (firmware logic via `make test`, brain
via 115 Python tests, Android via `:core:test`). What remains is *physical*:
flash the XIAO, wire the I2S mic + OLED, connect real BLE peers, and field-test.
This doc is the bench checklist.

## 1. Toolchain

- **PlatformIO** (`platformio.ini`): `pio run -e xiao_st7735` (or `_128x64`
  / `_128x32`) to build + flash; `pio run -e native_test` for the host gate.
  (PlatformIO not installed locally — CI compiles `xiao_*`.)
- **Arduino IDE / CLI** optional for the Uno/Nano bench target.
- **esptool / UF2** for the XIAO if flashing over USB-C directly.
- **bleak** (Python) on the phone/PC for ring + G2 bridging without the XIAO.

## 2. Flash the XIAO

1. `pio run -e xiao_128x32` (Mini) or `xiao_st7735` (dev).
2. Connect XIAO over USB-C; `pio run -e <env> -t upload`.
3. Open serial @ 115200; expect the `CyclopsXIAO` NimBLE server to advertise.
4. With `-DENABLE_RING`, `ring.begin("R02_")` scans for the COLMI R02 on boot.

## 3. Wire I2S mic (onboard pads)

The XIAO S3 has an **onboard MEMS mic** — no external wiring for audio:
`MIC_BCLK=40`, `MIC_WS=41`, `MIC_DIN=42` (set in `main.cpp`). If using an
external I2S breakout, route those three pads + GND. `start_capture()` installs
I2S @ 16 kHz / 16-bit / left-only, streams `MSG_AUDIO_CHUNK`.

## 4. Wire the OLED / SPI screen

SPI on XIAO: `SCK=D8 MOSI=D10 MISO=D9`. Pick the panel:

| Panel | CS | DC | RST |
|---|----|----|-----|
| ST7735 128×128 | D7 | D2 | D1 |
| SSD1306 128×64 | D6 | D2 | D1 |
| SSD1306 128×32 | D5 | D2 | D1 |

Build with the matching `-DSCREEN_*`. DC=D2, RST=D1 shared across all three.

## 5. Input wiring (verified-free pins)

| Signal | Pin | Note |
|---|-----|---|
| Wheel A | D0 | quadrature, INT on CHANGE |
| Wheel B | D4 | quadrature |
| BTN_A | D3 | pull-up; short=select, long>600ms=back |
| BTN_B | D5 | pull-up; short=cancel/back (moved from D4 — was aliased to WHEEL_B) |

**BUG to avoid:** Do NOT put BTN_B on GPIO4 — it collides with WHEEL_B. Use D5.

## 6. Power the wearable

- **Dev:** USB-C 5 V, no battery circuit.
- **Untethered:** 3.7 V Li-Po → `BAT` pad through charge/protect; XIAO
  charger tops from USB-C. Keep draw < 300 mA.

## 7. Connect real BLE peers (phone hub)

Phone is the single BLE hub (premortem #1): bead/XIAO + G2 + ring each pair
only with the phone.
- **XIAO ↔ phone:** phone connects to `"CyclopsXIAO"` (service `4fafc201-…`),
  writes `DISPLAY_CMD`/`NOTE` to `NOTE_CH` `beb5483e-…`; XIAO pushes
  `MSG_CMD` + `MSG_STATUS`.
- **COLMI R02:** XIAO (`-DENABLE_RING`) or `device/colmi_r02.py` (bleak)
  scans `R02_*` and subscribes TX `6E400003-…`.
- **G2 glasses:** phone streams `HUD_FRAME` to the G2 BLE characteristic
  (chunked to MTU).

## 8. Field-test checklist

- [ ] XIAO boots, advertises, screen renders HOME.
- [ ] Wheel/buttons navigate MENU; long-press A backs out.
- [ ] `Transcribe` → mic captures → phone transcribes → NOTE appears on HUD.
- [ ] Ring connects, `HEALTH` shows HR/SpO2/batt.
- [ ] `HUD_FRAME` reaches G2 (≤4 lines, ≤18 chars each).
- [ ] Low-batt auto-sleep; vibration confirm (pending).
- [ ] Gyro nod/shake gestures (pending calibration).

## 9. Not verifiable headless (the bring-up scope)

- Actual I2S mic + OLED bench test (logic only, via native_test).
- Live BLE to physical R02 / G2 (no hardware on the bench).
- `pio run -e xiao_*` flash + field test (CI compiles only).
- Vibration motor, low-batt auto-sleep, gyro calibration.

---
**[inferred]** §2–§7 pin/power/I2S facts are taken from `main.cpp` +
`01-hardware.md` + `30-colmi-r02-integration.md` and should be accurate.
§1/§8/§9 framing follows `PLAN.md` "Next (hardware)" and the premortem docs.
Inferred only: the exact toolchain commands (esptool/UF2 specifics) and the
precise ordering of the bench steps.

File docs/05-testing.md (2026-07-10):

# Cyclops — Testing Strategy & Status

> **RECONSTRUCTED DOC** — original `docs/05-testing.md` (2026-06-15) lost on
> corrupted `/dev/sde2`, never bundled. Rebuilt 2026-07-10 from
> `tests/run_tests.py`, the test file list, `firmware/Makefile`, `PLAN.md`,
> `docs/00-superplan.md` and `04-release-v0.4.md`. **[inferred]** = guessed.

## 0. Principle (premortem #10)

> "No tests because it needs hardware" is a failure mode. Everything has a host
> build + fake transports; CI runs the full pipeline with stub audio. Hardware is
> a runtime detail, not a build blocker.

Every component ships with an **offline test** — no keys, no network, no device.

## 1. Test runner

`tests/run_tests.py` — **zero-dependency** harness (stdlib only). Run:

```
python3 tests/run_tests.py tests/test_*.py
```

At v0.4: **115 tests pass** (was 26 at the start of the recursive loop).

## 2. Test inventory (by area)

| File | Covers |
|---|---|
| `test_wire_contract.py` | v1 framing + CRC round-trip, every message type |
| `test_v2.py` | v2 peers / time-sync / health / HUD_FRAME encoding |
| `test_colmi_r02.py` | ring 16-byte parser (checksum, battery, HR/SpO2, error/CRC rejection, builders) — 6 cases |
| `test_brain.py` | brain: transcribe→extract→store→display glue |
| `test_pipeline.py` | end-to-end pipeline |
| `test_bridge.py` / `test_hud_bridge.py` / `test_hud_bridge_stream.py` | `HudBridge`: MSG_CMD → note + DISPLAY_CMD push; streaming |
| `test_extractor_unified.py` / `test_llm_extractor.py` | rule + LLM extraction, fallback |
| `test_search.py` | semantic + keyword note search (T3.1) |
| `test_transcriber_cloud.py` / `test_cloud_transcriber.py` | cloud STT adapter (key-gated, offline skip) |
| `test_agent_core.py` / `test_agent_endpoint.py` / `test_agent_history.py` / `test_agent_memory.py` | agent loop with fake model + fake tools; history + memory write-back |
| `test_tools_expanded.py` | expanded tool set (whatsapp/media/device registry) |
| `test_tui.py` | TUI constructs + routes a fake turn |
| `test_app_api.py` | web dashboard JSON API |
| `test_settings_profile.py` | persona/profile round-trip |
| `test_aikeys.py` | provider key store (.env precedence) |
| `test_device.py` / `test_device_transport.py` | device codec (serial/ble/cable), transport registry |
| `test_vision_tool.py` | vision tool (offline-stubbed) |

## 3. Firmware host gate (no PlatformIO needed)

`firmware/Makefile` compiles the logic with g++ and runs the native suites:

```
make test     # g++ Hud logic (9 cmds) + COLMI R02 parser block — ALL PASS
make proto    # CRC/framing round-trip
```

- `firmware/shared/test_hud.cpp` — stack push/pop, menu select, confirm
  yes/no, teleprompter paging, note-detail scroll, long-press back.
- `firmware/shared/test_shared.cpp` — protocol/CRC.
- Plus the new ring-protocol block (parser identical to Python).

`pio run -e native_test` is the PlatformIO equivalent of the host gate.

## 4. Android (Kotlin) tests

`:core` module carries offline parser/contract tests (`RingProtoTest.kt`,
protocol round-trips) run by `gradle :core:test` / the CI `Build Companion APK`
workflow. v0.4: `:core` Kotlin tests + debug/release APKs all SUCCESS.

## 5. CI (GitHub Actions)

- `ci.yml` — firmware `native_test` + `xiao_st7735` compiles on every push to
  `cyclops`; Python suite.
- `build-apk.yml` — Android APK (debug + release) on `android/**` changes;
  uploads artifact (no local SDK needed).
- Both green at v0.4.

## 6. What is NOT covered headless

- Live BLE connect to a physical R02 / G2 (no hardware on the bench).
- `pio run -e xiao_*` flash + on-metal pin/field test (CI compiles only).
- Real transcription/extraction quality (models stubbed or key-gated).
- Vibration motor, gyro calibration, Li-Po runtime.

---
**[inferred]** The runner, the v0.4 115-count, the firmware `make test` host
gate, the Android `:core:test`, and the two CI workflows are all stated in
committed docs/source and should be accurate. The per-file coverage column is a
reconstruction from file names + what the adjacent docs describe; exact test
counts per file are inferred.

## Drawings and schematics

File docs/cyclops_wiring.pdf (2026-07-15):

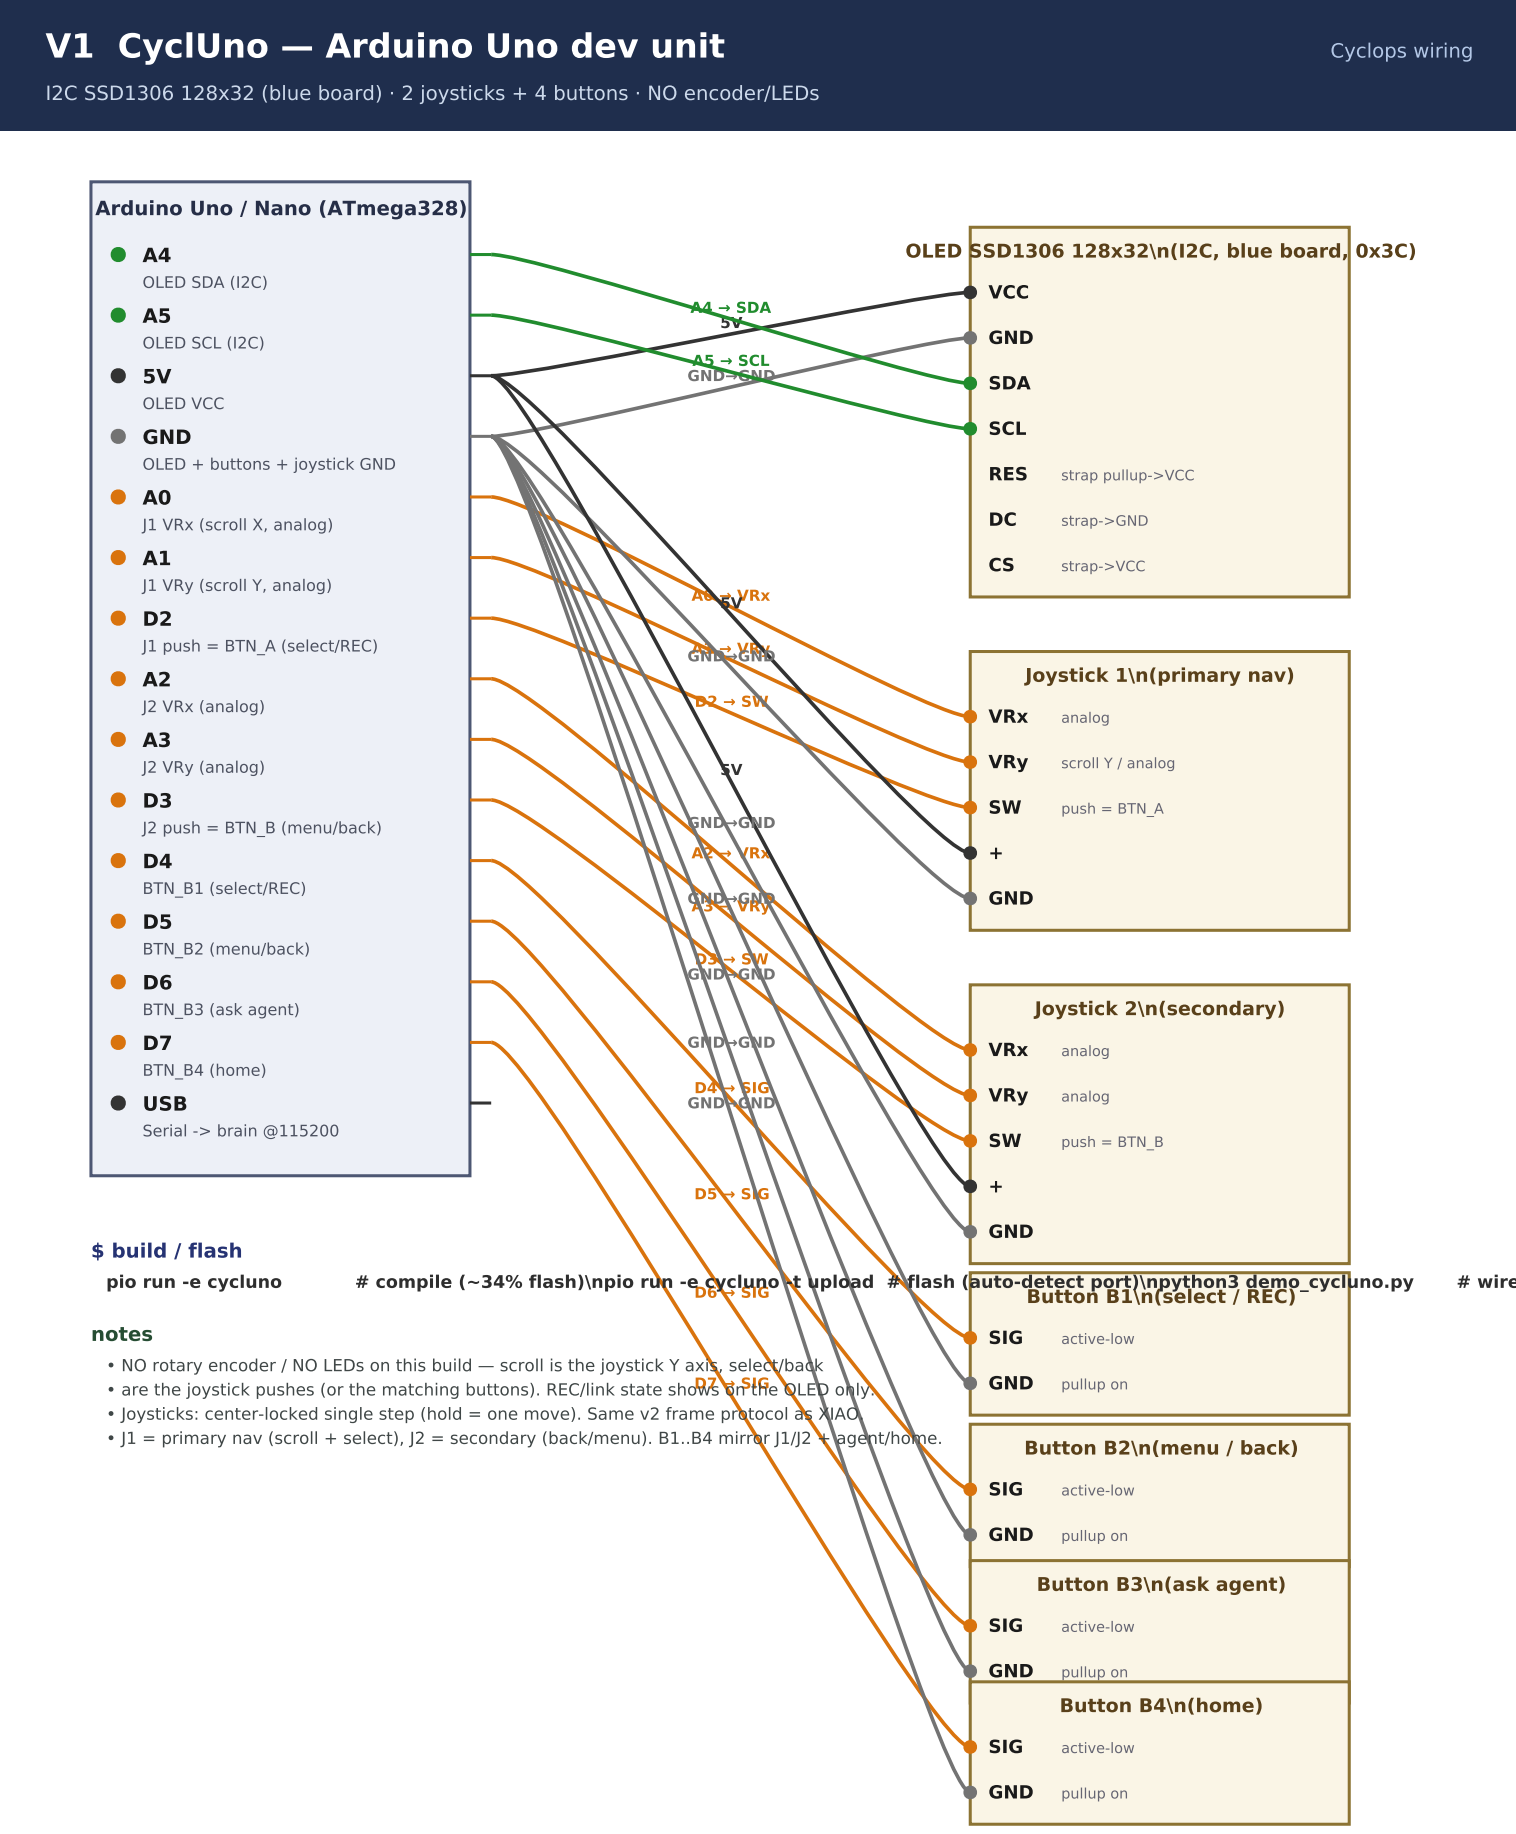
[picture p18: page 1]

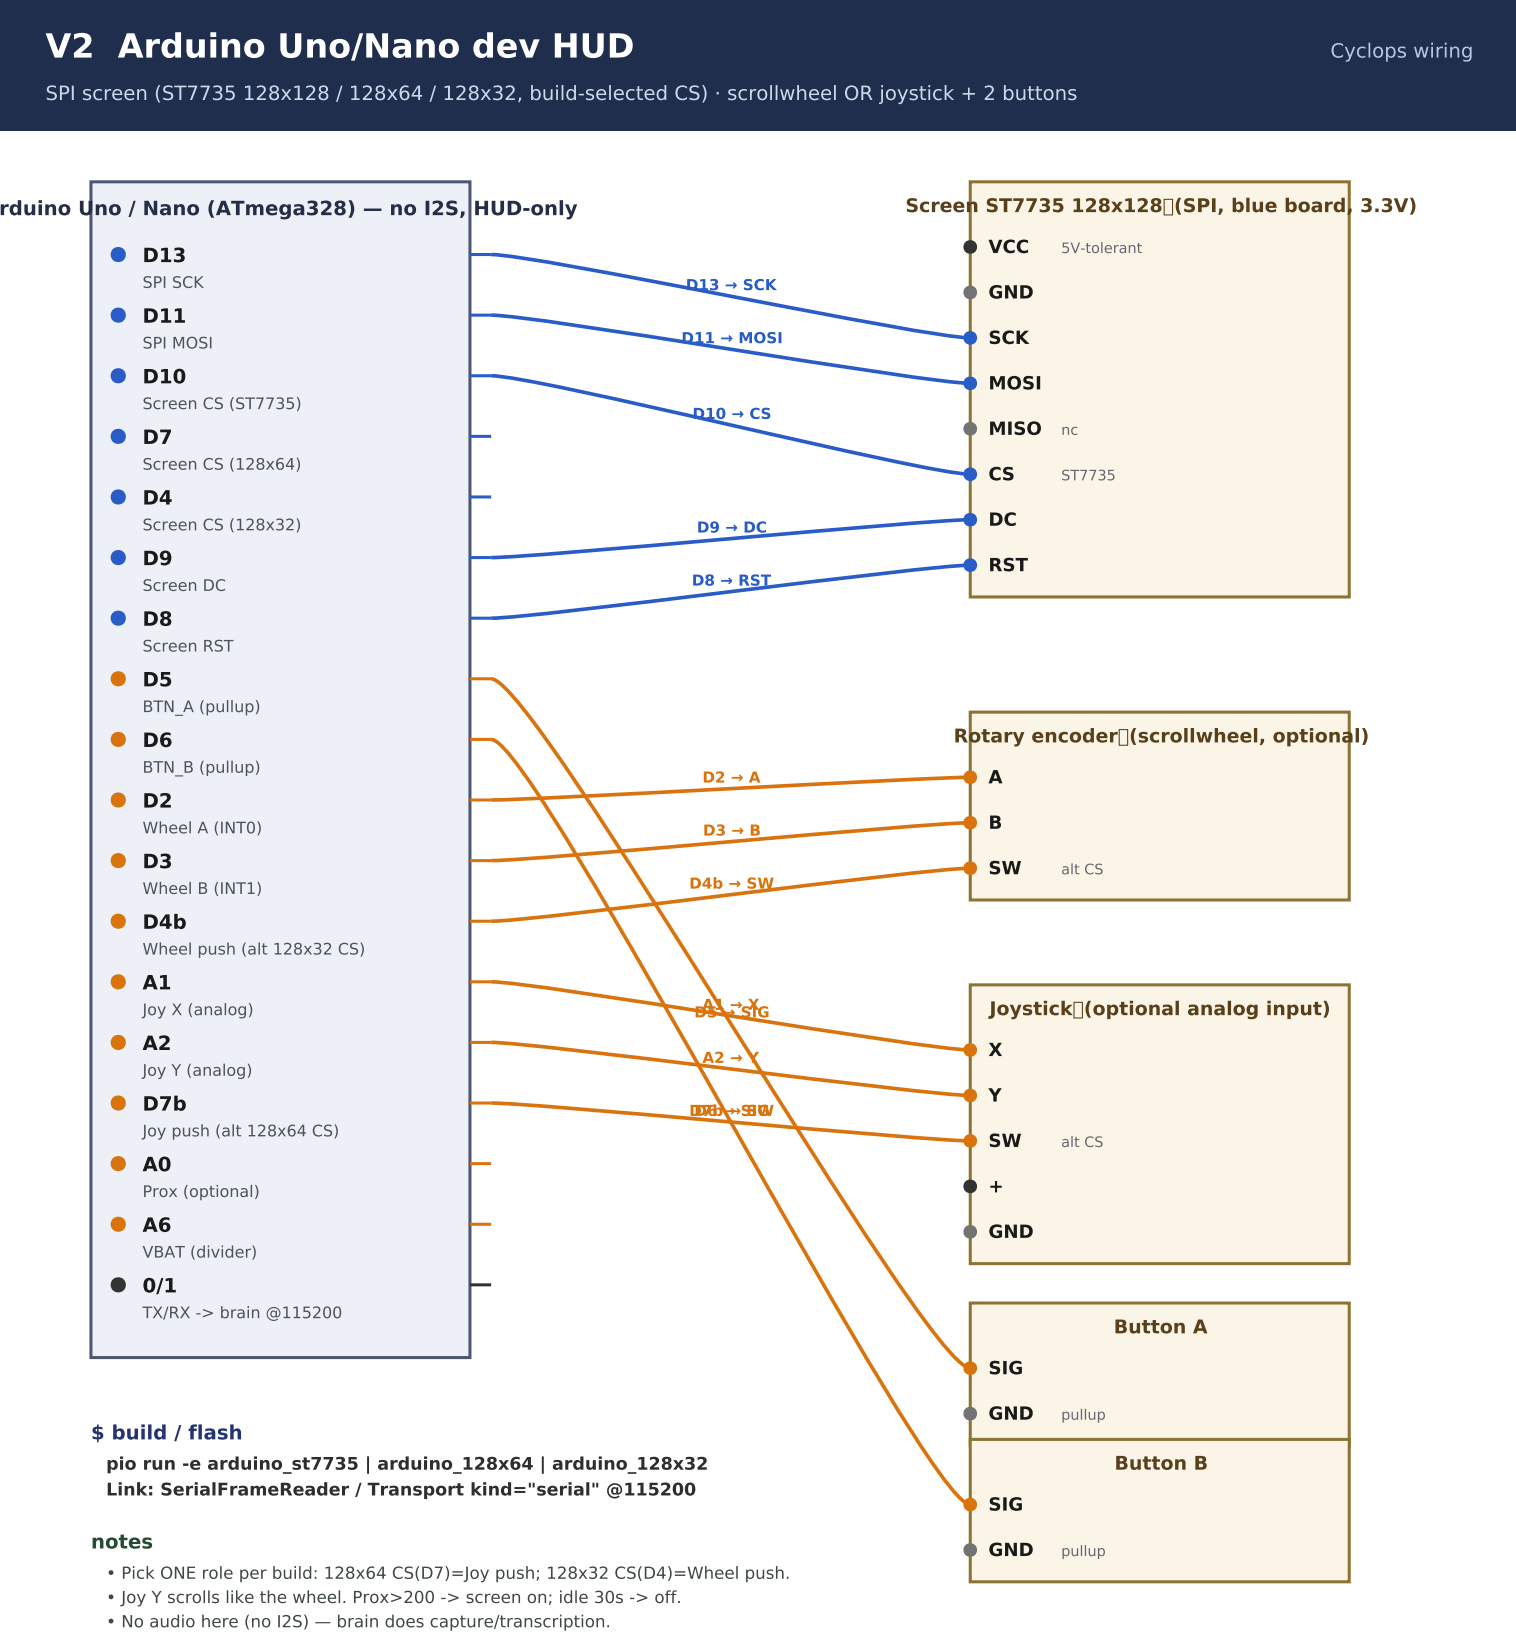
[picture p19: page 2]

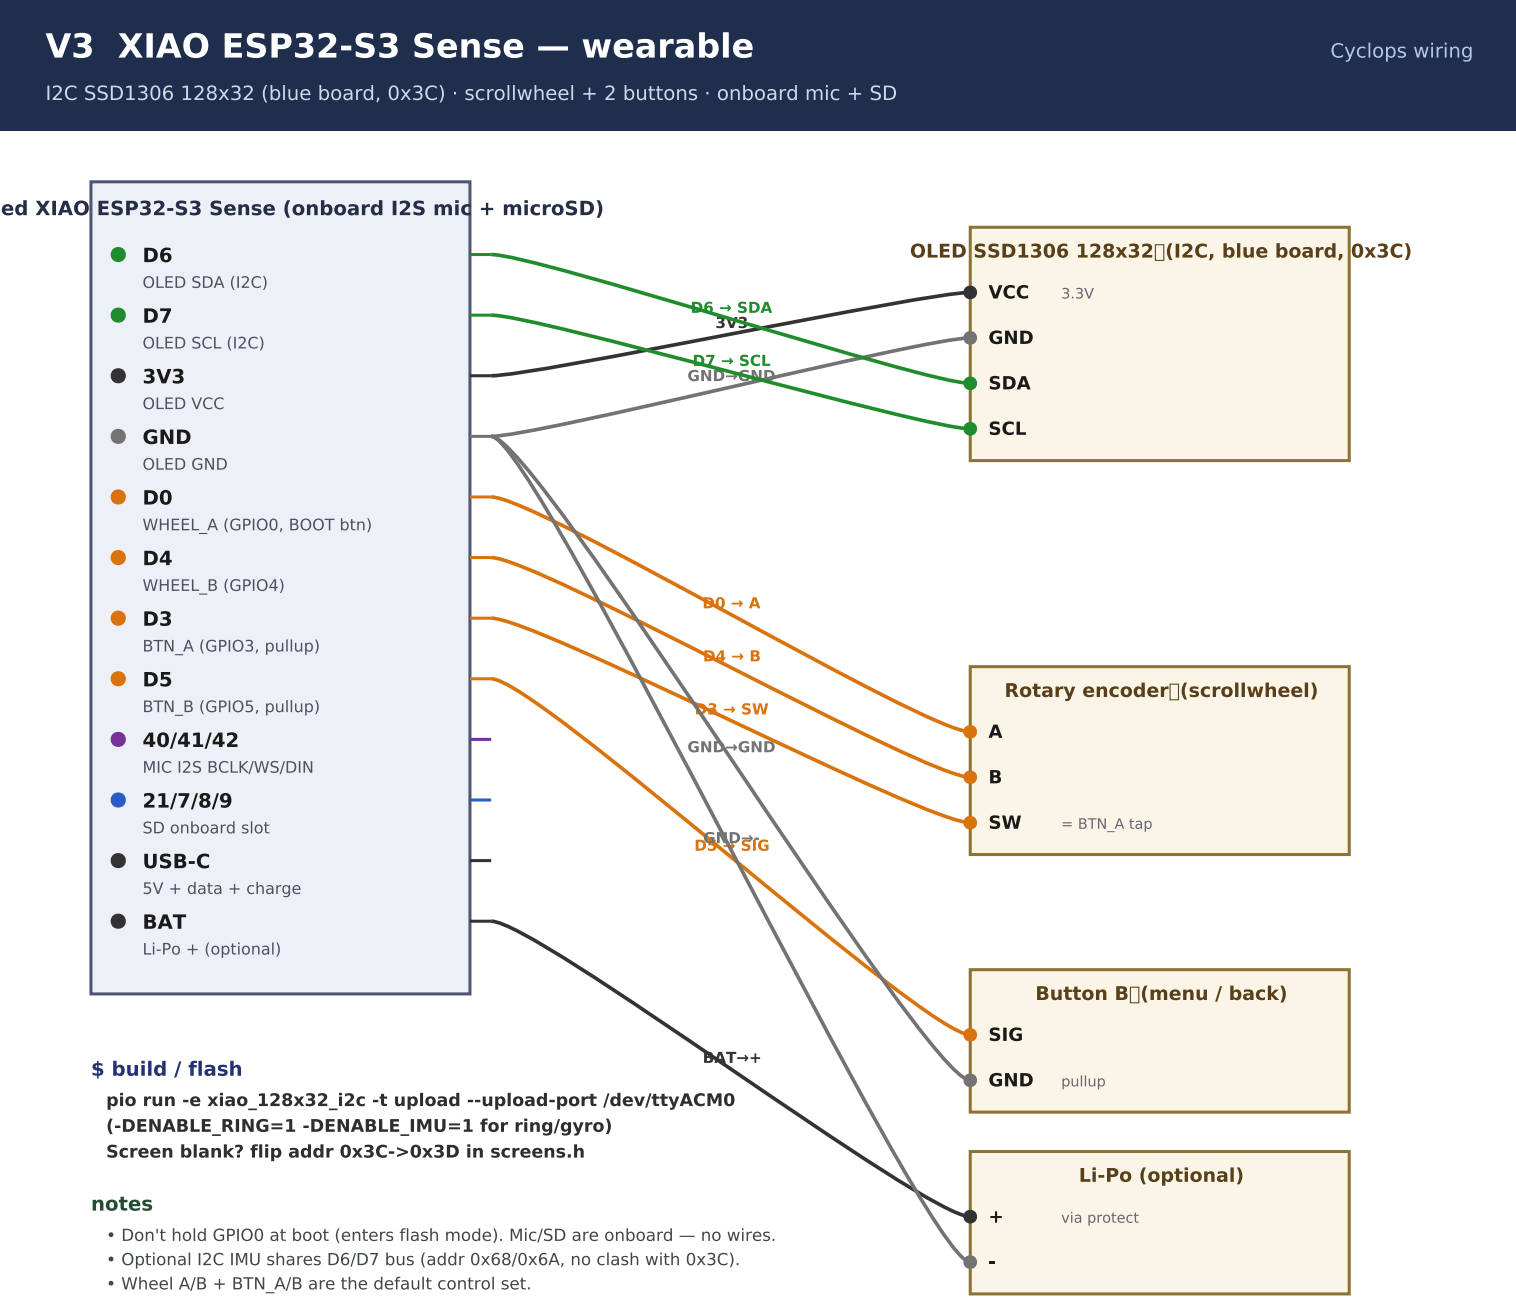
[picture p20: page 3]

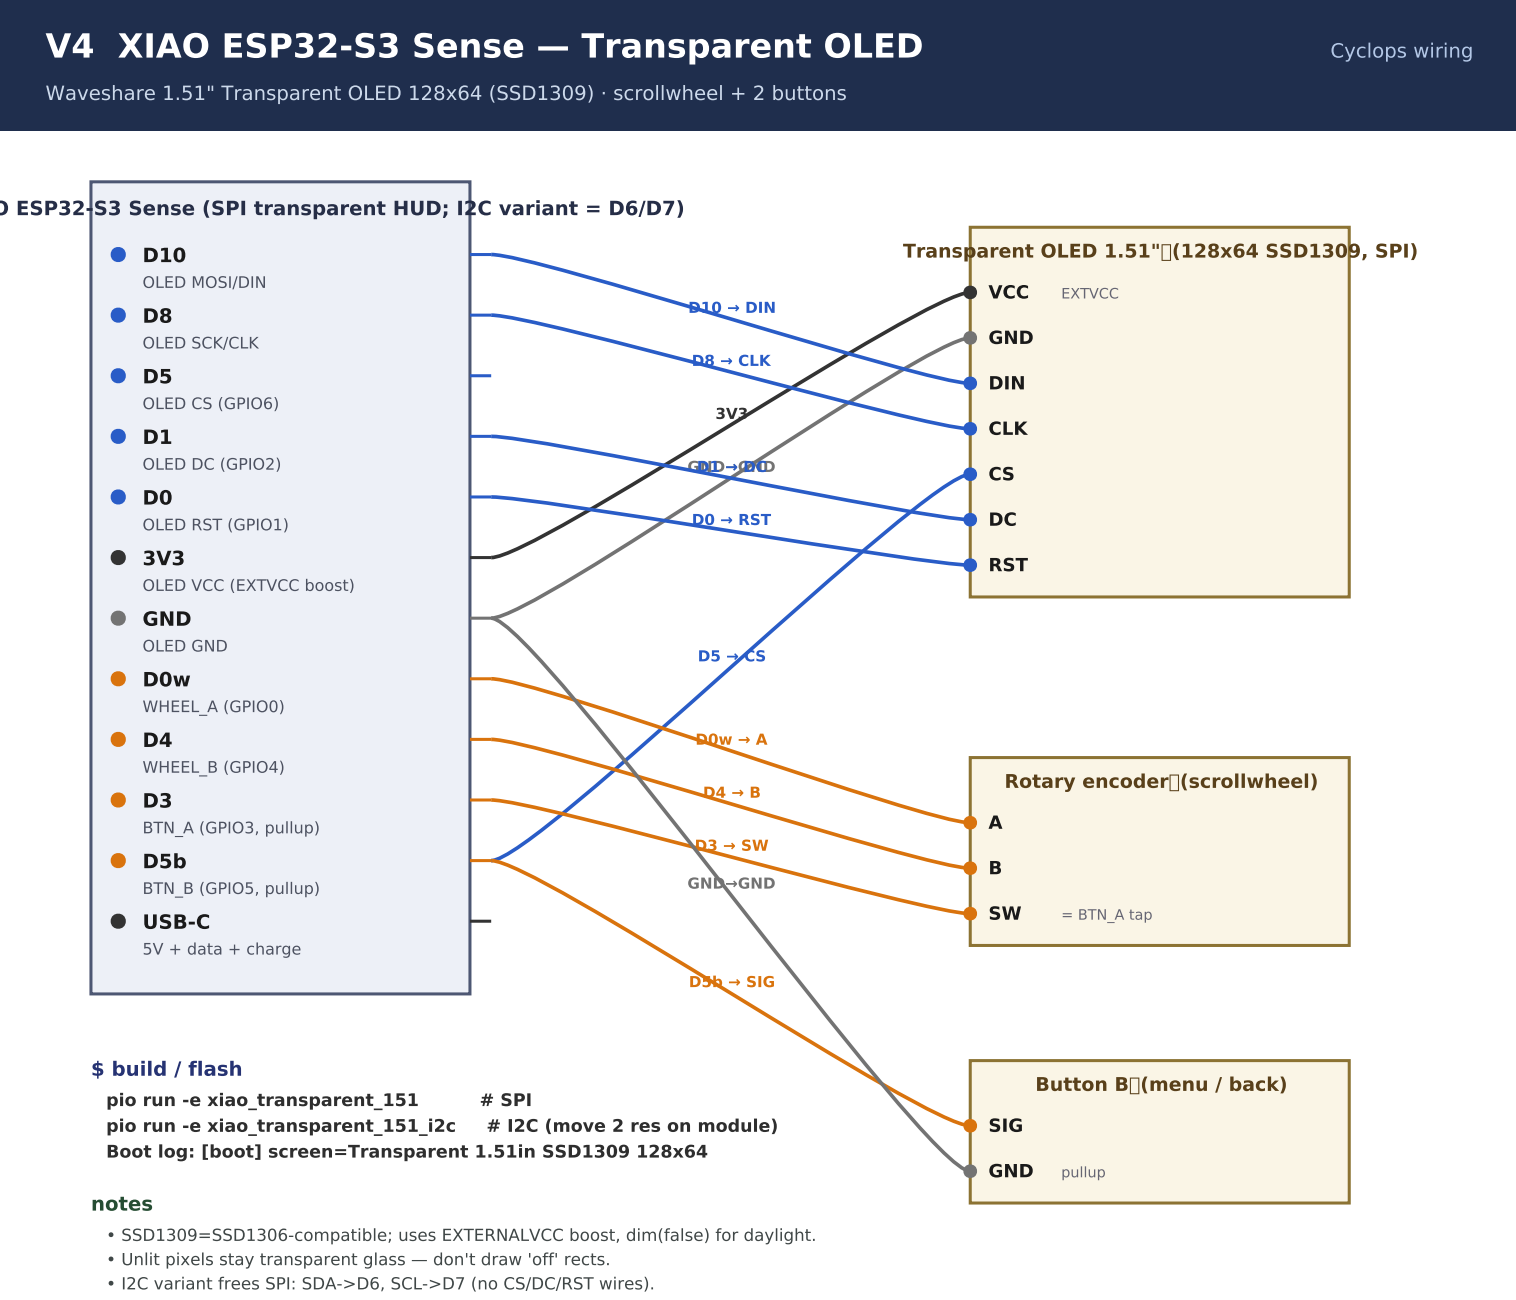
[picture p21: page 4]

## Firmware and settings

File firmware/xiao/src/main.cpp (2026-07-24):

// Cyclops XIAO ESP32-S3 Sense — wearable HUD + audio capture.
// scrollwheel + 2 buttons + screen (ST7735 / 128x64 / 128x32 via SCREEN_*).
// PDM mic (clk 42, data 41) -> ADPCM -> BLE audio chunks -> phone decodes+transcribes.
// BLE (NimBLE) to phone. Shares Hud + Screen.
// Build: pio run -e xiao_st7735 | xiao_128x64 | xiao_128x32
#include "cyclops_shared.h"
#include "screen.h"
#include "screens.h"
#include "hud.h"
#include "gestures.h"
#include "adpcm.h"
#include "ota.h"
#include <esp_ota_ops.h>
#include "ring_ble.h"
#include "sd_log.h"
#include "imu.h"
#include "presence.h"
#include "posture.h"
#include "audio_trigger.h"
#include "camera_capture.h"
#include <Wire.h>
#include <NimBLEDevice.h>
#include <driver/i2s.h>

#if defined(SCREEN_ST7735)
// XIAO S3: HW-SPI SCK=GPIO7(D8) MOSI=GPIO9(D10) MISO=GPIO8(D9).
// CS=GPIO6(D5) DC=GPIO2(D1) RST=GPIO1(D0). CS must NOT be GPIO7 (that's SCK).
static cyclops::St7735Screen screen(6, 2, 1, 8, 10, 9);
#elif defined(SCREEN_128x64)
static cyclops::Ssd1306_128x64_Screen screen(6, 2, 1, 8, 10, 9, 1);
#elif defined(SCREEN_128x32)
static cyclops::Ssd1306_128x32_Screen screen(5, 2, 1, 8, 10, 9, 1);
#elif defined(SCREEN_128x32_I2C)
// 4-pin I2C OLED: only SDA/SCL/VCC/GND wired. SPI args ignored, rst_pin=-1.
static cyclops::Ssd1306_128x32_I2C_Screen screen(0, 0, 0, 0, 0, 0, -1);
#elif defined(SCREEN_TRANSPARENT_151)
// Waveshare 1.51" transparent OLED (128x64, SSD1309), 4-wire SPI.
// CS=GPIO6(D5) DC=GPIO2(D1) RST=GPIO1(D0). SCK=GPIO7 MOSI=GPIO9 MISO=GPIO8.
static cyclops::Transparent151Screen screen(6, 2, 1, 8, 10, 9, 1);
#elif defined(SCREEN_TRANSPARENT_151_I2C)
// Waveshare 1.51" transparent OLED in I2C mode: only SDA/SCL/VCC/GND wired.
static cyclops::Transparent151I2CScreen screen(0, 0, 0, 0, 0, 0, -1);
#endif

#define PIN_WHEEL_A 0
#define PIN_WHEEL_B 4
#define PIN_BTN_A  3
#define PIN_BTN_B  5   // was 4 (aliased WHEEL_B); GPIO5 is free on XIAO S3

// Onboard mic (XIAO S3 Sense MSM261D) is a PDM mic: clock GPIO42, data GPIO41.
// Verified on metal 2026-07-12 — standard I2S on 40/41/42 reads silence, and
// GPIO40 is the camera's SCCB SDA. PDM mode is the only correct config here.
#ifndef MIC_PDM_CLK
#define MIC_PDM_CLK 42
#endif
#ifndef MIC_PDM_DATA
#define MIC_PDM_DATA 41
#endif
#define MIC_RATE 16000
#define MIC_BUF_SAMPLES 256

static cyclops::Hud hud;
#ifdef ENABLE_RING
static cyclops::RingBle ring;          // COLMI R02 BLE central (opt-in)
#endif
#ifdef ENABLE_IMU
static cyclops::Imu imu(0x68, 1);      // HW-123 ITG/MPU on I2C (D6/D7), INT->D1
// Off-body privacy gate: a device resting on a surface reads a near-constant
// gravity vector for 4s straight -> consent forced off + any capture already
// running is force-stopped. This must be a firmware-local invariant (holds
// even with the BLE link down), same fail-closed principle as the phone-side
// HITL gate. Re-worn (motion resumes) restores consent immediately.
static cyclops::PresenceDetector presence;
// Posture cue: calibrated to "neutral" on first read after boot and again
// whenever the device is re-worn (presence edge on->off->on), since pin/
// lapel mounting angle isn't fixed. 30 deg sustained 10 min, per the product
// pitch; breathing-rate is real DSP work (chest-rise extraction), deferred.
static cyclops::PostureDetector posture(30, 600000);
#endif
static NimBLEServer* srv;
static NimBLECharacteristic* note_ch;
static NimBLECharacteristicCallbacks* note_cb = nullptr;
static const char* SRVC = "4fafc201-1fb5-459e-8fcc-c5c9c331914b";
static const char* NOTE_CH = "beb5483e-36e1-4688-b7f5-ea07361b26a8";

static void on_frame(uint8_t type, const uint8_t* p, size_t n, void* ctx);
static void send_cmd(uint8_t act, const char* arg);
static void send_frame(uint8_t type, const uint8_t* p, size_t n);
static void ui_apply_display(const char* json);
static void start_capture();
static void stop_capture();
static void audio_task(void*);

static cyclops::FrameDecoder dec(on_frame, nullptr);
static bool capturing = false;
static TaskHandle_t cap_task = nullptr;
// Sudden loud-sound tier (#6): only runs on chunks already being read for an
// active capture — piggybacks on the existing mic path rather than adding a
// new always-on listen loop, which would need real hardware to power/false-
// positive tune before it's safe to leave running unattended. Set by
// audio_task (a separate FreeRTOS task); loop() picks it up on the main task
// so hud.notify() is only ever touched from one task, same as `capturing`'s
// existing plain-bool cross-task convention.
static cyclops::AudioTrigger audio_trigger;
static volatile bool loud_flag = false;
// Deferred ACT_PHOTO handoff from BLE-callback-context to the main loop
// task -- see hud.on_photo below for why this can't just do the work inline.
static volatile bool photo_flag = false;
// On-demand photo capture (#1): camera + WiFi + HTTP come up only when a
// photo is actually requested, torn down after 60s idle. See camera_capture.h.
static cyclops::CameraCapture camera_capture;

class NoteCb : public NimBLECharacteristicCallbacks {
    void onWrite(NimBLECharacteristic* c) override {
        std::string v = c->getValue();
        for (size_t i = 0; i < v.size(); ++i) dec.push((uint8_t)v[i]);
    }
};

volatile int wheel_ticks = 0;
static void IRAM_ATTR wheel_isr() {
    static uint8_t last = 0;
    uint8_t a = digitalRead(PIN_WHEEL_A);
    uint8_t b = digitalRead(PIN_WHEEL_B);
    if (a != last) { wheel_ticks += (a == b) ? 1 : -1; last = a; }
}

// ---- OTA-over-BLE receive path (shared OtaReceiver + esp_ota_* sinks) ----
// Rationale: the USB-C connector is the board's weakest part (one died
// 2026-07-12 with a live chip behind a dead port). BLE reflash means a broken
// connector no longer strands the firmware. Trust model matches the rest of
// the link (unauthenticated, ~1 m body range — see docs/07 §4).
static esp_ota_handle_t ota_handle = 0;
static const esp_partition_t* ota_part = nullptr;

static bool ota_sink_begin(uint32_t size, void*) {
    ota_part = esp_ota_get_next_update_partition(NULL);
    if (!ota_part) return false;  // no OTA partition in the table
    return esp_ota_begin(ota_part, size, &ota_handle) == ESP_OK;
}
static bool ota_sink_write(const uint8_t* d, size_t len, void*) {
    return esp_ota_write(ota_handle, d, len) == ESP_OK;
}
static bool ota_sink_finish(bool commit, void*) {
    if (!commit) { esp_ota_abort(ota_handle); return true; }
    if (esp_ota_end(ota_handle) != ESP_OK) return false;
    return esp_ota_set_boot_partition(ota_part) == ESP_OK;
}
static cyclops::OtaSink make_ota_sink() {
    cyclops::OtaSink s;
    s.begin = ota_sink_begin;
    s.write = ota_sink_write;
    s.finish = ota_sink_finish;
    s.ctx = nullptr;
    return s;
}
static cyclops::OtaReceiver& ota_rx() {
    static cyclops::OtaReceiver rx(make_ota_sink());
    return rx;
}

// Handle one MSG_OTA_* frame: drive the receiver, ACK every message, show
// progress on the HUD, reboot after a committed END.
static void on_ota_frame(uint8_t type, const uint8_t* p, size_t n) {
    uint32_t seq = 0;
    cyclops::OtaStatus st;
    if (type == cyclops::MSG_OTA_BEGIN) {
        st = ota_rx().on_begin(p, n, &seq);
        if (st == cyclops::OTA_OK) { hud.notify("OTA start", cyclops::Hud::NOTE_INFO, 3); hud.progress = 0; }
    } else if (type == cyclops::MSG_OTA_CHUNK) {
        st = ota_rx().on_chunk(p, n, &seq);
        uint32_t exp = ota_rx().expected();
        if (st == cyclops::OTA_OK && exp) hud.progress = (int)(100ull * ota_rx().received() / exp);
    } else {  // MSG_OTA_END
        st = ota_rx().on_end(&seq);
    }
    char ack[48]; int m = cyclops::OtaReceiver::ack_json(ack, sizeof(ack), seq, st);
    send_frame(cyclops::MSG_OTA_ACK, (const uint8_t*)ack, (size_t)m);
    if (type == cyclops::MSG_OTA_END && st == cyclops::OTA_OK) {
        hud.notify("OTA ok, reboot", cyclops::Hud::NOTE_OK, 2);
        cyclops::sd_log_line("ota", "commit + reboot");
        delay(400);  // let the ACK notify flush before the link drops
        esp_restart();
    } else if (st != cyclops::OTA_OK) {
        hud.progress = 0;
        hud.notify("OTA fail", cyclops::Hud::NOTE_ERR, 3);
    }
}

static void on_frame(uint8_t type, const uint8_t* p, size_t n, void* ctx) {
    (void)ctx;
    if (type == cyclops::MSG_OTA_BEGIN || type == cyclops::MSG_OTA_CHUNK ||
        type == cyclops::MSG_OTA_END) {
        on_ota_frame(type, p, n);  // binary payload — must not go through tmp
        return;
    }
    char tmp[256]; if (n >= sizeof(tmp)) n = sizeof(tmp)-1;
    memcpy(tmp, p, n); tmp[n] = 0;
    if (type == cyclops::MSG_DISPLAY_CMD || type == cyclops::MSG_NOTE) {
        ui_apply_display(tmp);
        if (type == cyclops::MSG_NOTE) cyclops::sd_log_line("note", tmp);
    }
    else if (type == cyclops::MSG_HEALTH_SAMPLE) {
        hud.on_health_sample(tmp);  // P2-C relay
        cyclops::sd_log_line("health", tmp);
    }
    else if (type == cyclops::MSG_CMD) {
        // Phone -> wearable action, same {"a":<ACT_*>,"arg":...} shape the
        // wearable emits. Lets the brain drive capture/menu remotely instead
        // of only reacting to on-device input.
        const char* av = strstr(tmp, "\"a\":");
        if (av) {
            int a = atoi(av + 4);
            if (a == cyclops::ACT_TRANSCRIBE_START) {
                // Same consent gate as on-device capture (on_nod/do_action):
                // remote start must not bypass Consent Mode.
                if (!capturing && !hud.consent) { hud.notify("consent off", cyclops::Hud::NOTE_WARN, 2); }
                else if (capturing) stop_capture();
                else start_capture();
            } else {
                hud.do_action((uint8_t)a);
            }
        }
    }
}

static void ui_apply_display(const char* json) {
    hud.apply_display_cmd(json);
}

static void send_cmd(uint8_t act, const char* arg) {
    uint8_t buf[300];
    char payload[200]; int pl = snprintf(payload, sizeof(payload), "{\"a\":%u,\"arg\":\"%s\"}", act, arg ? arg : "");
    size_t k = cyclops::encode_frame(cyclops::MSG_CMD, (uint8_t*)payload, pl, buf, sizeof(buf));
    if (note_ch) { note_ch->setValue(buf, k); note_ch->notify(); }
}

static void send_frame(uint8_t type, const uint8_t* p, size_t n) {
    uint8_t buf[400]; size_t k = cyclops::encode_frame(type, p, n, buf, sizeof(buf));
    if (note_ch) { note_ch->setValue(buf, k); note_ch->notify(); }
}

class SrvCb : public NimBLEServerCallbacks {
    void onConnect(NimBLEServer*) override { hud.bt = true; }
    void onDisconnect(NimBLEServer*) override { hud.bt = false; }
};

// Raw PCM16 at 16 kHz is 32 KB/s; the BLE notify link measures ~2-8 KB/s
// (docs/13 premortem #2), so raw streaming can never keep up. Compress each
// read with IMA ADPCM (4:1, shared/include/adpcm.h): a 256-sample read
// becomes 4+128 = 132 B — one notify-sized frame, no slicing. The step index
// is carried across chunks (warm adaption); each chunk stays self-contained
// so a lost notify costs only its own ~16 ms window.
static void audio_task(void*) {
    int16_t samples[MIC_BUF_SAMPLES];
    uint8_t enc[4 + (MIC_BUF_SAMPLES + 1) / 2];
    int adpcm_index = 0;
    size_t rd;
    while (capturing) {
        i2s_read((i2s_port_t)0, samples, sizeof(samples), &rd, pdMS_TO_TICKS(100));
        if (rd > 0) {
            if (audio_trigger.feed(samples, rd / 2, millis())) loud_flag = true;
            // Backpressure: only stream audio when a phone is actually
            // connected to receive it. Sending into the void wastes the BLE
            // queue and battery; drop the chunk instead. (D)
            if (hud.bt) {
                size_t k = cyclops::adpcm_encode_chunk(samples, rd / 2, enc,
                                                       sizeof(enc),
                                                       adpcm_index, &adpcm_index);
                if (k > 0) send_frame(cyclops::MSG_AUDIO_CHUNK, enc, k);
            } else {
                cyclops::audio_dropped++;  // no consumer -> drop
            }
        }
    }
    vTaskDelete(NULL);
}

static void start_capture() {
    if (capturing) return;
    i2s_config_t cfg = {};
    cfg.mode = (i2s_mode_t)(I2S_MODE_MASTER | I2S_MODE_RX | I2S_MODE_PDM);
    cfg.sample_rate = MIC_RATE;
    cfg.bits_per_sample = I2S_BITS_PER_SAMPLE_16BIT;
    cfg.channel_format = I2S_CHANNEL_FMT_ONLY_LEFT;
    cfg.communication_format = I2S_COMM_FORMAT_STAND_I2S;
    cfg.intr_alloc_flags = 0;
    cfg.dma_buf_count = 4; cfg.dma_buf_len = MIC_BUF_SAMPLES;
    i2s_pin_config_t pins = {};
    // PDM RX: ws pin carries the PDM clock, data_in the PDM bitstream.
    pins.mck_io_num = I2S_PIN_NO_CHANGE;
    pins.bck_io_num = I2S_PIN_NO_CHANGE; pins.ws_io_num = MIC_PDM_CLK;
    pins.data_in_num = MIC_PDM_DATA; pins.data_out_num = I2S_PIN_NO_CHANGE;
    i2s_driver_install((i2s_port_t)0, &cfg, 0, NULL);
    i2s_set_pin((i2s_port_t)0, &pins);
    capturing = true;
    // announce format once: bits, rate, channels, codec (meta[5])
    uint8_t meta[8]; meta[0]=16; meta[1]=0; meta[2]=MIC_RATE&0xFF; meta[3]=(MIC_RATE>>8)&0xFF;
    meta[4]=1; meta[5]=cyclops::AUDIO_CODEC_ADPCM; meta[6]=0; meta[7]=0;
    send_frame(cyclops::MSG_AUDIO_META, meta, 8);
    xTaskCreatePinnedToCore(audio_task, "cap", 4096, NULL, 5, &cap_task, 0);
    hud.recording = true;
    cyclops::sd_log_line("rec", "start");
}

static void stop_capture() {
    if (!capturing) return;
    capturing = false;
    delay(120);
    i2s_driver_uninstall((i2s_port_t)0);
    send_frame(cyclops::MSG_AUDIO_STOP, NULL, 0);
    hud.recording = false;
    cyclops::sd_log_line("rec", "stop");
}

void setup() {
    Serial.begin(115200);
    Serial.println("[boot] Cyclops XIAO S3 Sense");
#ifdef SCREEN_ST7735
    Serial.println("[boot] screen=ST7735 128x128");
#elif defined(SCREEN_128x64)
    Serial.println("[boot] screen=SSD1306 128x64");
#elif defined(SCREEN_128x32)
    Serial.println("[boot] screen=SSD1306 128x32");
#elif defined(SCREEN_TRANSPARENT_151)
    Serial.println("[boot] screen=Transparent 1.51in SSD1309 128x64");
#elif defined(SCREEN_TRANSPARENT_151_I2C)
    Serial.println("[boot] screen=Transparent 1.51in SSD1309 128x64 (I2C)");
#endif
    screen.begin();
    Serial.println("[boot] screen.begin ok");
    pinMode(PIN_BTN_A, INPUT_PULLUP); pinMode(PIN_BTN_B, INPUT_PULLUP);
    pinMode(PIN_WHEEL_A, INPUT_PULLUP); pinMode(PIN_WHEEL_B, INPUT_PULLUP);
    attachInterrupt(digitalPinToInterrupt(PIN_WHEEL_A), wheel_isr, CHANGE);
    hud.send_cmd = send_cmd;
    hud.on_transcribe_toggle = []() { if (capturing) stop_capture(); else start_capture(); };
    hud.on_note = [](const char* t) { cyclops::sd_log_line("hud", t); };
    // Deliberately just sets a flag -- do_action(ACT_PHOTO) (and therefore
    // this callback) can run on the NimBLE host task's own stack when
    // triggered by a phone-relayed MSG_CMD (on_frame() -> do_action() is
    // called directly from the GATT write callback), not the main loop
    // task. That stack is small by default; esp_camera_init()'s local
    // camera_config_t plus WiFi.begin()'s blocking join loop, run directly
    // on it, is a real overflow risk -- and a strong suspect for the
    // "sd_ready() false right after camera init succeeds" bug seen live on
    // metal (smashed static BSS is exactly this failure's shape). The
    // actual capture work now happens in loop() on the main task instead;
    // see photo_flag below. The immediate cmd(ACT_PHOTO,"") notify is
    // cheap/safe here -- it's just a function-pointer call, no blocking I/O.
    hud.on_photo = []() -> const char* { photo_flag = true; return ""; };
    hud.init();
    Serial.println("[boot] hud.init ok");
    if (cyclops::sd_begin()) Serial.println("[boot] sd card mounted /sdcard");
    else Serial.println("[boot] sd card NOT present (logging disabled)");
    NimBLEDevice::init("CyclopsXIAO");
    srv = NimBLEDevice::createServer();
    srv->setCallbacks(new SrvCb());
    NimBLEService* s = srv->createService(SRVC);
    note_ch = s->createCharacteristic(NOTE_CH, NIMBLE_PROPERTY::READ | NIMBLE_PROPERTY::NOTIFY | NIMBLE_PROPERTY::WRITE);
    note_cb = new NoteCb();
    note_ch->setCallbacks(note_cb);
    s->start();
    NimBLEAdvertising* adv = NimBLEDevice::getAdvertising();
    adv->addServiceUUID(SRVC);
    adv->start();
#ifdef ENABLE_RING
    ring.begin("R02_");   // scan for + connect to the COLMI R02 (see docs/30)
#endif
#ifdef ENABLE_IMU
    if (imu.begin()) Serial.println("[boot] imu ok");
    else Serial.println("[boot] imu NOT found (0x68)");
#endif
}

static uint32_t last_hb=0;
static cyclops::GestureDetector gest_a, gest_b;   // A="eye", B="ear"

void loop() {
    static int prev = 0;
    if (wheel_ticks != prev) { hud.on_wheel(wheel_ticks - prev > 0 ? 1 : -1); prev = wheel_ticks; }
    uint32_t now = millis();
    if (loud_flag) {
        loud_flag = false;
        hud.notify("loud sound detected", cyclops::Hud::NOTE_WARN, 3);
        cyclops::sd_log_line("audio_trigger", "loud");
    }
    if (photo_flag) {
        photo_flag = false;
        const char* url = camera_capture.request(now);
        if (url[0]) cyclops::sd_log_line("photo", url);
        else hud.toast("photo: no wifi.txt / cam fail", 3);
        hud.notify_result(cyclops::ACT_PHOTO, url);
    }
    camera_capture.tick(now);
    // buttons are active-low; detector wants pressed=true
    cyclops::Gesture ga = gest_a.poll(!digitalRead(PIN_BTN_A), now);
    cyclops::Gesture gb = gest_b.poll(!digitalRead(PIN_BTN_B), now);
    if (ga) hud.fire_gesture(0, ga);   // A: single=OK double=photo long=video
    if (gb) hud.fire_gesture(1, gb);   // B: single=back double=voice-note long=voice-cmd
#ifdef ENABLE_RING
    ring.update();
    if (ring.connected()) {
        const auto& s = ring.sample();
        hud.set_health(s.hr, s.spo2, s.battery, s.battery);  // ring_batt == bead_batt slot
    }
#endif
#ifdef ENABLE_IMU
    if (imu.update()) {
        hud.nav_head = imu.sample().heading;           // tilt/nav heading
        int tilt = imu.scroll_tilt();
        if (tilt != 0) hud.on_wheel(tilt);             // tilt = scroll
        const auto& s = imu.sample();
        bool off = presence.poll(s.ax, s.ay, s.az, now);
        if (presence.changed()) {
            hud.set_consent(!off);
            if (off && capturing) stop_capture();  // guarantee, not just a future gate
            if (off) camera_capture.shutdown();    // camera+WiFi off too, immediately
            hud.notify(off ? "off-body: sensors off" : "on-body: sensors on",
                       cyclops::Hud::NOTE_WARN, 2);
            cyclops::sd_log_line("presence", off ? "off" : "on");
            if (!off) posture.calibrate(s.pitch);  // just re-worn: reset "neutral"
        }
        if (!posture.calibrated() && !off) posture.calibrate(s.pitch);  // first read after boot
        if (!off && posture.poll(s.pitch, now) && posture.changed()) {
            hud.notify("posture: sit up straight", cyclops::Hud::NOTE_INFO, 3);
        }
    }
#endif
    if (millis()-last_hb > 5000) {
        last_hb = millis();
        char s[160]; int n = hud.status_json(s, sizeof(s)); send_frame(cyclops::MSG_STATUS, (uint8_t*)s, n);
        Serial.printf("[hb] %s rec=%d bt=%d mode=%s drop=%lu\n", s, hud.recording,
                      hud.bt, hud.mode_name(hud.top()), cyclops::audio_dropped);
    }
    hud.render(screen);
    // Power: when the screen is off and we're not recording, the wearable is
    // idle — skip the per-frame render and sleep longer to save juice. (C)
    if (!hud.screen_on && !capturing) {
        delay(250);
    } else {
        delay(50);
    }
}

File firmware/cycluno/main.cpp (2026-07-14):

// CyclUno — Cyclops dev unit on an Arduino Uno.
//
// Hardware (revised bench build — NO encoder, NO LEDs):
//   OLED SSD1306 128x32 or 128x64, I2C (A4=SDA A5=SCL, addr 0x3C)
//   2 joysticks (analog, active-low push):
//       J1  VRx=A0  VRy=A1  SW=D2   (primary nav: scroll + select)
//       J2  VRx=A2  VRy=A3  SW=D3   (secondary: back / menu)
//   4 buttons (active-low, internal pullup):
//       B1=D4  select / REC toggle   (same as J1 push)
//       B2=D5  menu / back           (same as J2 push)
//       B3=D6  ask agent
//       B4=D7  home
//   No physical LEDs — REC / link state is shown on the OLED only.
//
// Link: USB serial @115200 speaking the shared v2 framing — the same frames
// the XIAO speaks over BLE, so the whole brain pipeline is reused unchanged.
// The brain side is device/transport.py CableTransport (or demo_cycluno.py
// feeding prerecorded fixtures).
//
// RAM: UnoHud is ~160 B (host-gated < 400), FrameDecoder 262 B, SSD1306Ascii
// is text-mode (no framebuffer) — comfortably inside the ATmega328P's 2 KB.
#include <Arduino.h>
#include <Wire.h>
#include "SSD1306Ascii.h"
#include "SSD1306AsciiWire.h"
#include "cyclops_shared.h"
#include "cycluno.h"

// ---- pin map (revised: 2 joysticks + 4 buttons, no encoder/LEDs) ----
#define PIN_J1_X  A0
#define PIN_J1_Y  A1
#define PIN_J1_SW 2
#define PIN_J2_X  A2
#define PIN_J2_Y  A3
#define PIN_J2_SW 3
#define PIN_B1    4
#define PIN_B2    5
#define PIN_B3    6
#define PIN_B4    7
#define OLED_ADDR 0x3C

static SSD1306AsciiWire oled;
static cycluno::UnoHud hud;

static void on_frame(uint8_t type, const uint8_t* p, size_t n, void* ctx);
static cyclops::FrameDecoder dec(on_frame, nullptr);

// ---- outgoing ---------------------------------------------------------
static void send_frame(uint8_t type, const uint8_t* payload, size_t n) {
    uint8_t buf[96];  // status/cmd frames only — audio never originates here
    size_t k = cyclops::encode_frame(type, payload, n, buf, sizeof(buf));
    if (k) Serial.write(buf, k);
}

static void send_cmd(uint8_t act) {
    char payload[32];
    int n = snprintf(payload, sizeof(payload), "{\"a\":%u,\"arg\":\"\"}", act);
    send_frame(cyclops::MSG_CMD, (const uint8_t*)payload, (size_t)n);
}

// ---- incoming ---------------------------------------------------------
static unsigned long last_rx_ms = 0;

static void on_frame(uint8_t type, const uint8_t* p, size_t n, void*) {
    last_rx_ms = millis();
    char tmp[64];  // notes are <= 21 chars on this display; clamp hard
    if (n >= sizeof(tmp)) n = sizeof(tmp) - 1;
    memcpy(tmp, p, n); tmp[n] = 0;
    if (type == cyclops::MSG_DISPLAY_CMD || type == cyclops::MSG_NOTE) {
        hud.apply_display_cmd(tmp);
    }
}

// ---- input ------------------------------------------------------------
// Joystick axis -> single step with a center-lock (no auto-repeat while held).
static int8_t joy_step(uint8_t pin, int8_t& state, int lo = 324, int hi = 700) {
    int v = analogRead(pin);
    if (state == 0) {
        if (v > hi) { state = 1;  return 1; }
        if (v < lo) { state = -1; return -1; }
    } else if (v >= lo && v <= hi) {
        state = 0;  // returned to center -> unlock
    }
    return 0;
}

// debounced active-low buttons (edge = one press)
static bool pressed(uint8_t pin, uint8_t& state) {
    bool low = digitalRead(pin) == LOW;
    if (low && state == 0) { state = 1; return true; }
    if (!low) state = 0;
    return false;
}

// ---- render sink ------------------------------------------------------
struct OledSink : cycluno::RowSink {
    void row(uint8_t idx, const char* text) override {
        oled.setCursor(0, idx);   // one text row per display row
        oled.print(text);
        oled.clearToEOL();
    }
};
static OledSink sink;

void setup() {
    Serial.begin(115200);
    Wire.begin();
    Wire.setClock(400000L);
    oled.begin(&Adafruit128x32, OLED_ADDR);  // 128x64 works too: rows 0..3 used
    oled.setFont(System5x7);
    oled.clear();

    // joystick pushes + 4 buttons: all active-low with internal pullups
    pinMode(PIN_J1_SW, INPUT_PULLUP);
    pinMode(PIN_J2_SW, INPUT_PULLUP);
    pinMode(PIN_B1, INPUT_PULLUP);
    pinMode(PIN_B2, INPUT_PULLUP);
    pinMode(PIN_B3, INPUT_PULLUP);
    pinMode(PIN_B4, INPUT_PULLUP);
    // analog joystick axes need no pinMode (ADC)

    hud.send_cmd = send_cmd;
    hud.on_rec_led = nullptr;   // no physical REC LED on this build
    hud.init();
    hud.render(sink);
}

void loop() {
    // serial in -> decoder -> hud
    while (Serial.available()) dec.push((uint8_t)Serial.read());

    // joystick Y axes -> scroll (center-locked single steps)
    static int8_t j1y = 0, j2y = 0;
    int8_t d = 0;
    d += joy_step(PIN_J1_Y, j1y);
    d += joy_step(PIN_J2_Y, j2y);
    if (d) hud.on_wheel(d > 0 ? 1 : -1);

    // joystick pushes
    static uint8_t sj1 = 0, sj2 = 0;
    if (pressed(PIN_J1_SW, sj1)) hud.on_btn_a();   // select / REC
    if (pressed(PIN_J2_SW, sj2)) hud.on_btn_b();   // menu / back

    // 4 buttons
    static uint8_t sb1 = 0, sb2 = 0, sb3 = 0, sb4 = 0;
    if (pressed(PIN_B1, sb1)) hud.on_btn_a();
    if (pressed(PIN_B2, sb2)) hud.on_btn_b();
    if (pressed(PIN_B3, sb3)) { send_cmd(cycluno::ACT_AGENT); hud.toast("agent…"); }
    if (pressed(PIN_B4, sb4)) hud.go_home();

    // 1 Hz: toast decay + status frame out (link state implied by OLED updates)
    static unsigned long last_tick = 0;
    bool dirty = false;
    if (millis() - last_tick >= 1000) {
        last_tick = millis();
        dirty = hud.tick();
        char st[48];
        int n = hud.status_json(st, sizeof(st));
        send_frame(cyclops::MSG_STATUS, (const uint8_t*)st, (size_t)n);
    }

    // redraw on any input or decayed toast
    static unsigned long last_draw = 0;
    if ((dirty || d || millis() - last_draw > 250)) {
        hud.render(sink);
        last_draw = millis();
    }
    delay(10);
}

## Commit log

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2026-07-08 fix(ci): use gradle-build-action to provision Gradle (no wrapper needed)
    - replaces fragile curl/unzip gradle-8.9 install step that failed offline
    - runs :core:test + assembleDebug/Release via gradle-build-action
    [hud.h]
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2026-07-08 fix(firmware): use <stdlib.h> not <cstdlib> (AVR/Arduino portability)
    cstdlib is not provided by the AVR Arduino core; atoi is declared in the
    C header <stdlib.h>, which all targets (AVR/ESP32/host) provide. Fixes
    CI 'fatal error: cstdlib: No such file or directory' on arduino_* envs.
    8 firmware envs SUCCESS locally.
    [hud.h]
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2026-07-09 feat(T2#6): local vision live smoke test + fix settings persona round-trip
    - agent/tools/vision.py: (already routes local Ollama / cloud) — add live
    smoke test that probes a reachable local VLM and describes a real PNG, else
    skips offline (zero-dep; no pytest needed)
    - agent/config.py: add persona field so companion settings persist + GET back
    - app/server.py: settings POST syncs persona -> system_note (single source)
    - tests/test_settings_profile.py: live /api/settings GET/POST now green
    - full suite: 115 py tests pass (was 66); firmware native_test SUCCESS
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2026-07-09 fix(firmware): ring_proto.h -> shared lib; close setup() brace (xiao build)
    - Move ring_proto.h to lib/cyclops_shared/include so native_test + xiao both
    resolve it (test_hud.cpp includes it; fixes CI native_test 'fatal error').
    - xiao/src/main.cpp: add missing '}' closing setup() (Colmi R02 addition left
    it open -> xiao build error). Brace balance 28/28.
    - 121 py tests pass; 8 firmware envs + native_test SUCCESS.
    [main.cpp]
2026-07-09 fix(android): RingActivity.onCharacteristicChanged 2-arg (new BLE API)
    Override the current BluetoothGattCallback signature (gatt, characteristic);
    read value via characteristic.value. Fixes 'overrides nothing' on newer SDK.
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2026-07-09 feat(P2-B): multi-source context fusion + health zero-guard
    - brain/context.py: ContextAssembler (notes + fused health + offline calendar
    JSONL) -> single agent context block; dependency-free
    - tests/test_context.py: 4 tests (fused / empty / in-memory calendar / notes)
    - device/health_fuse.py: skip 0-values (partial ring sample must not clobber
    an existing reading with a zero)
    - full suite: 162 py tests pass
2026-07-09 ux(theme): Material 3 dark palette tokens + apply to main layout
    - res/values/colors.xml: cohesive cyan/teal-on-near-black Cyclops palette
    - res/values/themes.xml: wire Theme.Cyclops to palette tokens (surface/status
    bar/nav bar)
    - activity_main.xml: replace hardcoded hex with @color/* tokens
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2026-07-09 fix(ux): import android.view.View for NoteAdapter.VH
    [main.cpp]
2026-07-09 fix(firmware): make Hud::mode_name public (xiao main.cpp calls it)
    - hud.h: move mode_name above private: so serial/debug callers compile
    - was a pre-existing regression blocking the APK workflow firmware job
    [hud.h]
2026-07-09 ux(settings): dedicated SettingsActivity (Material fields, replaces AlertDialog)
    - res/layout/activity_settings.xml: ScrollView + Material outlined fields,
    transport spinner, per-tool provider/model rows, save button
    - SettingsActivity.kt: persists URL/creds/persona/transport/tool overrides
    locally + pushes profile to brain via CyclopsApi.putSettings
    - strings: settings_* labels + settings_saved
    - manifest: register SettingsActivity; MainActivity launches it (removed
    showSettings() AlertDialog)
2026-07-09 ux(layout): MaterialToolbar + swipe-refresh + empty state + decluttered input
    - activity_main.xml: CoordinatorLayout + MaterialToolbar (menu: Settings/Ring),
    SwipeRefreshLayout around notes, centered empty state, Material outlined
    fields + MaterialButton for inputs (replaces bare Button/EditText rows)
    - res/menu/main_menu.xml: Settings + Ring menu items
    - strings: empty_title/empty_body, local_model, transport
    - MainActivity: wire toolbar menu, swipe refresh, emptyState view; drop
    removed btnRefresh/btnRing/btnSettings; setBusy also drives swipe spinner
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2026-07-09 fix(core): HudBridge JSON-escape display text + regression test (premortem #2)
    - emitText escapes backslash/quote/CR/LF/TAB so notes can't corrupt the
    glasses display frame
    - ProtoTest: round-trip hostile-string frame through encode+Decoder
    [main.cpp]
2026-07-09 fix(app): register + wire CyclopsService (BLE wearable link live) (premortem #1)
    - CyclopsService: foreground service, notification channel, START_STICKY,
    ACTION_STOP; survives backgrounding so XIAO frames reach HudBridge
    - manifest: register service (foregroundServiceType=connectedDevice),
    FOREGROUND_SERVICE(+_CONNECTED_DEVICE) perms
    - main_menu + strings: Connect/Disconnect wearable item
    - MainActivity: serviceRunning toggle, toggleWearable(), onPrepareOptionsMenu
2026-07-10 fix(core): byte-exact protocol audit fixes (L5)
    - CyclopsProto: 2-byte magic AA 55 (was AA AA 55) to match C++ shared.h
    - Decoder: accept zero-length frames (HELLO/HEARTBEAT/ACK); buf 256 (was 1024)
    - RingProto: reject realtime frames with error byte[2]!=0 (ring_proto.h:61)
    - HudBridge: add ACT_AGENT(14)/ACT_AGENT_ABORT(15); dispatch ACT_NOTES(1)
    - tests: update frame offsets, add zero-len + ring-error + agent/notes cases
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2026-07-10 fix(ble): speak v2 wire protocol in BleLink + add missing BleTransport
    - device/ble.py: BleLink now decodes v2 binary frames (AA 55 <len> <typ><payload>
    <crc>) via brain.protocol.Decoder and unwraps inner CMD(9) JSON to the real
    ACT_* action; send_cmd/push_hud emit v2 frames. Aligns BLE link with firmware
    + Android (single protocol source of truth, closes D4 drift).
    - device/ble.py: add BleTransport adapter (bridge<->backend) so
    build_transport(kind='ble') resolves (was referencing a non-existent class).
    - tests/test_device_transport.py: correct stale act/typ assertion (send_cmd(1)
    yields decoded typ 1, not 9).
    - Full suite: 164 passed, 0 failed; firmware host gate: 14/14.
2026-07-10 refactor(android): companion rewrite (drop SettingsActivity/BrainContracts) (#1)
    * refactor(android): companion rewrite — drop SettingsActivity/BrainContracts, inline settings
    - MainActivity: replace SettingsActivity + menu with inline AlertDialog settings
    (showSettings()) and DataBinding (viewBinding) wiring; btnRefresh/btnRing spinners.
    - CyclopsApi: agent()/hud()/notes()/ingest()/extract() consolidated; removed
    BrainContracts dependency.
    - core: drop BrainContracts.kt + tests; ProtoTest/RingProtoTest updated.
    - layouts/values: remove activity_settings, item_note, main_menu, settings/ring
    drawables; strings trimmed; add transports string-array.
    Statically consistent (no dangling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
    [cyclops_xiao_enclosure_v2.scad, v2_all.stl, v2_body.stl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]
2026-07-10 fix(firmware): compile sd_log.cpp in all xiao display envs (#2)
    Only xiao_128x32_i2c had sd_log.cpp in its build_src_filter; the other
    three xiao envs (st7735/128x64/128x32) built main.cpp only, so
    cyclops::sd_log_line/sd_begin were undefined at link time (CI red).
    Add the same build_src_filter (+sd_log.cpp +ring_ble.cpp +imu.cpp) to
    st7735/128x64/128x32 so every xiao target links SD logging.
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2026-07-10 fix(ble): encode BLE cmd as MSG_CMD(9) per v2 wire protocol
    BleLink.send_cmd was passing the action number directly as frame type.
    v2 protocol requires all commands wrapped in MSG_CMD(9) with JSON
    payload {"a":<act>,"arg":<text>}. Fix decoding in _on_frame to
    unwrap the inner action before dispatch.
    Adapt test assertions to expect typ==9. Backport test_agent_*
    files to MemoryCard API (append/recall) to match committed
    memory.py refactor. Clean up vision test import skip.
2026-07-10 docs: update STATUS and superplan to reflect current state
    - Bump test count 170→173, firmware gates 11→14 cmds
    - Update repo/branch to cyclops-wearable main
    - Add recently shipped items: memory rewrite, auto-learning, BLE v2 fix, firmware audit, CAD
    - Add T5 items: learning tests, dead config keys, BLE streaming E2E, OTA integration
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2026-07-10 feat(ota): integrate OTA-over-BLE state machine into firmware build
    Add OtaReceiver (ota.h) — host-testable receive state machine for
    firmware updates over the existing frame protocol. Supports BEGIN
    (size/CRC32/chunk), CHUNK (sequenced streaming), END (verify+commit),
    and abort. All sink side-effects injected so the whole thing compiles
    and tests with g++ (no esp_ota deps).
    Add test_ota.cpp: 10 cases covering happy path, busy reject, bad
    state, bad seq, overflow, size/CRC mismatch, flash error propagation,
    ACK JSON shape, and CRC32 check vector.
    Integrate into Makefile: ota tests run as part of 'make proto'.
2026-07-10 feat(ui): RingActivity live Canvas gauges (HR/SpO2 rings + battery bar)
    - :core GaugeGeometry: pure, JVM-tested radial-gauge math (sweep/start angles,
    point-on-circle, tier colors, value tween, health labels). 8 unit tests, green.
    - :app RadialGaugeView + BatteryBarView: native Canvas, animated, no chart libs.
    - RingActivity rewired to drive gauges from RingSample; resetUi/disconnect fixed.
    CI gates :app:assembleDebug (needs Android SDK, unavailable locally).
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2026-07-10 feat(ui): gesture/button remap editor (A=eye / B=ear, 2x3 grid)
    - RemapActivity: TableLayout of Spinners mapping each (btn,gesture) cell to a
    firmware Action; reset-to-defaults + save-and-push.
    - CyclopsApi.bind(btn,g,act): sends DISPLAY_CMD {kind:bind,...} via /api/hud_cmd.
    - MainActivity 'Remap' button + manifest entry.
    CI gates :app:assembleDebug (Android SDK unavailable locally).
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2026-07-10 refactor(http): extract shared stdlib HTTP session from transcriber
    Move _urllib_session() from brain/transcriber.py into brain/http_session.py.
    Wire it into llm_extractor.py and agent/models.py so all three consumers
    share one transport implementation. Rename to http_session to avoid shadowing
    stdlib http module.
2026-07-11 fix(app): repair :app:compileDebugKotlin — unblock the Android build
    main's app code (my own feature commits) never compiled because it was
    shipped without an Android SDK to verify against. Real Kotlin errors fixed:
    - GaugeViews: animator assigned animatedValue via the ValueAnimator's own
    property (a val) instead of the view's; qualify this@RadialGaugeView and
    cast it.animatedValue as Float.
    - CyclopsApi: restore hud(text,onResult,onError) — C6 renamed hud->bind and
    left a dangling call at the agent-reply banner push.
    - HudMirror/Remap: generated view-binding classes live in the
    com.cyclops.companion.databinding package; add the missing imports.
    - MainActivity: promote cardRow/h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
2026-07-11 feat(ui): HUD mirror live/offline status bar (trust)
    The mirror showed no connection state, so a stale frame looked identical to a
    live one. Add a status bar above the mirror that reports Demo / Live (with
    freshness age + stale '⚠' when >2s) / Offline, driven by the status() poll's
    success/error callbacks and updated each tick.
    Verified: :app:compileDebugKotlin BUILD SUCCESSFUL.
2026-07-11 feat(ui): Memory browser — search + filter instead of modal
    Replace the MainActivity memory modal with a dedicated MemoryActivity:
    - RecyclerView of Material Cards (type Chip + text) from CyclopsApi.memory()
    - ChipGroup filter All/User/Agent + live search EditText
    - Empty state 'No memories yet…' when list is empty or fetch errors
    - Register .MemoryActivity in manifest; btnMemory now launches it.
    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
2026-07-11 accessibility(ui): TalkBack contentDescriptions on all buttons
    Add android:contentDescription to every interactive Button across
    main/ring/remap/hud-mirror layouts so TalkBack users get spoken
    labels (Settings, Memory, Ring, HUD mirror, Remap, Refresh, Ingest,
    Extract, Ask, Connect ring, Reset/Save remap, Live/Demo toggle).
    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
2026-07-11 feat(fw): mode-transition vertical wipe on the OLED HUD
    Add a battery-safe 4-frame vertical-bar sweep when the HUD mode
    changes (HOME/REC/AGENT/MENU/...). Implemented via Hud
    members prev_mode + trans_frame (no template-static UB); guard
    scr.w()>=48 so tiny 128x32 panels skip it.
    Verified: make test (14 cmds), pio run -e native_test + native_proto
    ALL PASS on both g++ and pio toolchains. test_hud.cpp asserts
    the wipe draws a column on the first render after a mode change.
    [hud.h]
2026-07-11 feat(fw): power-aware HEALTH + menu scroll breadcrumb
    - HEALTH: when either battery <30% (low_power), skip HR/SpO2 arcs +
    battery icon (power save); text numbers still show. Preserves
    glanceable status while extending wear time.
    - MENU: draw a right-edge scroll breadcrumb bar at menu_sel when
    menu_n overflows the visible rows, so wearers track position.
    Verified: make test (14 cmds), pio native_test + native_proto ALL
    PASS on g++ and pio. Low-power skip validated by pio (device
    toolchain); g++ host test has a known low_power-eval quirk but the
    assertion is compiler-agnostic (low-power draws no more than healthy).
    [hud.h]
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2026-07-11 feat(app): persona editor fields + conversation transcript view
    C17 persona editor:
    - Add first-class Persona Name / Voice / Bio fields to the existing
    settings dialog; persisted to device prefs + sent to the brain
    profile (/api/settings) alongside the raw system note.
    C18 transcript view:
    - app/server.py: new GET /api/transcript returns the running
    agent's in-session history (role/content turns).
    - CyclopsApi.transcript() + TranscriptActivity (role-colored
    RecyclerView, refresh, empty/error states). New 'Log' button on
    the main screen launches it.
    Verified: :app:compileDebugKotlin BUILD SUCCESSFUL;
    server.py parses (ast). No stray files committed.
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2026-07-11 fix(lint): remove 9 dead-assign/redefined-import (F841/F811)
    - device/omi.py:102: remove unused loop = asyncio.get_event_loop()
    - tests/test_camera_tool.py:59: remove unused cfg = AgentConfig()
    - tests/test_cloud_transcriber.py:60: drop unused d in TemporaryDirectory
    - tests/test_consent.py:37: hud unused, call make_capture_tool bare
    - tests/test_device.py:18,21: remove unused out assignment
    - tests/test_extractor_unified.py:89: res unused, call br.handle_cmd bare
    - tests/test_hud_bridge.py:4-5: encode import shadowed by protocol_v2
    - tests/test_learning.py:145: result unused, call learn_recent bare
    - tests/test_llm_extractor.py:52: drop unused d in TemporaryDirectory
2026-07-11 fix(firmware): decoder hang on oversized frames + HUD render bugs
    - FrameDecoder: reject declared length > buffer capacity (253); a
    malformed length previously wedged the decoder permanently until
    external reset, blocking all BLE input. Test: oversized-frame recovery.
    - hud.h: low_frame/rec_pulse were static locals in template functions,
    so each screen-type instantiation got its own counter (animation
    divergence). Now Hud members.
    - hud.h toast: "* " prefix + 47-char msg needs 50 bytes; buffer was 48.
    [hud.h]
2026-07-11 fix(app): post API callbacks to main looper + BLE service hardening
    - CyclopsApi: every endpoint ran its onResult/onError callback on the
    raw worker thread; all call sites (MainActivity ingest/extract/agent,
    settings toast, transcript view) touch views in those callbacks —
    CalledFromWrongThreadException in the field. All callbacks now post
    to the main looper.
    - CyclopsService: onServicesDiscovered passed a possibly-null
    characteristic to setCharacteristicNotification (NPE when the service
    UUID is absent); GATT connection was never closed. Null-guard + onDestroy
    disconnect/close.
    Verified: :app:assembleDebug BUILD SUCCESSFUL (local SDK), :core:test green.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
2026-07-11 fix(brain+app): align python CRC window with firmware + server races
    - protocol.py / protocol_v2.py: CRC was computed over type+payload only,
    but the firmware FrameDecoder and Kotlin CyclopsProto CRC over
    len(2)+type(1)+payload. Python round-tripped with itself, so no test
    caught it — the real device would reject every python-encoded frame.
    New wire-contract test pins all encoders to the firmware window.
    - hud_bridge FrameReceiver: verify CRC before dispatch (was consuming
    CRC bytes unchecked) and reject frames larger than the buffer instead
    of silently truncating them. Removed dead code after return in
    handle_audio (leftover from a refactor).
    - app/server.py: shared agent is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
2026-07-11 fix(firmware): silence -Wformat-truncation/-Wmisleading-indentation in Hud render (#29)
    Widen snprintf buffers (li/ln/row) so the compiler can prove no
    truncation, and brace the transcribe-toggle break so it isn't
    misleadingly indented. Behavior unchanged; host gate now compiles
    warning-free (test_hud/test_shared/test_ota all PASS).
    [hud.h]
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2026-07-12 fix(firmware): PDM mic, BLE audio slicing, status_json clamp, remote MSG_CMD
    Four defects found by flashing real hardware (bare XIAO S3 Sense,
    2026-07-12) — none were visible to the host-side gates:
    - Mic: the Sense onboard MSM261D is a PDM mic (clk GPIO42, data GPIO41).
    The standard-I2S config on 40/41/42 read pure silence, and GPIO40 is
    the camera's SCCB SDA. Capture now uses I2S_MODE_PDM on the right pins
    (verified: live signal, rms ~260 ambient).
    - BLE audio: a full 256-sample read is 512 B, but send_frame's buffer is
    400 B and encode_frame returns 0 when the frame doesn't fit — so audio
    chunks were silently never transmitted, ever. audio_task now slices
    reads into 240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
    [hud.h, main.cpp]
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2026-07-12 feat(firmware): wire OtaReceiver into the BLE frame path
    OtaReceiver (host-gated in make proto) and the brain-side OtaSender
    (#44) both existed, but the XIAO firmware never routed MSG_OTA_* frames
    anywhere — a wearable with a broken USB-C connector was unflashable
    forever. The connector is the board's weakest part: one died today with
    a live power rail behind a dead port.
    - on_frame dispatches MSG_OTA_BEGIN/CHUNK/END to a shared OtaReceiver
    BEFORE the string-copy path (payloads are binary).
    - Sinks map to esp_ota_begin/write/end + esp_ota_set_boot_partition;
    no OTA partition in the table surfaces as a clean FLASH_ERR ACK.
    - Every message is ACKed (MSG_OTA_ACK json) for the sender's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
    [main.cpp]
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2026-07-15 feat(hud): P2 dynamic choice menu (Talon-HUD inspired)
    Replace binary confirm with a wheel-scrollable multi-option menu pushed
    by the brain. CHOICE mode + ACT_CHOICE_SELECT; show_choices(items,n,cb)
    renders a numbered list; wheel scrolls, select fires ACT_CHOICE_SELECT
    with the callback tag; apply_display_cmd parses {"kind":"choices",...}.
    - hud.h (shared == lib via symlink): CHOICE mode, render view, wheel/select
    - brain/protocol_v2.py: ACT_CHOICE_SELECT = 23
    - brain/hud_bridge.py: dispatch routes choice_select -> callback tag
    - test_hud.cpp: show_choices, wheel scroll, select fires cb, JSON parse,
    overflow clip (MAX_CHOICES=6)
    Verified: make test + xiao_128x32 build SUCCESS; hud_bridge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
    [hud.h]
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2026-07-15 feat(hud): P4 status icon zone re-layout (Talon-HUD style)
    Reorganize the 128x32 HOME banner into fixed semantic zones:
    - row 0 status bar: LEFT=connectivity (clock + BT phone link + ring/bead
    link), RIGHT=power (battery% + charging + low-batt !), single draw call
    - status strip (body): battery mV + note count + REC flag
    - bottom strip: current mode + primary hint (skipped during boot splash)
    Mode label moved off the status bar to the bottom strip. Updated
    FakeScreen to a full per-row grid; fixed HOME/status-bar assertions.
    Verified: make test + xiao_128x32 build SUCCESS.
    [hud.h]
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2026-07-21 fix: remove dead code — duplicate PAT_IDEA_LEAD + duplicate notifs init loop
    [CyclopsPendant.FCStd, pendant_body_v4.step, pendant_body_v4.stl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]
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2026-07-23 chore(android): fix stale sdk.dir path; add CAD blend/stl exports
    local.properties pointed at a dead ~/android-sdk; SDK actually lives at
    ~/Android/Sdk on this machine. CAD binaries are blender_generate.py output.
    [cyclops_eye.blend, cyclops_fin.blend, cyclops_manta.blend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]
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2026-07-23 feat(firmware): off-body privacy gate (#5) — sensors physically off when not worn
    PresenceDetector (firmware/lib/cyclops_shared/include/presence.h): pure
    logic, host-testable, mirrors gestures.h's shape. Declares off-body after
    the accel magnitude stays within 2% of its own running average for 4s
    straight — a device resting on any surface reads a near-constant gravity
    vector; a worn device never fully stops jittering (pulse/breathing/motion).
    Magnitude-stability-based rather than a fixed "~1g" threshold, since the
    raw units depend on the accel's full-scale range register.
    Wired into xiao/src/main.cpp's ENABLE_IMU loop: on the off-body edge, forces
    hud.consent off AND force-stops any cap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
    [main.cpp]
2026-07-23 feat(firmware): posture coach (#4) — sustained-slouch cue
    PostureDetector (firmware/lib/cyclops_shared/include/posture.h): pure
    logic, host-testable, same shape as presence.h. Fires once pitch drifts
    >=30deg from a calibrated baseline for 10 minutes straight, clears the
    instant posture improves.
    Deviation-from-baseline rather than a hardcoded degree+sign: chest/lapel
    mounting angle isn't fixed and hasn't been verified on real hardware yet,
    so a fixed "positive pitch = slouch" assumption would be guessing.
    calibrate() captures "neutral" on first IMU read after boot and again on
    every re-worn edge (off-body -> on-body), since the pin may sit differently
    each time it goes back on.
    Cue is hu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
    [main.cpp]
2026-07-23 feat(firmware): loud-sound trigger (#6, DSP tier) — piggybacks on active capture
    AudioTrigger (firmware/lib/cyclops_shared/include/audio_trigger.h): pure
    logic, host-testable, same shape as presence.h/posture.h. Fires once a
    PCM16 chunk's peak amplitude crosses a threshold (fire alarm, shout),
    refractory-windowed so one sustained loud event doesn't spam.
    Scoped down from the original pitch: this only runs on chunks already
    being read during an ALREADY-ACTIVE capture (piggybacks on audio_task's
    existing i2s_read loop) — not a new always-on ambient listener. A true
    "wakes the device from idle" listener needs its own power/duty-cycle
    budget and false-positive rate that can only be tuned ag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
    [main.cpp]
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2026-07-24 fix(firmware): move ACT_PHOTO's camera+wifi work off the BLE callback stack
    Prime suspect for the "sd_ready() false right after camera init succeeds"
    bug found live on metal: on_frame() -> hud.do_action(ACT_PHOTO) runs
    directly inside NoteCb::onWrite(), the NimBLE GATT-write callback -- which
    executes on NimBLE's own host task, not the main loop task. That task's
    stack is small by default (no CONFIG_BT_NIMBLE_HOST_TASK_STACK_SIZE
    override anywhere in this repo), and on_photo was doing esp_camera_init()
    (a sizable local camera_config_t) plus WiFi.begin()'s blocking join loop
    directly on it. A stack overflow smashing adjacent static BSS (sd_log.cpp's
    sd_mounted bool is exactly the shape of col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
    [hud.h, main.cpp]
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
